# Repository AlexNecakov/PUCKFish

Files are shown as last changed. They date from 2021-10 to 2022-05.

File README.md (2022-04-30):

## Welcome to PUCKFish!
Design Team: Will Aracri, Peter Ha, Ammar Hussain, Alex Necakov, Victoria Thomas
### Please view our [wiki](https://github.com/AlexNecakov/PUCKFish/wiki) for more information, including the hardware and software READMEs!

## Introduction
PUCKFish is an underwater array of sensors meant to characterize underwater environments by sensing important information, designed for the 2021-2022 senior design project at Boston University. Originally designed to track lobsters, this device measures pressure, temperature, dissolved oxygen levels, ambient light, salinity and current speed as well as direction. The system is fully waterproof and meant to survive pressures found at a depth of around 1000 feet and survive for 10 days without a recharge. Data collection begins automatically after submersion and transmits the data collected to a base station via radio. PUCKFish can be built on a budget of around $150. This document will walk you through the PUCKFish design project, tips, and lessons learned. This document will also point you to other areas on the Github for more information about the relevant subsystems.

## Design Process
The architecture of PUCKFish optimized for two priorities, cost and survivability. From these priorities, three major challenges were identified.

1. PCB and Electronics Design: Any electronics used must have low-current draw. Electronics must also be recharged without introducing a risk of water-intrusion. Any sensors used must be low-cost.
2. Sensing Current Speed and Direction: Any method used to measure current speed and direction must be robust and simple.
3. Enclosure Design: Enclosure must be able to protect against high-pressure environments as well as protect electronics from saltwater intrusion.
Any design change should carefully consider these challenges and decide on the appropriate trade offs to achieve survivability and a low cost.

## PCB and Electronics Design
PUCKFish must read 6 different metrics from onboard sensors, store the data locally, transmit the data to a shipboard, and be rechargeable. Our software is written in C using the Arduino Framework and can be easily installed, modified, built and uploaded following instructions found on the [Software Overview](https://github.com/AlexNecakov/PUCKFish/wiki/Software-Overview) page of our wiki. Our main software can be found in the [/FlagpoleClient](https://github.com/AlexNecakov/PUCKFish/tree/master/FlagpoleClient) directory. Our electronics hardware consists of several sensors, a LiPo battery, SD card, and Adafruit Feather M0 with LoRa radio to control the system/broadcast data over the LoRa 900 mHz frequency. All of these components were put together on a custom PCB designed in Eagle. The PCB currently lacks a location for the SD card and Dissolved Oxygen sensor to be includeded, and should be added in future versions of this project. Information about our hardware, including sensor vendor links and specifications, data sheets, and renders of our PCB layouts can be found on the [Hardware Overview](https://github.com/AlexNecakov/PUCKFish/wiki/Hardware-Overview) wiki page. PCB project information can be found in the [/PCB/Eagle Project](https://github.com/AlexNecakov/PUCKFish/tree/master/PCB/Eagle%20Project) directory.

PUCKFish uses Qi wireless charging in order to replenish the battery. Using wireless charging eliminates the possibility of water-intrusion or corroded charging leads. 

PUCKFish uses several sensors to collect data. Information on the sensors may be found in the [Hardware Overview](https://github.com/AlexNecakov/PUCKFish/wiki/Hardware-Overview) page and the software mounted on them may be found in the [Software Overview](https://github.com/AlexNecakov/PUCKFish/wiki/Software-Overview) page. These sensors were selected due to price, power draw, supply voltage, measurement range, and waterproof capabilities.

PUCKFish uses a LoRa capable radio to transmit data over the 900 mHz frequency in JSON formatted packets. This radio is mounted to the Feather Board and begins sending the data once the PUCKFish has surfaced from the ocean. For more information on the radio, see the [Hardware Overview](https://github.com/AlexNecakov/PUCKFish/wiki/Hardware-Overview) page for the specifications of the hardware and the [Software Overview](https://github.com/AlexNecakov/PUCKFish/wiki/Software-Overview) page for the software that is used to collect/transmit the data.

Several sensors require access to the water to measure their respective characteristics. The pressure sensor uses a -08 O-ring to attach a vinyl tube which then leads to the exterior while pouring the epoxy. The salinity sensor uses two wire leads that sense the current produced between them, which then calculates the salinity. These wire leads must be exposed when pouring the epoxy. The dissolved oxygen sensor contains a galvanic probe. This probe must be prepped with a chemical provided from the sensor manufacturer. This probe must also be exposed while pouring the epoxy. As discussed below, silicone mold has a hole that these sensors can be routed through to ensure they will have access to water after the epoxy is poured.

## Sensing Current Speed and Direction
PUCKFish uses an IMU to measure current speed and direction. As PUCKFish is sphere, its position in the water heavily impacts the orientation and current data that is collects. Other methods of measuring current, like weather vanes or flow tubes, are too delicate and are unable to operate for long periods underwater with any degree of reliability. The design of PUCKFish’s enclosure can be found below. Information about the IMU implementation can be found in the wiki in both the [Hardware Overview](https://github.com/AlexNecakov/PUCKFish/wiki/Hardware-Overview) and [Software Overview](https://github.com/AlexNecakov/PUCKFish/wiki/Software-Overview) pages.

## Enclosure Design
PUCKFish uses a 3D Printed skeleton to hold electronic components and is encased within an epoxy shell. Sensors that need access to the water protrude from the epoxy shell in order to successfully measure the required components.

The 3D printed skeleton is the product of several steps of iteration to fit the PCB and accommodate the Qi wireless charging receiver. Once the skeleton is printed on an FDM printer with ABS filament, it requires no extra manufacturing steps. Inserting the PCB is simple as the skeleton was sized specifically to accommodate this element. For more information on the 3D printed skeleton, view relevant documentation in the [Hardware Overview](https://github.com/AlexNecakov/PUCKFish/wiki/Hardware-Overview) page.

The epoxy shell was developed specifically with survivability and cost in mind. Metallic or plastic structures containing the electronics introduce the problem of seams connecting the devices. In each of these cases, expensive manufacturing techniques, as well as complex sealing procedures, are damaging to both cost and survivability. Manufacturing the epoxy shell requires a series of two molds to form, one mold that forms the final silicone form, and the final silicone form that creates the epoxy shell. It is essential that the silicone mold is used to form the epoxy casing, as 3D printed molds are too porous for the epoxy to form in and other machined elements are too costly to make. To find the mold’s as well as the mold making process, go to the [Hardware Overview](https://github.com/AlexNecakov/PUCKFish/wiki/Hardware-Overview) page or find the relevant CAD models [/Structure Cad](https://github.com/AlexNecakov/PUCKFish/tree/master/Structure%20CAD) directory.

## Manufacturing PUCKFish
For a general description of how to manufacture PUCKFish follow the instructions below.
1. First, populate the PCB with the required components as shown in the [Hardware Overview](https://github.com/AlexNecakov/PUCKFish/wiki/Hardware-Overview)
2. Build and upload the FlagpoleClient program to the Feather Board as described in the [Software Overview](https://github.com/AlexNecakov/PUCKFish/wiki/Software-Overview)
3. 3D print the PCB skeleton for the electronics.
4. 3D print the silicone mold molds.
5. Pour the silicone molds for epoxy. 
6. Install the populated PCB into the 3D printed skeleton
7. Install the aluminum block into the top of the 3D printed skeleton with epoxy
8. Screw in the eyebolt to the aluminum block.
9. Install the 3D printed skeleton with populated PCB into the silicone mold, with the eyebolt pointed through the mold.
10. Pour epoxy into the silicone mold in three parts. DO NOT POUR EPOXY IN ONE BATCH (The heat for the epoxy may damage electrical components)
11. Wait three days in between epoxy cures. The device is ready to operate after charging after the last cure period.

## Operation
See our [wiki](https://github.com/AlexNecakov/PUCKFish/wiki) or [Users Manual](https://github.com/AlexNecakov/PUCKFish/blob/master/Reports/Users%20Manual.docx) for additional information on how to operate PUCKFish.

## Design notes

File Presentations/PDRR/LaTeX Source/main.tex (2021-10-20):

% This is a template for BU-ECE Technical Report.
%
% Depending on report content and author preference, a BU-ECE report may be
% in one of the two following styles:
%
%   - genuine report based on ``report'' style, i.e., with chapters, much like
%     a thesis; can be single- or double-sided,
%
%   - report based on ``article'' style, i.e., with no chapters (only sections,
%     subsections, etc.), much like a journal or conference paper; can be
%     single- or double-sided.

% =====================================================================

%\documentclass[12pt]{report}          %Single-sided report style (chapters)
%\documentclass[12pt,twoside]{report}  %Double-sided report style (chapters)
\documentclass[12pt]{article}         %Single-sided article style (no chapters)
%\documentclass[12pt,twoside]{article} %Double-sided article style (no chapters)

\usepackage{bu_ece_report}

\usepackage{graphicx}
\graphicspath{}

\usepackage{dblfloatfix}

\usepackage{makecell}

\usepackage{tikz}
\def\checkmark{\tikz\fill[scale=0.4](0,.35) -- (.25,0) -- (1,.7) -- (.25,.15) -- cycle;} 

\usepackage{colortbl,dcolumn}

% In case an adjustment of vertical or horizontal margins is needed
% due to particular LaTeX/dvips or OS installation, you can uncomment
% and edit the following definitions.
% -------------------------------------------------------------------
%\topmargin       0.00 in
%\oddsidemargin   0.50 in
%\evensidemargin  0.00 in

\begin{document}

% Definitions.
% ------------
\buecedefinitions%
        {PUCKfish Product Definition and Requirements Review}
        {PUCKfish PDRR}
        {William Aracri, Peter Ha, Ammar Hussain, Alex Necakov, Victoria Thomas}
        {10/7/21}
        {2021-NN} % Number of the report (four year digits and number)
        
\pagenumbering{roman}

% Title page
% (adds an empty page in double-sided printing mode).
% ---------------------------------------------------
\buecereporttitlepage

% Special page, e.g., if the report is restricted or
% to whom it is dedicated, etc., otherwise skip.
% (adds an empty page in double-sided printing mode).
% ---------------------------------------------------
\bueceprefacepage{Drunk Drivers / North American Right Whales}

% Table of contents, list of figures and list of tables.
% ``\bueceemptypage'' adds empty page in double-sided
% printing mode and performs ``\clearpage'' in single-sided
% mode.
% ------------------------------------------------------
\tableofcontents
\vspace{50px}
\listoffigures
\listoftables\bueceemptypage

% Switch on running headers for the report:
%   odd pages  - title (lowercase); if too long, use
%                the first few words followed by ``...'',
%   even pages - last names of the authors.
% -------------------------------------------------------
\buecereportheaders

% Report summary; max. 1 page.
% (adds an empty page in double-sided printing mode).
% ---------------------------------------------------
%\setlength\parindent{24pt}
\pagenumbering{arabic}
\setcounter{page}{1}
\buecereportsummary{There are less than 400 North American Right Whales remaining in the ocean today. Unfortunately, 34 of these endangered creatures have died of unnatural causes since 2017, and lobster trap entanglement and fishing vessel collisions are the leading causes of these deaths. Our company, Fathom Fishing, is looking for your help in developing the PUCKFish, an underwater sensor device, with the goal of eventually ridding the sea of entanglement-prone lobster-fishing lines and allowing fishermen to make fewer, more-efficient trips to their traps. The PUCKFish data collection kit consists of a base station (to be mounted on fishing vessels) and several small sensing devices (to be mounted on or near individual lobster traps). In the long term, these devices will allow fishermen to wirelessly locate and hoist their traps up from the ocean floor without needing to leave location-marking buoy lines floating where they can harm whales and other sea life. The first revision of the PUCKFish, however, will simply collect temperature, depth, dissolved oxygen, and other measurements of the water surrounding a deployed lobster trap. As soon as a fisherman pulls the trap above the surface, the PUCKFish will wirelessly upload the collected data to the onboard base station. Fishermen can then use this data to determine the locations and water conditions in which they’ll catch the biggest haul, reducing the number of trips needed to reach their legal sustainable catch limit, and marine biologists can use this data to track sea life conservation efforts.}

\twocolumn

% Following sections, subsections, etc.
% -------------------------------------
\section{Need for this Project}

\par Due to hundreds of years of overfishing and mass pollution of the oceans, the pollution of right whales has decreased drastically. Whales play an important role in the environment, keeping other eat populations in check by eating “small fish, krill, larvae, copepods, pteropods, zooplankton, cyprids, euphausiids and other small invertebrates”. \cite{whalefacts:2015} Additionally, whale populations provide an important role in reducing atmospheric carbon as their excrement is the main source of food for oxygen producing phytoplankton. \cite{sapir:2021}

\par Currently, the leading cause of death in the critically endangered North Atlantic Right Whale is “entanglements and vessel strikes.” \cite{noaa:2021} \cite{noaa:2021_2} This issue has caused legislation such as the Atlantic Coastal Fisheries Cooperative Management Act which effectively illegalizes lobster fishing in large areas of the Atlantic Coast. \cite{congress:1981} \cite{congress:1981_2} To protect these animals, lobster fishermen will have to invest in technologies which reduce lobster line pollution. One solution to this issue will be the PuckFish. As our device will provide fishermen with the information to better approximate the location of lobsters, they will be able to place fewer traps, more effectively, directly decreasing the chances of whale entanglement. 

\section{Problem Statement and Deliverables}

\subsection{Problem Statement}

\par There is a current lack of data available to lobster catchers. Existing solutions use out of date technology, and give almost none of the data critical to deciding trap placement. This leads to an overabundance of traps in areas with very little yield, leading to efficiency losses for the lobster catchers, and creating greater pollution in the form of fishing lines connecting the traps to each other and buoys. 
\par Our solution simultaneously solves each of these problems, giving trappers the data most useful in locating lobsters, including dissolved oxygen, soil softness, and temperature. By allowing lobster catchers to easily access these measurements, they can place fewer traps with greater yield. This data will then be collected to create among the most robust oceanographic databases, updated far more regularly and over a wider area than existing databases. 

\subsection{Deliverables}

A set of three sensing devices capable of: 
\begin{enumerate}
    \item Measuring:
    \begin{enumerate}
        \item Temperature
        \item Dissolved oxygen
        \item Salinity
        \item Current speed and direction
        \item Depth
        \item Ambient light
    \end{enumerate}
    \item Transmitting the Collected Data:
    \begin{enumerate}
        \item On the surface
        \item 1 MB at 50 kb/s from 50 ft away
        \item Polling rate of 1/hr - 1/min
    \end{enumerate}
\end{enumerate}

A base station capable of: 
\begin{enumerate}
    \item Receiving data at the above rates
    \item Storing data on an SD card in CSV format
    \item Withstand exposure to constant marine conditions
\end{enumerate}

\section{Visualization}  % Article style

\begin{figure}[h]
    \centering
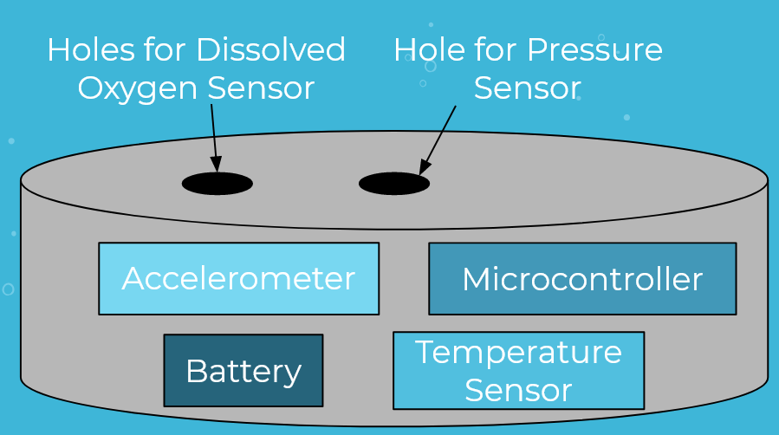
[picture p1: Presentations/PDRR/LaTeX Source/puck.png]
    
    \caption{Puck, Data Collection Device}
    \label{fig:my_label}
\end{figure}

\begin{figure}[h]
    \centering
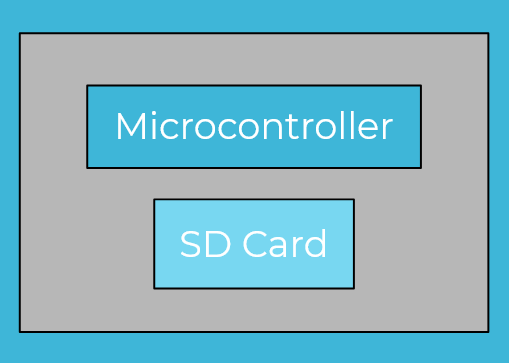
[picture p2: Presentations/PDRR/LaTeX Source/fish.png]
    
    \caption{Base Station}
    \label{fig:my_label}
\end{figure}

\section{Competing Technologies}  % Article style

\begin{table*}[!b]
    \begin{center}
        \begin{tabular}{|c|c|c|c|c|c|c|c|}
            \hline
            Product & \thead{Dev. Time\\(Months)} & Temp. & \thead{Dis.\\Ox.} & Depth & Salinity & Current & \thead{Ambient\\Light} \\
            \hline
            PUCKfish & 6 & \cellcolor{green} \cellcolor{green} \checkmark & \cellcolor{green} \checkmark & \cellcolor{green} \checkmark & \cellcolor{green} \checkmark & \cellcolor{green} \checkmark & \cellcolor{green} \checkmark \\
            \hline
            \hline
            Major Competitors: & & & & & & & \\
            \hline
            TimeZero & 6 & \cellcolor{red} $\times$ & \cellcolor{green} \checkmark & \cellcolor{green} \checkmark & \cellcolor{green} \checkmark & \cellcolor{green} \checkmark & \cellcolor{red} $\times$ \\
            \hline
            eMOLT & 0 & \cellcolor{green} \checkmark & \cellcolor{red} $\times$ & \cellcolor{red} $\times$ & \cellcolor{green} \checkmark & \cellcolor{green} \checkmark & \cellcolor{red} $\times$ \\
            \hline
            \hline
            Minor Competitors: & & & & & & & \\
            \hline
            LobsterNet & 14 & \cellcolor{green} \checkmark & \cellcolor{green} \checkmark & \cellcolor{green} \checkmark & \cellcolor{red} $\times$ & \cellcolor{red} $\times$ & \cellcolor{red} $\times$ \\
            \hline
            OSU & 0 & \cellcolor{green} \checkmark & \cellcolor{green} \checkmark & \cellcolor{red} $\times$ & \cellcolor{red} $\times$ & \cellcolor{red} $\times$ & \cellcolor{red} $\times$ \\
            \hline
            \hline
            Non-Competitors: & & & & & & & \\
            \hline
            LasTrap & 0 & \cellcolor{red} $\times$ & \cellcolor{red} $\times$ & \cellcolor{red} $\times$ & \cellcolor{red} $\times$ & \cellcolor{red} $\times$ & \cellcolor{red} $\times$ \\
            \hline
            LobsterLift & 8 & \cellcolor{red} $\times$ & \cellcolor{red} $\times$ & \cellcolor{red} $\times$ & \cellcolor{red} $\times$ & \cellcolor{red} $\times$ & \cellcolor{red} $\times$ \\
            \hline
        \end{tabular}
        \caption{Competing Technologies}
        \label{tab:my_label}
    \end{center}
\end{table*}

\par The PUCKFish has competitors that the team has grouped into three separate groups as determined by their requirements and features. The first of these three groups, Non-Competitors, exhibits similar goals to PUCKFish, but does not solve these problems in a similar way that competes with PUCKFish. The second group of competitors is called Minor Competitors. Minor Competitors have projects with the same goal of measuring the environment of the Lobster trapping industry, but do not include all of the features that are unique to PUCKFish. The final group is called Major Competitors. Major Competitors include most features that PUCKFish does and have the largest weight on the requirements of our design and outline the niches that PUCKFish situates itself in.

\subsection{Major Competitors}
\subsubsection{TimeZero}
\par TimeZero is a large-scale service that provides a variety of data from all over the world.  Professional fishermen can select the services they require, although they do not collect ambient light measurements. TimeZero is a worldwide presence, which means that their focus varies and is not necessarily centralized to the Lobster industry in the northeast. PUCKFish should collect the same variety of information, while maintaining its niche with lobster nets.

\subsubsection{eMOLT}
\par eMOLT is a network of data collection equipment deployed on lobster traps. The data is collected by the fisherman community and then updated and available on a public form to see. eMOLT is the closest competitor and carries out essentially the same functions as PUCKFish. In order to improve upon this existing design, depth, ambient light, and most importantly, dissolved oxygen levels must be collected. In addition, the infrastructure and data provided must be more readily readable or translatable.

\subsection{Minor Competitors}
\subsubsection{Oregon State University Data Collection System}
\par Oregon State University developed a small micro controller to collect temperature and dissolved oxygen levels. The last update of this project was in 2009. PUCKFish must at least take temperature and dissolved oxygen levels at a depth, and do so better with more fidelity as it is newer.

\subsubsection{LobsterNet}
\par LobsterNet is a project incubated by Gloucester Innovation and powered by the Canadian company Sigfox. It collects live data in the form of temperature, oxlevel, pH, depth, and location. PUCKFish must collect at a minimum these data points. PUCKFish will not collect data live because, as shown by LobsterNet, a large infrastructure must be put into place to achieve successful implementation. LobsterNet was announced in 2019 with very little information or updates coming out since then.

\subsection{Non-Competitors}
\subsubsection{LobsterLift}
\par LobsterLift is a lobster trap that lifts itself with no lead line. This feature helps with one of the possible features of PUCKFish, but contains no sensor information relaying fisherman useful data. As a result, PUCKFish should not attempt to develop a self lifting capability until other sensor technology is implemented successfully.

\subsubsection{LasTrap}
\par LasTrap is a novel lobster trap made out of plastic leading to more resilient traps with the possibility of introducing further innovations. However, LasTrap does not include sensors, information collectors, or active components. PUCKFish is deployed on existing traps, so LasTrap does not have any impact based upon the requirements already presented.

\section{Engineering Requirements}  % Article style

PUCKfish Sensor Collection Device:
\begin{enumerate}
    \item Mechanical
    \begin{enumerate}
        \item The device must operate at 1100 ft below sea level, at pressures of over 34 atm
        \item The device must have ports for sensor access to water and user access to sensors
        \item The device must be waterproof and capable of surviving harsh, undersea conditions
    \end{enumerate}
    \item Data Collection
    \begin{enumerate}
        \item The device must collect data for the following measurements at a rate of at least one reading per hour:
        \begin{enumerate}
            \item Temperature
            \item Dissolved oxygen
            \item Salinity
            \item Current speed and direction
            \item Depth
            \item Ambient light
        \end{enumerate}
    \end{enumerate}
    \item Transmission
    \begin{enumerate}
        \item The device must detect when it has submerged/surfaced to begin transmitting to the base station
        \item Device must be able to wirelessly transmit when trap surfaces (1 MB at 50 kb/s from 50 ft away)
    \end{enumerate}
    \item Power
    \begin{enumerate}
        \item Device must be easily rechargeable, getting power from onboard lead acid marine batteries
        \item Device must last on a single charge for up to 10 days
    \end{enumerate}
    \item Cost
    \begin{enumerate}
        \item The prototype for the device must not exceed \$150, and should cost \$50 or less when produced at scale
    \end{enumerate}
\end{enumerate}

Base Station:
\begin{enumerate}
    \item Mechanical 
    \begin{enumerate}
        \item The Base Station must be able to withstand frequent splashes of saltwater, heavy rain, and other harsh marine conditions
    \end{enumerate}
    \item Data Collection
    \begin{enumerate}
        \item The Base Station must receive data as PUCKFish transmits, saving the data in CSV format
        \item The Base Station must store data on a SD card so data can be easily transferred to other systems for data analysis
    \end{enumerate}
    \item Power
    \begin{enumerate}
        \item The Base Station must be able to be powered off of onboard lead acid marine batteries, accepting voltages in anywhere in the range of 11-14V
    \end{enumerate}
\end{enumerate}

\section{Appendix A: References}  % Article style

% Bibliography.
% -------------
\parskip=0pt
\parsep=0pt
\bibliographystyle{ieeetrsrt}

% Important: substitute your BiBTeX (*.bib) files below.
% ------------------------------------------------------
\bibliography{bib.bib}

\end{document}

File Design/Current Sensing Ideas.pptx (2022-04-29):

## Mechanical

- Essentially windvanes, using a pivoting, overstable wing to determine current direction
- Sense speed using a rotor that is spun by the current
- Mechanically very simple
- Creates more points of failure
- Very achievable to manufacture
- Likely to be the first component on PUCKfish to fail

## IMU

- IMU returns approximation of current based on puck’s movement on a cable
- Simplest possible implementation mechanically
- Gives relatively poor accuracy for current speed
- Would need to derive relationship between puck movement and current

## Acoustic Doppler Sensors

- Device emits low frequency sound, which then scatters in the water.
- Several microphones use both the return frequency and time difference between microphones to determine current speed and direction
- State of the art
  - Most accurate
  - Most expensive
- Complicated to design and manufacture in house
- Expensive to purchase COTS

## EM Sensing

- An inductor, exposed to the current, generates an oscillating magnetic field
- A voltage is induced by the moving seawater within the inductor
- This oscillating voltage is then measured, giving the current speed in the direction of the induced magnetic field
- Mechanically extremely simple
- Could give direction with the addition of a second, perpendicular inductor
- Unclear what magnitude the voltage changes will be
- Potentially difficult to model
- Could require greater power draw than other alternatives, due to the magnetic field

## Source

Williams, Albert. Current Measurement Technology Committee of the Oceanic Engineering Society of IEEE. 1/1/08. https://www.hydro-international.com/content/article/ocean-current-measurements-a-review.

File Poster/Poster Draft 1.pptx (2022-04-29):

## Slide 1

William Aracri, Peter Ha, Ammar Hussain, Alex Necakov, Victoria Thomas

Electrical and Computer Engineering Department, Boston University, Boston, Massachusetts 02215

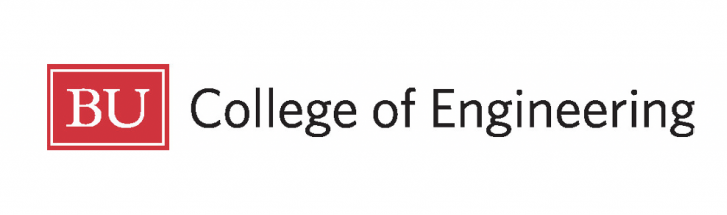
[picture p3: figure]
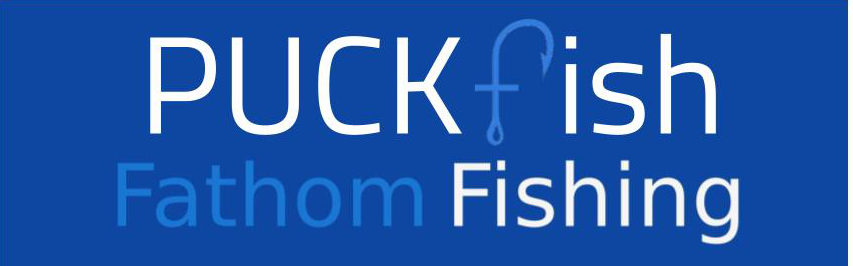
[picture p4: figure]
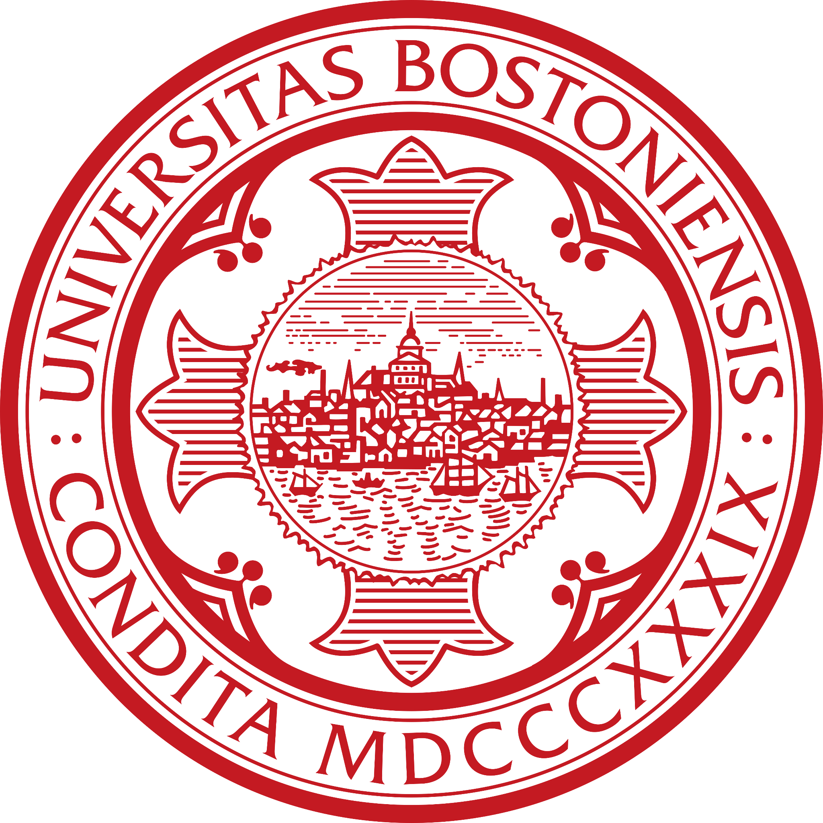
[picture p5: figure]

Executive Summary

The lobster fishing industry has largely remained unchanged since its emergence in the mid 1800s. The primary strategy for lobster fishing has also remained unchanged since the mid 1800s, where fishermen place traps upon habitual routes with no promise of a good catch yield This strategy leads fishermen to place extraneous traps throughout the ocean in areas unlikely to house lobsters. These extraneous traps have a significant environmental impact on other marine life such as the endangered North American Right Whale. The whales become caught in the lines of lobster traps and then perish, making “line entanglement” the leading cause of unnatural death among this population. Due to these environmental concerns, fishermen are limited by law in the number of traps they can place.
PUCKFish solves this by providing low-cost, rugged instrumentation to fisheries. This device puts the tools for data acquisition and analysis in the hands of trappers providing information to inform data-backed decisions about where to place lobster traps and optimizing fishing hauls. We will be producing three PUCKFish data collection devices each of which records six key metrics relevant to lobster activity on the seafloor. PUCKFish will be the first business-grade, all-in-one data collection and analysis suite specifically for lobster fishermen. Its low cost and ability to collect metrics most critical to locating and tracking lobsters will revolutionize the lobster fishing industry.

Device Design

Each PUCKFish device comes pre-built with no assembly required. The device needs to be charged using a Qi wireless charging pad. The device must be attached to a lobster trap line with the eye-bolt with enough slack for it to drift about underwater. The PUCKFish should be fully charged before use and the exterior sensor ports must not be obstructed to ensure full data collection and recovery. Software will automatically run on the PUCKFish while it is powered on. Receiving data from the PUCKFish will require users to run Fathom Fishing’s base station software.
For the dissolved oxygen sensor, the galvanic probe requires periodic recalibration with an electrolyte solution. Over time, this solution will be depleted and will eventually need to be refilled. To refill the probe, enough of the probe needs to be exposed to allow for the cap to be removed to refill the solution. When filling the solution, the user must use a standard syringe to fill the cap to its brim with the solution. Once The solution is filled, the cap must be properly screwed back on to ensure no leakage and to prevent corrosion.

Figure3: System Block Diagram

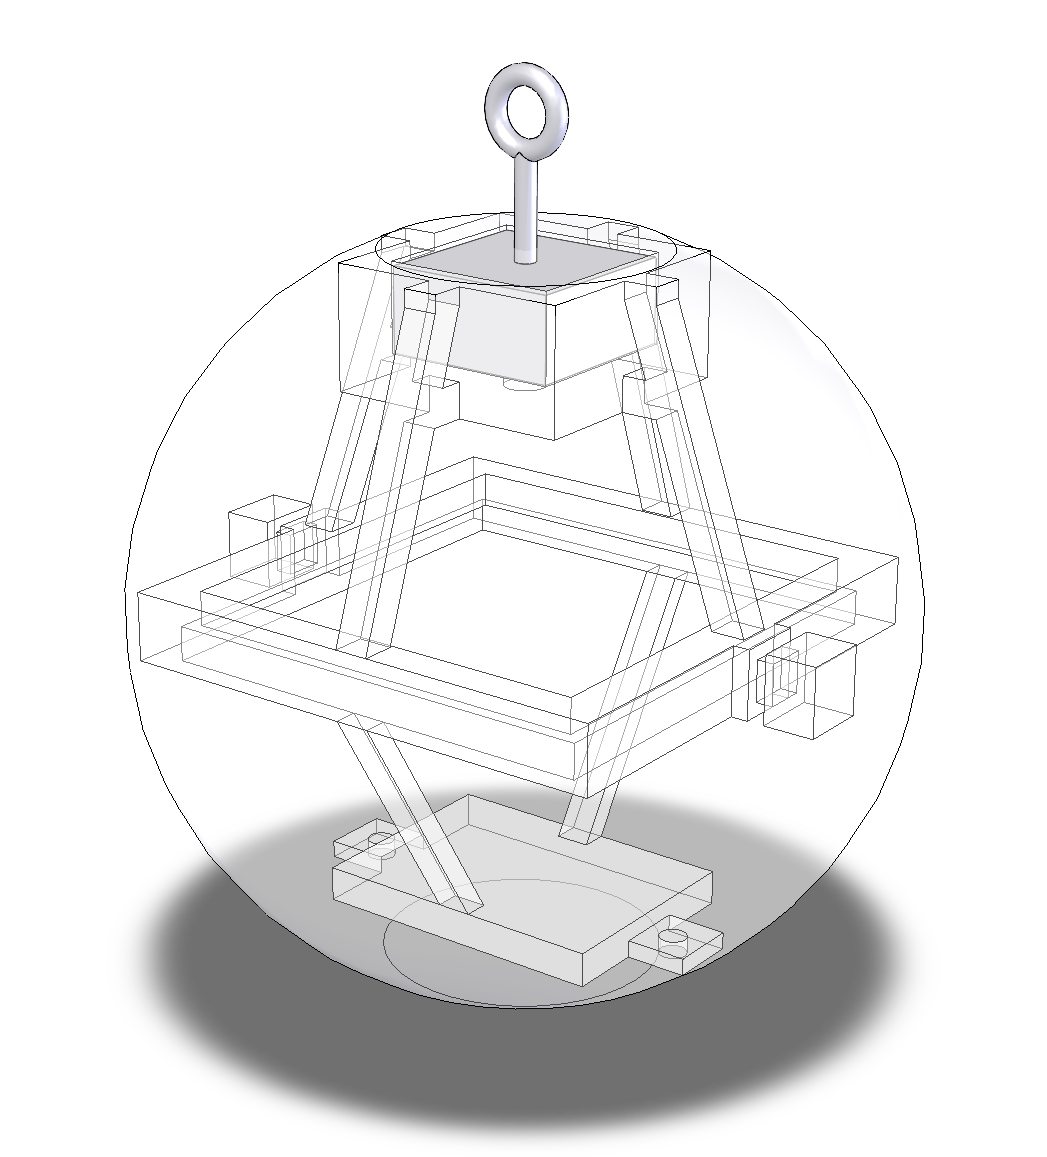
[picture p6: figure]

Figure 1: Skeleton and Mold Model

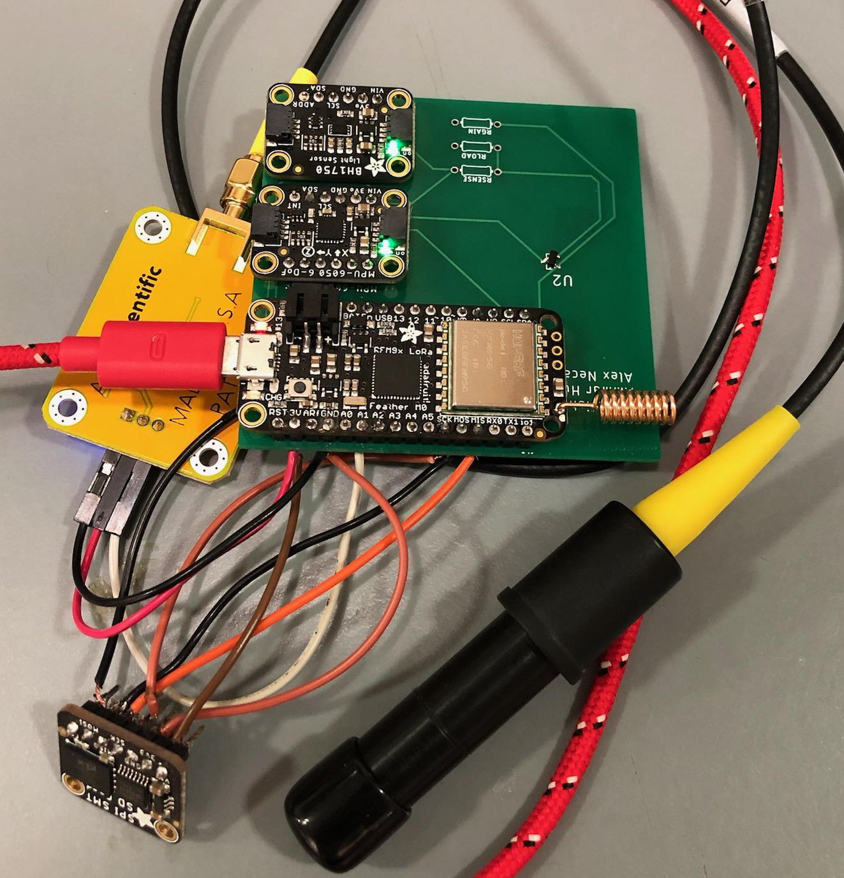
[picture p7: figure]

Figure 2: PCB with Sensors

Environmental Impact

Conclusion

Insert conclusion here

Table 1: Project Costs for Production of Beta Version (Next Unit after Prototype)
Item | Quantity | Description | Unit Cost | Extended Cost
Epoxy Resin and Hardener | 0.183 Gal | Two part epoxy mixture, of a 1.5 Gal kit | $172.78 | $21.08
3D Printed Skeleton | 1 | Skeleton mount for PCB, sensors, eyebolt mount | $10 | $10
Eyebolt | 1 | Eyebolt for tying to trap | $1.50 | $1.50
Aluminum Eyebolt Mount | 1 | Aluminum block for skeleton mount, drilled and threaded for eyebolt | $15 | $15
PCB | 1 | | $4.60 | $4.60
Dissolved O2 Sensor | 1 | | $152.99 | $152.99
Light Sensor | 1 | | $1.06 | $1.06
IMU | 1 | | $7.78 | $7.78
Salinity Sensor | 1 | | $0.90 | $0.90
Temperature and Pressure Sensor | 1 | | $30 | $30
Beta Version-Total Cost | | | | $244.91

Sensor Requirements

1. Temperature
  a. Different marine species prefer different temperatures in relation to their body temperature to function optimally. Temperature can affect basic biological processes such as metabolism, reproduction, and growth.
2. Depth
  a. Pressure differences affect the physiological structure of marine life. Fish or animals may be better suited to either higher or lower pressures depending on their role in the ecosystem.
3. Ambient Light
  a. Marine plant life depends upon photosynthesis to produce energy. As plant life or algae are commonly the base of the ecosystem, different light amounts may point to more dense populations of plant life, and thus, other forms of marine life.
4. Dissolved Oxygen
  a. Marine life extracts dissolved oxygen from water in order to maintain biological function. The amount of oxygen available in the water tends to increase proportionally with the availability of marine life
5. Current Speed and Direction
  a. Current speed and direction can show migration patterns as well as still spots where habitats can form without the force of the current moving them around.
6. Salinity
  a. Salinity affects marine life, as they typically have optimal ranges in which they prefer to reside. The biological effects of salt impact functions like osmosis and metabolic processes which are key processes that sustain life for aquatic life.

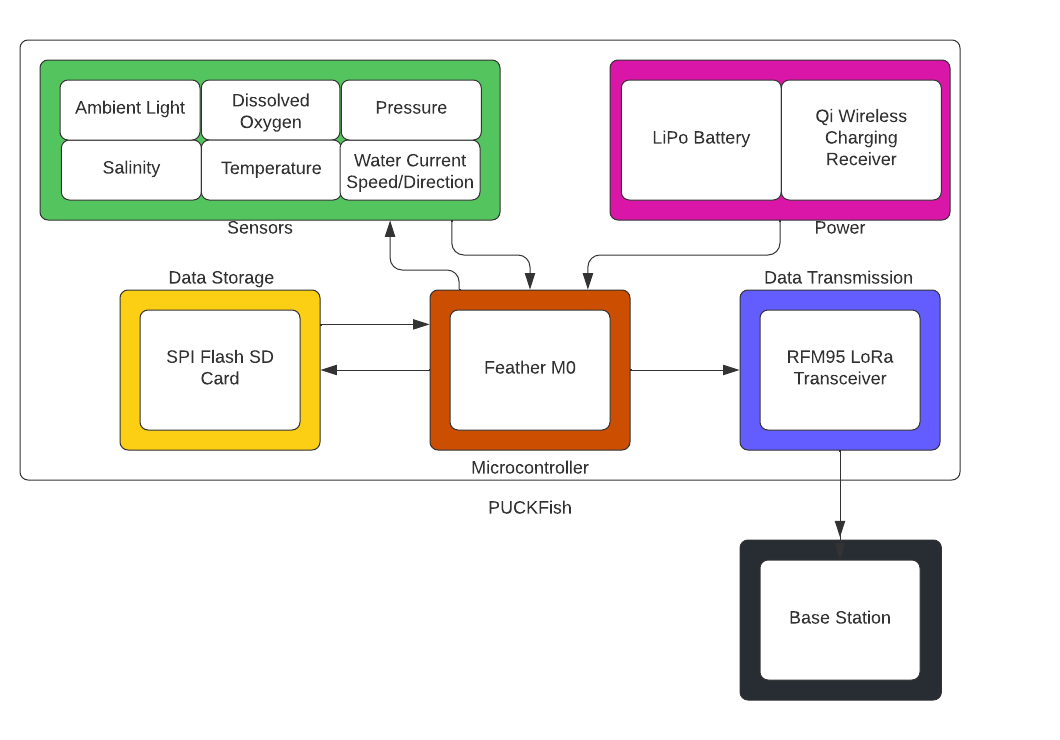
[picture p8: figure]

Future Direction

Insert future direction here

Acknowledgments

We would like to thank our customers, Andy Whitman and Anthony Byrne at Fathom Fishing. Additionally we would like to thank our ECE advisor team, principally Professor Osama Alshaykh and Professor Pisano.

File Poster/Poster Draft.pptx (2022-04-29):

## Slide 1

William Aracri, Peter Ha, Ammar Hussain, Alex Necakov, Victoria Thomas

Electrical and Computer Engineering Department, Boston University, Boston, Massachusetts 02215


Executive Summary

- Lobster trappers utilize almost no data and place traps on dead reckoning alone
- PUCKFish provides cheap, rugged instrumentation to fisheries
- Provides the tools to catch larger hauls with fewer traps and less time at sea
- Collects the 6 metrics most predictive of aquatic life
  - Dissolved oxygen, temperature, pressure, ambient light, salinity, and water current
- Underwater battery life of 10 days
- Charged wirelessly via Qi
- Local storage protects data in case of battery death
- Automatically detects surfacing and transmits data to base station

Device Design

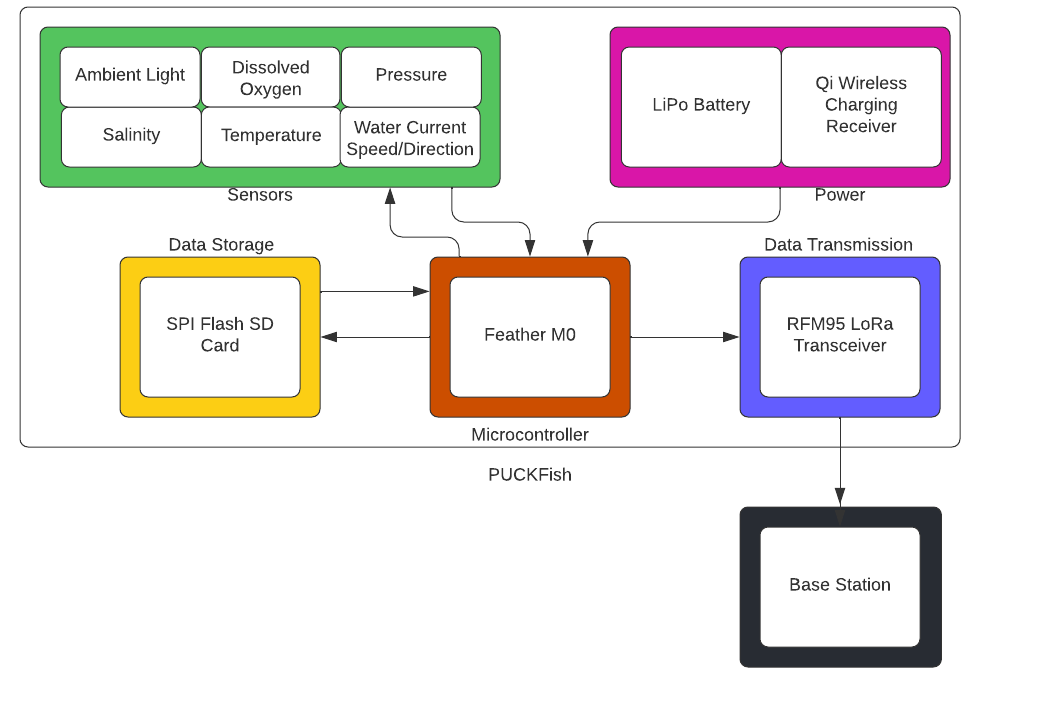
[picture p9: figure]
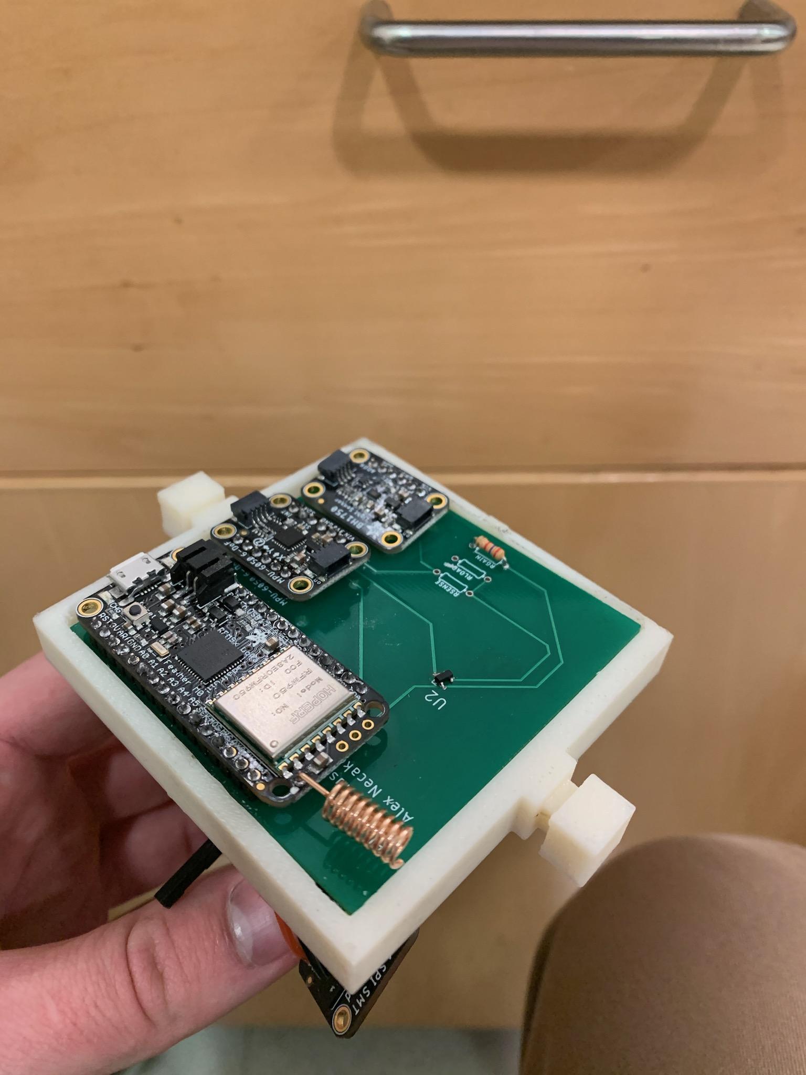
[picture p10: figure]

Environmental Impact

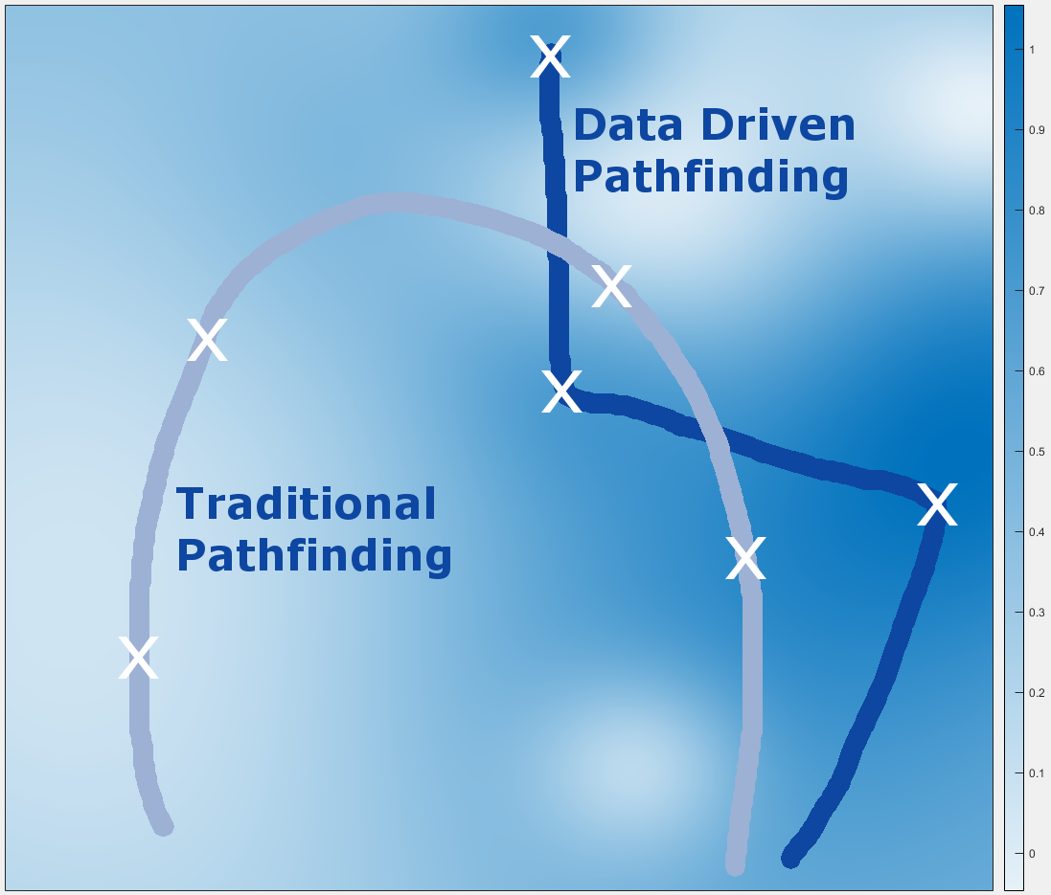
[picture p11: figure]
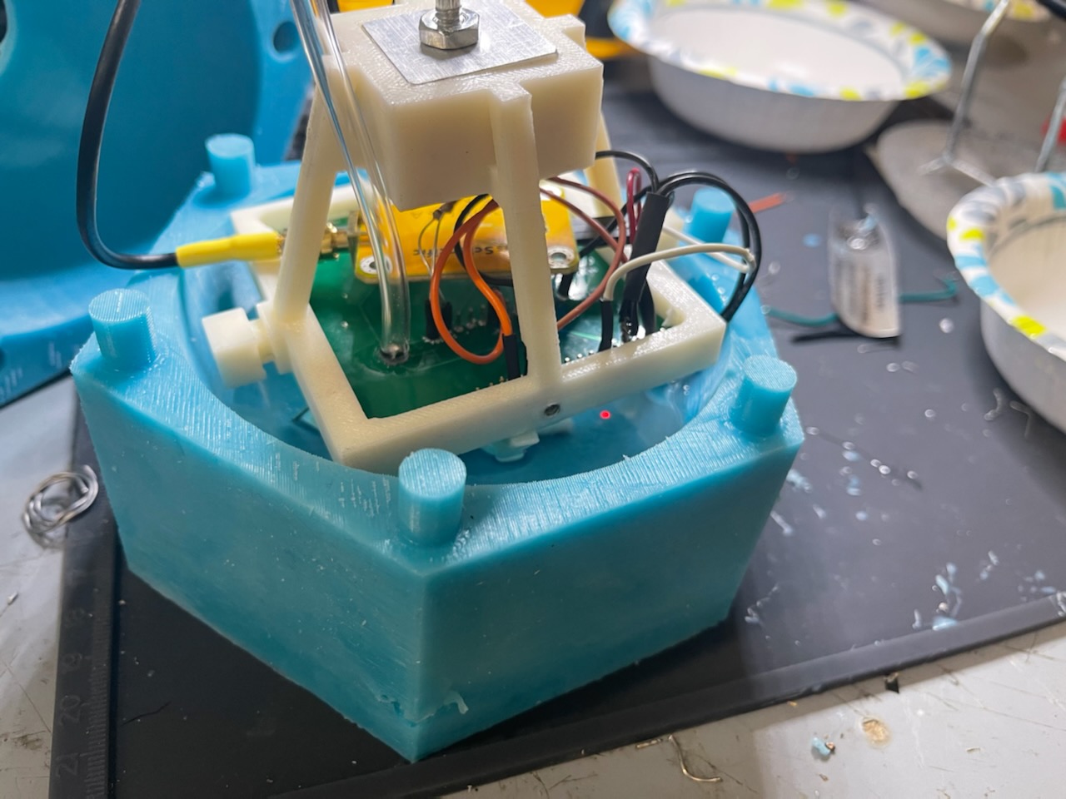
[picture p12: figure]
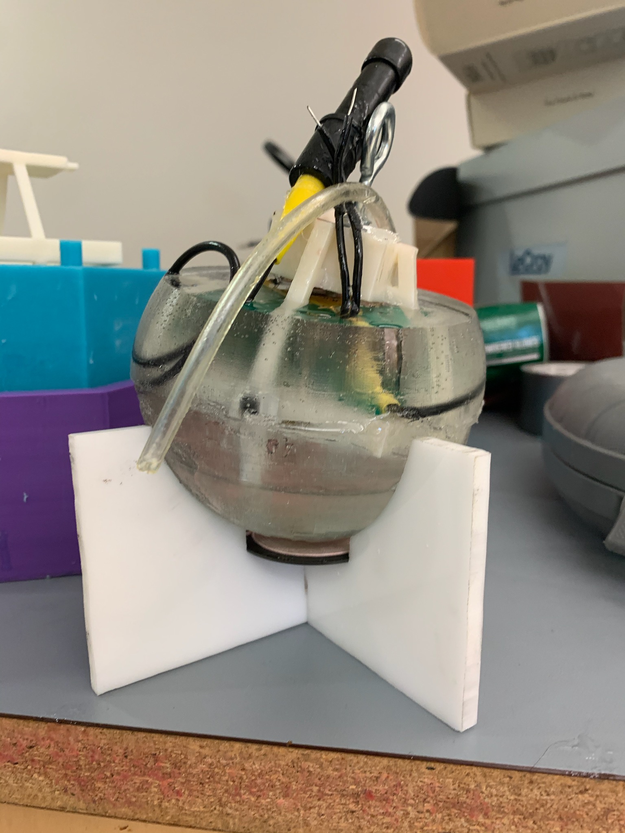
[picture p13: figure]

Visualization

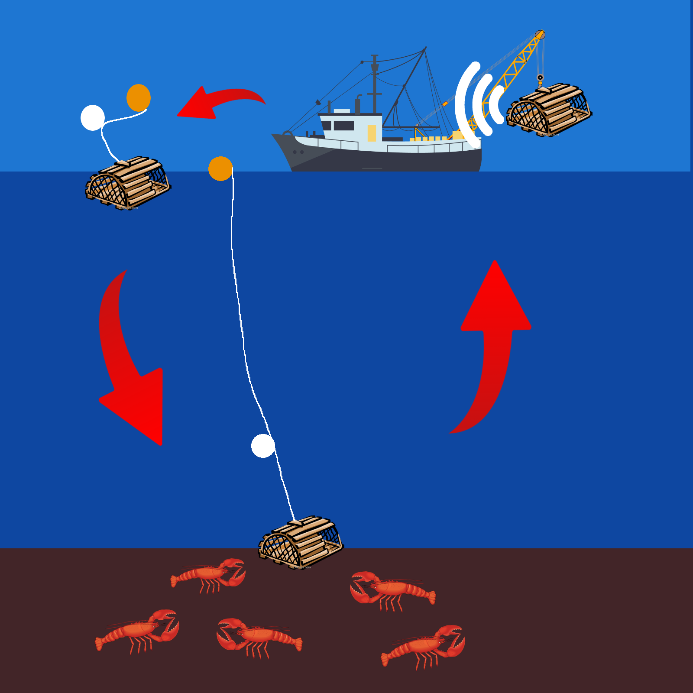
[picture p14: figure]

Conclusion

- PUCKFish increases trap yield while decreasing operating costs and environmental impact
- Automated data collection and transmission make the user experience completely painless, with trappers only needing to charge PUCKFish after use

Future Direction

- Future implementations of the PUCKFish will improve cost by using a cheaper radio module, as LoRa is not needed for the expected transmission distances
- The polling rate to collect data on the boards can be adjusted on later units to pull more or less frequently depending on the needs of the customer

Acknowledgments

We would like to thank our customers, Andy Whitman and Anthony Byrne at Fathom Fishing. Additionally we would like to thank our ECE advisor team, principally Professor Osama Alshaykh and Professor Pisano.

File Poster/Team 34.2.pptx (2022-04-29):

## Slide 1

William Aracri, Peter Ha, Ammar Hussain, Alex Necakov, Victoria Thomas


Visualization


Device Design


Environmental Impact

Title of this picture

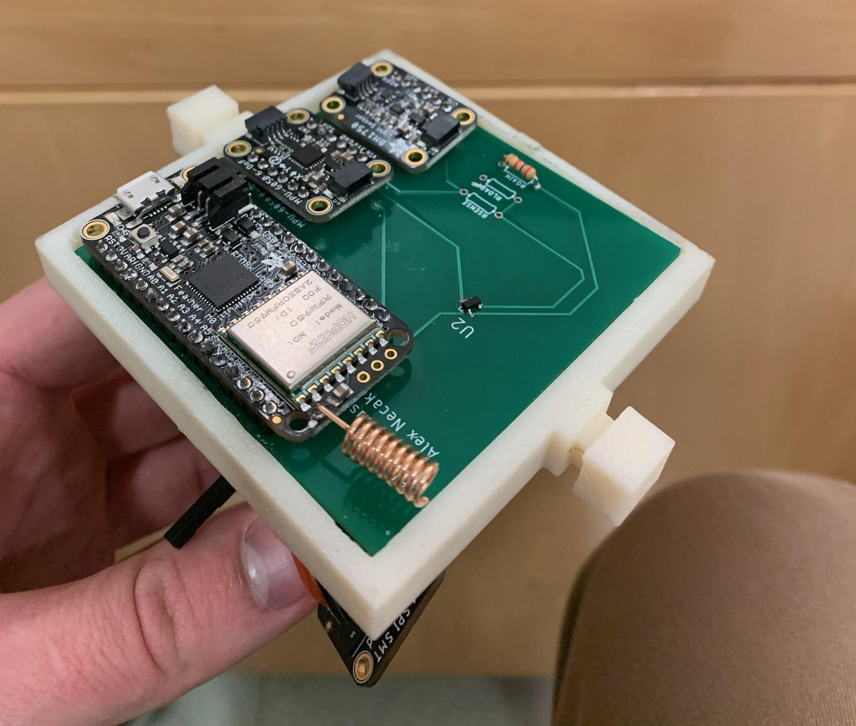
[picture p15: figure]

Conclusion

- PUCKFish increases trap yield while decreasing operating costs and environmental impact
- Automated data collection and transmission make the user experience completely painless, with trappers only needing to charge PUCKFish after use

Executive Summary

- Lobster trappers utilize almost no data and place traps on dead reckoning alone
- PUCKFish provides cheap, rugged instrumentation to fisheries
- Provides the tools to catch larger hauls with fewer traps and less time at sea
- Collects the 6 metrics most predictive of aquatic life
  - Dissolved oxygen, temperature, pressure, ambient light, salinity, and water current
- Underwater battery life of 10 days
- Charged wirelessly via Qi
- Local storage protects data in case of battery death
- Automatically detects surfacing and transmits data to base station


Future Direction

- Future implementations of the PUCKFish will improve cost by using a cheaper radio module, as LoRa is not needed for the expected transmission distances
- The polling rate to collect data on the boards can be adjusted on later units to pull more or less frequently depending on the needs of the customer

PUCKfish Video

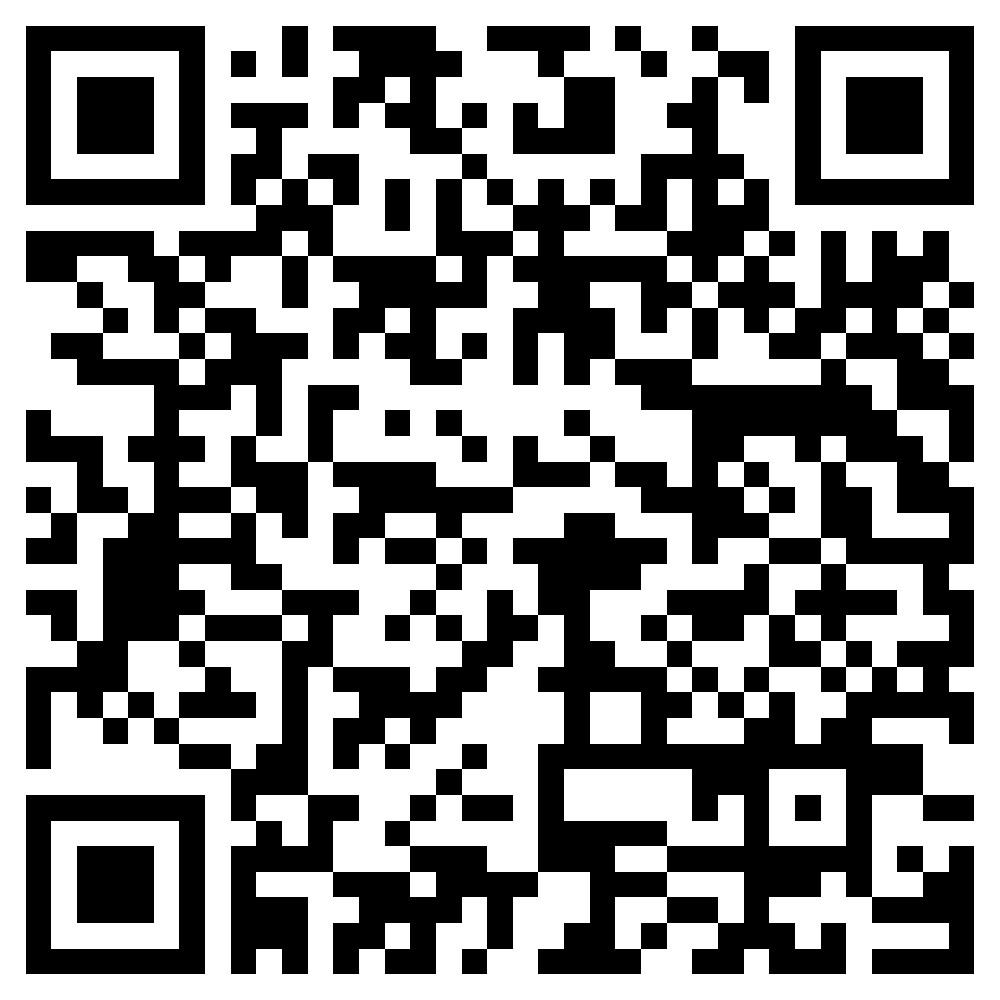
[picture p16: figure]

User’s Manual

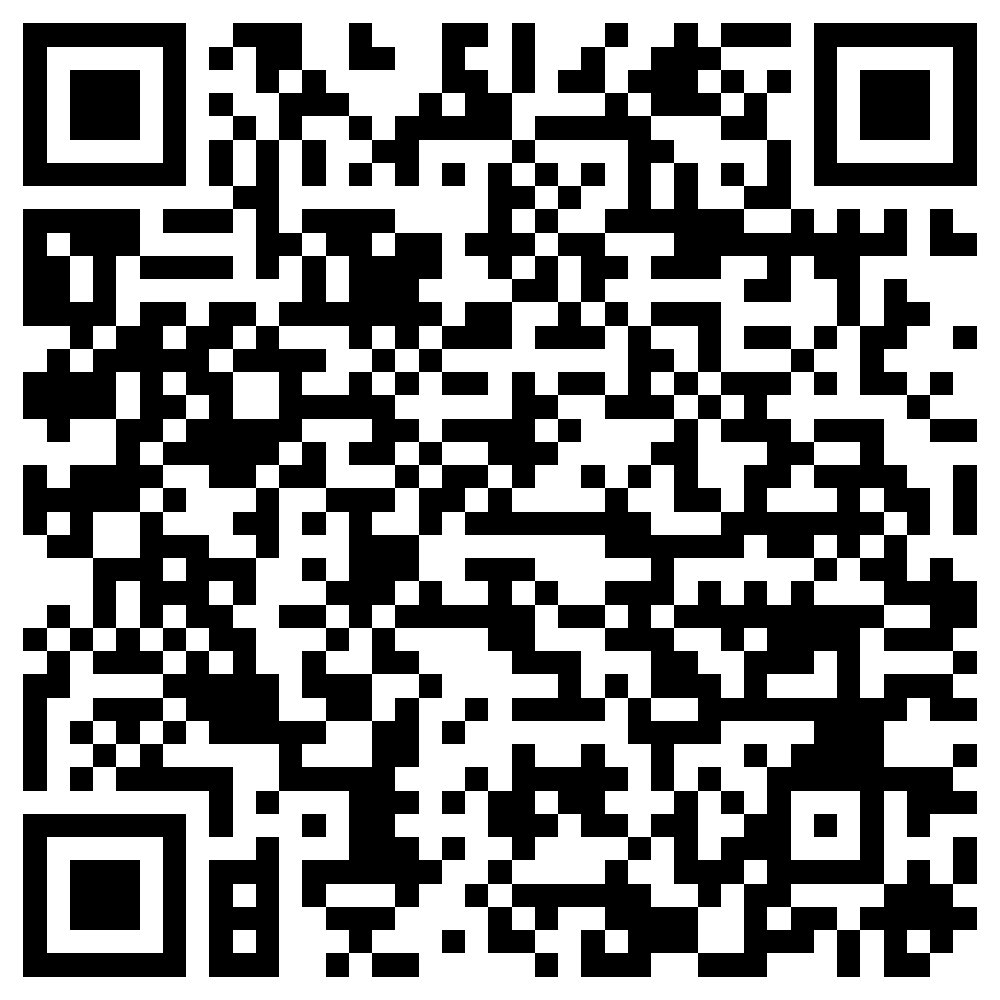
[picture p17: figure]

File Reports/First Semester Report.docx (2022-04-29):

Boston University

Electrical & Computer Engineering

EC463 Senior Design Project

First Semester Report

Submitted to

Andy Whitman and Anthony Byrne

Fathom Fishing

andy@fathom.fishing

abyrne19@bu.edu

by

Team 34

PUCKFish

Team Members

Will Aracri waracri@bu.edu

Ammar Hussain hussaina@bu.edu

Peter Ha peterha@bu.edu

Alex Necakov alexrn@bu.edu

Victoria Thomas vmthomas@bu.edu

Submitted: 12/12/2021

Table of Contents

Executive Summary 3

1.0 Introduction 3

2.0 Concept Development 5

3.0 System Description 8

4.0 First Semester Progress 10

4.1 Developing and Defining Project Requirements 10

4.2 Research and Development of Conceptual Design 11

4.3 Testing, Implementation, and Planning 12

5.0 Technical Plan 13

5.1 Introduction 13

5.2 Technical Plan 13

5.2.1 Test 3.1 (12/02 - 2/10) 13

5.2.2 Test 2.2: Sensor Array Test (01/02 - 01/28) 14

5.2.3 Test 3.2: Full Hardware Test (01/28 - 02/10) 15

5.2.4 Test 4: Full PUCKFish Functionality Testing (02/10 -04/30) 17

5.2.5 Final Administrative Items (04/30 - 05/18) 18

6.0 Budget Estimate 18

7.0 Attachments 20

7.1 Appendix 1 – Engineering Requirements 20

7.2 Appendix 2 – Gantt Chart 21

7.3 Appendix 3 – Other Appendices 21

# Executive Summary

PUCKFish

Team 34 – PUCKFish

The lobster fishing industry is a historic practice that has largely remained unchanged since its emergence in the mid 1800s. This industry is slow moving, with fishermen only now beginning to adopt more modern practices. One technology that the lobster fishing industry lacks is the ability to use data analytics to determine where lobsters will be. This lack of data leads fishermen to place numerous, extraneous traps throughout the ocean in areas unlikely to house lobsters. While these extra traps do not have an impact on lobsters, they do have a significant environmental impact on other marine life such as the endangered North American Right Whale, a species where lobster trap entanglement is the leading cause of unnatural death. Due to these environmental concerns, heavy regulations are placed on the lobster fishermen, stifling their industry and livelihoods. To solve this problem, we are creating PUCKFish, a low cost data collection unit designed to survive the harsh ocean environment. This device puts data collection and databases into the hands of the fishermen, allowing them to analyze seafloor conditions and make data-backed decisions about where to place lobster traps to truly optimize fishing hauls. We will be producing three PUCKFish data collection devices each recording six key metrics relevant to lobster activity on the seafloor as well as a ship-mounted base station that will receive that data and convert it into a format usable by our clients’ suite of other products for local and aggregated data analytics. PUCKFish will be the first business-grade all-in-one data collection and analysis suite specifically for lobster fishermen. Its cost of below $50 per unit, and ability to collect all of the six key metrics critical to locating and tracking lobsters will revolutionize the lobster fishing industry.

# 1.0 Introduction

Currently, the leading cause of death in the critically endangered North Atlantic Right Whale is “entanglements and vessel strikes” (NOAA Fisheries). This issue has caused legislation such as the Marine Mammal Protection Act which effectively illegalizes lobster fishing in large areas of the Atlantic Coast. To protect these animals, lobster fishermen will have to invest in technologies which reduce lobster line pollution. One solution to this issue will be the PUCKFish. As our device will provide fishermen with the information to better approximate the location of lobsters, they will be able to place fewer traps, more effectively, directly decreasing the chances of whale entanglement.

Presently, there is a lack of important data readily available to lobster trappers, with many of them relying on outdated, incomplete historical data to make trap placement decisions. This ultimately forces them into guessing where lobster clusters are, leading to suboptimal use of their limited traps.

Our solution, PUCKFish, will address these issues by giving lobster trappers the most useful data for locating and catching lobsters. From joint studies conducted by NOAA and The Northeast Fisheries Science Center Oceanography Branch, these data points are temperature, dissolved oxygen, salinity, current speed and direction, depth, and ambient light (Manning). This data will then be collected to create one of the most robust oceanographic databases, updated far more regularly and over a wider area than pre-existing databases.

The PUCKFish will be tethered to either the line connecting the trap to the surface buoy or directly to the trap (seen in figure 1). It will collect data once every hour to be transmitted to a base station on the surface every two to three days when the traps are lifted from the water via LoRa radio. Internally, the sensors will be on a printed circuit board (PCB) to reduce size and streamline manufacturing. With certain sensors requiring water contact to collect data, access ports will be included in the design, visualized in figure 2. The sensing devices will have a battery life of ten days and will be designed to accommodate an easy recharging solution. We will be experimenting with a wireless charging solution to remove a point of failure, as salt water will eventually cause problems with any contact based charging port. With the devices being underwater, they have to withstand continuous exposure to salt water, varying temperatures, and high pressure.

Figure 1: Whole system visualization

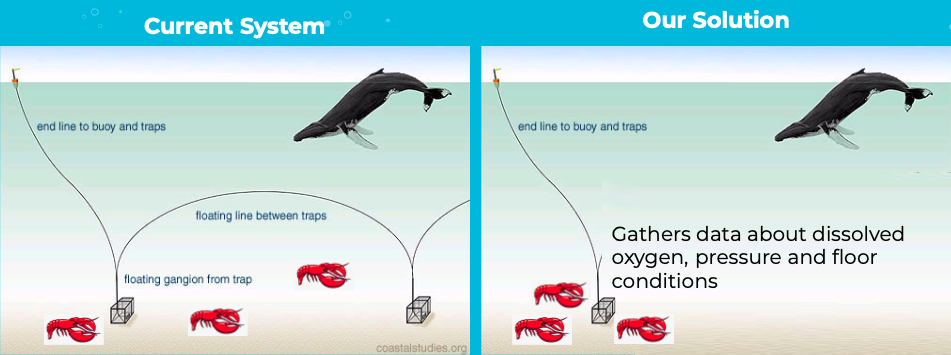
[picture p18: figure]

Figure 2: Visualization of the puck

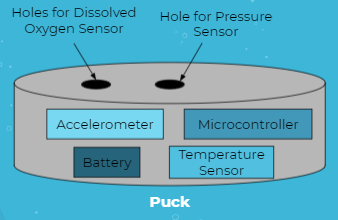
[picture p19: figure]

# 2.0 Concept Development

Lobster fishermen have been relying on apocryphal data gathered by themselves, and are guided more by instinct and history due to a lack of accessible, accurate data to inform them better where to be placing lobster traps in the ocean to maximize their hauls. As such, lobster traps are operating far below their maximum potential yield and increasing the amount of line pollution in the ocean unnecessarily.

Fathom Fishing is designing data collection and analysis tools and working with fishermen in the lobster fishing industry who would greatly benefit from being able to measure temperature, salinity, dissolved oxygen, ocean current, depth, and ambient light to help find optimal locations for placing lobster traps.

Other products on the market exist that provide some of these metrics. However, they generally rely on the company’s data collection and are not specific to the lobster industry, which necessitates fishermen to pay for expensive licenses and search for databases that contain all of the metrics that they need. The key goal of this project is to put the ability to collect relevant data back into the hands of the fishermen at a much reduced cost and complexity to increase yield per lobster trap and reduce the amount of harmful line pollution in the ocean.

Fishermen are very price sensitive due to the high cost of putting a boat out on the water and deploying/retrieving traps. This price sensitivity is part of the reason that a lack of innovation currently exists in this space, as most fishing vessels have spent tens of thousands of dollars on expensive navigation or data collection suites that are used for over a decade before retirement. Fathom Fishing surveyed many actual lobster fishermen and came to the conclusion that a unit cost of <$50 would allow many fishermen to buy into the Fathom Fishing product line.

We are keeping costs low by selecting cheap but accurate sensors that can be easily integrated into a custom PCB. Fishermen do not require scientific-grade levels of precision in the data collection, which allows us to make sacrifices in sensor quality. Fishermen care more about the general water current speed/direction trend over time and not the precise values that they wouldn’t practically use when fishing.

Another huge consideration we made early on was to design a system with as few moving parts as possible. At 1100ft below sea level, any mechanical components of our device would have to be designed with the ability to operate in incredibly high pressure and low temperature, and likely still be the first pieces to degrade due to exposure. As such, we have prioritized non-mechanical sensors for each of our six key metrics.

A potential issue we identified early on was that the PUCKFish must be tethered by some kind of line to the lobster traps, which could potentially prevent us from using an IMU to collect water current speed and direction accurately. The tether would be adding an additional force to our data that could be hard to model and correct for when doing data analytics.

We explored several more complicated solutions to do current sensing, including using high-precision strain gauges, acoustic doppler sensors, or generating an oscillating magnetic field to do EM based sensing. All of these options would have greatly increased cost and development time. As such, our priority for prototyping was to create a test bed for waterproofing techniques, and to test how accurately an IMU could measure water current while tethered. We used mostly prototype boards and enclosures to conduct this test to keep development time and cost low. Our test results showed that by tethering the PUCKFish to the lines between lobster traps on the seafloor, we would be able to easily back out the force of a tether from IMU data. With this test result, we were able to confidently go with the IMU approach and keep with our minimally mechanically complex design for this metric.

Another critical part of our design was figuring out a cost efficient and minimally mechanically complex way to sense dissolved oxygen. This metric is key to being able to predict where lobster pods will tend to be, as they require a specific amount of dissolved oxygen in the water in order to be able to survive. The problem with sensing this metric is that most out of box dissolved oxygen sensors are scientific-grade equipment with high precision and high cost (a single sensor can cost as much as $150, greater than our entire prototype unit price).

As such, we are exploring several different methods for creating our own dissolved oxygen sensor. We are currently considering two different methods for this sensor, using galvanic and optical methods. The galvanic method requires us to create custom electrodes that sit flush with the exterior of the PUCKFish and is minimally mechanically complex, but the degradation of these electrodes over time is a large factor in unit longevity. The optical method is much more mechanically complex, requiring us to create bubbles in the water and optically measure their size with a built-in camera. This method would be much harder to produce and necessitate a significantly larger battery to power the bubble-making and sensing components even during idle use.

Making the PUCKFish easily rechargeable was another key design problem we grappled with. A traditional wired charging port would either require complicating the PUCKFish shell with a pressure/water-proof seal to prevent water from seeping in, or creating a totally waterproof charging port. This would still be a huge point of failure, as the metal contacts in a charging port would quickly degrade with prolonged exposure to seawater.

After doing a feasibility analysis, we decided to use wireless charging in the PUCKFish. With wireless, we totally eliminate the design challenges imposed by a physical port on the device, increasing mechanical integrity while keeping functionality. Eliminating all physical ports will require us to use wireless transmission to perform data recovery or update firmware on a unit, but will greatly drive down development time needed in the mechanical engineering side of the project.

Choosing a battery type was not a huge concern of ours during development as we have had experience working with rechargeable LiPo batteries, and were heavily pushed in that direction by our microcontroller vendor (Adafruit) setting the source voltage level we needed at the single cell LiPo range. Our goal is to choose the minimum possible capacity for the LiPo that we can get away with, as the battery will eat into the limited space within the PUCKFish enclosure, as well as our actual budget.

We have done some preliminary battery life calculations to figure out this minimum needed capacity to hit our target requirement of 10 days on a single charge, but still need to select a dissolved oxygen sensor design to complete this calculation. As of now, we believe we can get away with a battery with capacity as low as 500 mAh to get us through our 10 day requirement. However, we are aware that LiPo batteries lose some capacity at the low temperatures found on the ocean floor, and are factoring that in as a margin of safety to achieve the desired operating time.

Concept Development Method Analysis
Metric | Method | Pros | Cons
Water Current Speed/Direction | IMU | - Mechanically simplest solution - Low ingress risk - Low power draw - Cheap, readily available sensors | - Relatively low precision - Requires characterization of flow around puck
| EM Sensing | - Mechanically simple - Low ingress risk - Electrically simple - Accurate reading | - Requires development of new sensor - High power draw for readable voltage - Dependant on accurate salinity/conductivity data
| Acoustic Doppler Sensing | - State of the art in industry - Extremely accurate readings | - Extremely expensive - High volume requirement - High power draw
| Mechanical | - Extremely simple - Accurate reading - Low power draw | - Sensor or mechanism will inevitably fail - Depending on implementation, higher ingress risk
Dissolved Oxygen | Galvanic | - Self polarized, don’t require time to warm up - Accurate measurements - Easy to set up | - Zinc electrode corrodes and needs to be replaced periodically - Requires electrolyte solution to measure DO2
| Optical | - Don’t require electrodes to measure current - Will last longer | - Sensors are very expensive ($700+)
| Titrimetric | - Widely used standard procedure - Consistent results | - Subject to human error - Requires careful calibration

Estimated Power Budget
Component | Active Current Draw (mA) | Passive Current Draw (uA)
LoRa Radio | 120 | 300
Pressure Sensor | 1.25 | 0.1
Ambient Light Sensor | 0.25 | 5
Salinity Sensor | 8.5 | 3
Ocean Current Sensor | 1.9 | 6

# 3.0 System Description

The scope of PUCKFish entails three prototype “pucks” and a base station. Each puck will be mounted to a separate chain of lobster traps, collecting data for that cluster. When surfaced, the puck will detect it has surfaced via its pressure sensor, and wirelessly transmit the data it collected in JSON format over LoRA to the base station. The base station will then collect the data for processing. The data will be stored locally on a removable SD card in CSV format, and can be uploaded to the cloud for further processing and aggregation with other trappers’ data, depending on the trapper’s implementation of Fathom’s cloud services.

Each puck will be equipped with sensors for collecting: temperature, pressure, conductivity, dissolved oxygen, ambient light, and orientation/acceleration. Sensor models are tabulated in table 4, in section 6. While most variables are used directly, we will develop models to extrapolate salinity from conductivity, dissolved oxygen from a camera, and water current from orientation. These variables were requirements from our client, and are the most crucial to predicting aquatic life; they were specifically recommended by NOAA’s similar eMOLT project and professional lobster trappers.[^1]

Conductivity will be measured by applying a known voltage across two electrodes exposed to seawater, and measuring the resulting current to find resistance.

We intend to use a COTS galvanic dissolved oxygen sensor, as the design and manufacture of an oxygen sensor is unfeasible with our group’s capabilities and timeline. Such solutions revolve around measuring the current between two dissimilar metals, prompting the oxidation of the anode. This solution will return extremely accurate results. That said, COTS solutions are on the order of $170, so we will continue to investigate. Our client has approved the purchase and reverse engineering of existing solutions to try and cut costs.

Water current is measured using acceleration and orientation data from an inertial measurement unit. Characterization of the movement of the puck in water under different flows will be completed following extensive testing under different conditions. This will allow us to create a model that converts the acceleration and oscillation of the puck to approximate water current. This method has inherently low precision, but our client only requires approximate current readings, to give trappers a general idea of ocean currents. Specifically, they plan to inform trappers of “low, medium, or high” current, as well as direction. Preliminary testing in the lazy river at BU’s Fitness and Recreation Center demonstrated we are able to back out relative current strength and approximate direction from IMU data. Using this as proof of concept, we will move forward with more accurately characterizing puck movement under flow.

Sensors will be connected to the microcontroller, a Feather M0 w/ RMF95 LoRa from Adafruit, via I2C and powered through the same. The microcontroller will in turn be powered from a lithium polymer battery, on the order of 500 mAH, pending further testing and requirements of power budget. We expect some reduction in capacity due to the low temperatures at 1100ft below sea level,[^2] but this can be fixed by oversizing our battery by approximately 15 percent.[^3] Battery will be saved by only polling sensors once per hour, dramatically reducing power consumption and battery life so it can meet the required 10 days deployed. The battery will be charged using inductive wireless charging, reducing mechanical complexity and removing a possible port of ingress. While we can license an existing wireless power standard, the team is also investigating custom solutions to avoid the fees associated with Qi or other competing standards.

The puck is rated to survive for extended periods at depth in the harsh oceanic environment. This will be achieved by fully encasing the electronics in a marine grade epoxy, using a custom mold. This methodology is commonly used in marine applications,[^4] and benefits from epoxy’s waterproof and anti-corrosive properties.[^5] This prevents the need for a complicated sealing system, which would likely employ a consumable seal such as an o-ring or teflon tape and eventually fail due to corrosion and leakage. It additionally gives total freedom in designing a casing that both keeps water out from delicate components, as well as allowing saltwater access for sensors that require it. The final advantage of such a system is being able to cast to any general shape, particularly those for which hydrodynamic characterization is already well studied. This dramatically simplifies the modeling process by falling back on well known and understood flow models, for example, around a sphere.[^6]

Figure 3: System Block Diagram

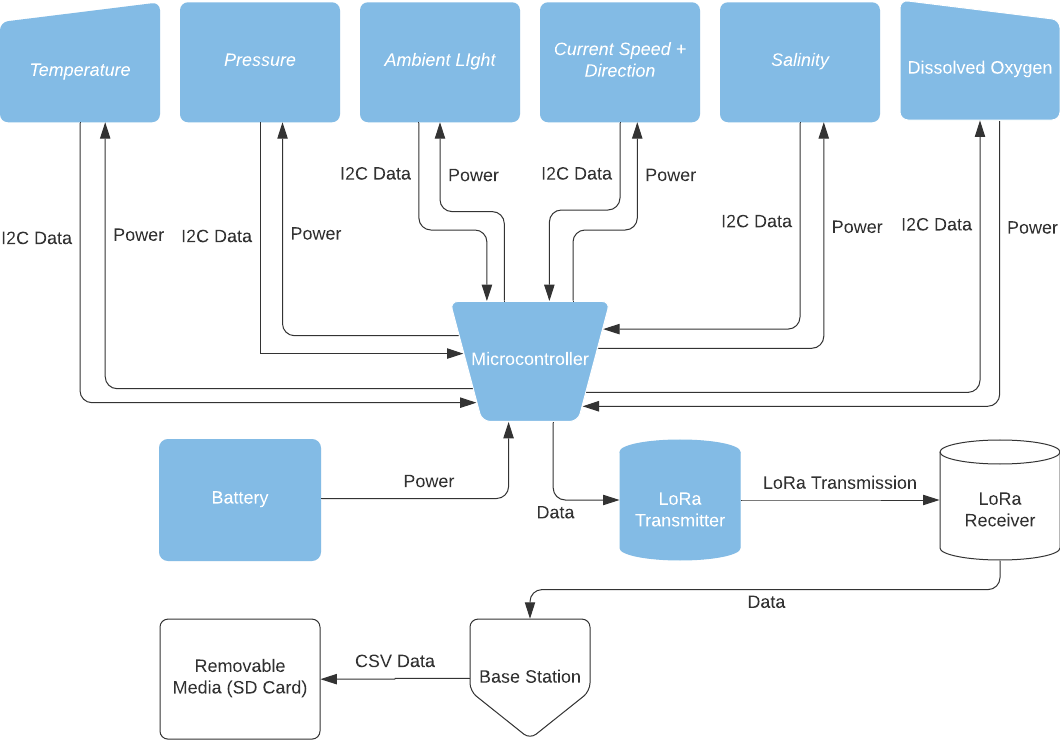
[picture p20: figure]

# 4.0 First Semester Progress

The technical development of PUCKFish can be divided into separate periods in which the team was focused on separate technical details: defining and refining requirements; research and development of a first prototype; and development of a testing plan and path forward, as well as testing the conceptual hardware that would be used in the prototype.

## 4.1 Developing and Defining Project Requirements

Early September was primarily focused on getting acquainted with the problems involving data acquisition at extreme depth and pressure. This research included general sensor architectures and methods, as defined by our initial requirements, as well as the design of pressure and corrosion resistant enclosures that can hold water-tight seals under 30 atmospheres of pressure. On September 27th, with the researched values and metrics, the team met with the client and used the time to adjust requirements and quantify accuracy and precision of the sensors required to reach success metrics. On October 4th, these findings were assembled into a PDRR presentation that was shown to the ECE class. These requirements can be found in appendix 1. In addition, competitive analysis was conducted to affirm that the requirements successfully provided PUCKFish with a competitive advantage.

## 4.2 Research and Development of Conceptual Design

With the requirements for the project properly defined, the team developed a strategy to determine minimum viable technologies that would perform at the prototype level. On October 18th in a joint meeting with the customers, a parallel technical path was developed in order to accomplish these goals.

The first of these paths included the development of the electronics and sensor array that would command and power PUCKFish. The electrical engineers took in the requirements developed through the PDRR stage. Ammar took the responsibility of selecting the dissolved oxygen, salinity and temperature sensors. Alex took the responsibility of the requirements involving the remaining sensors, microcontroller selection, radio transmission, and battery.

The latter of these paths included the development of the current sensing technology. This became its own path because the selection of the concept meant large-scale changes for the overall architecture of the PUCKFish. There were two main concepts for sensing the water currents around PUCKFish. The first idea was an inductive coil that would provide a back-voltage when saltwater would traverse through the coil. The second concept was developing an architecture that would be buoyant. When the current pushed the tethered buoyant enclosure, an IMU could be used to find the orientation of the enclosure and the orientation could be backtracked to find the force of the current, which in turn would provide the speed and direction of the water flow. Peter took the responsibility of researching and developing an inductive coil capable of measuring water current and Will took the responsibility of developing an IMU concept to measure current. Victoria would support both Peter and Will with manufacturing considerations. On October 15th, the design of an IMU test enclosure (see appendix 7.3.2) was completed and in late October, it was determined that the power draw for an inductive measuring device would be too great to sustainably power over the time period required by that of PUCKFish. The path forward became clear and on October 18th, Victoria and Will completed the manufacturing of the IMU current sensing concept .(see appendix 7.3.3 and 7.3.5)

On November 6th, Alex completed a preliminary electronics set up featuring the IMU, a LoRa radio and antenna, and a rechargeable lithium ion battery that transmitted data collected from the IMU (see appendix 7.3.4). From there he began researching final electronics requirements for PUCKFish. On November 9th, Ammar completed an initial selection of the required sensors with the exception of the dissolved oxygen sensor. At this point, the computer and IMU set up were ready to integrate into the IMU enclosure.

Preliminary testing for water testing was completed on November 14th by submerging the enclosure in a bathtub overnight and the results proved the enclosure was safe for electronics testing.

## 4.3 Testing, Implementation, and Planning

On November 15th, we began developing a testing plan with Will leading the procedure for the first test. The testing plan laid out future requirements for technical progress was completed on November 16th. During the November 16th test in the senior design lab, data was successfully collected and transmitted over radio from the IMU. Although the enclosure could not be tested underwater because of an inability to fill the water reservoir in the lab, the team determined that the test was successful as the enclosure was tested for waterproofing in a previous test. Due to the completion of Test 1.1, the team could begin following the testing plan featured in appendix section 7.3.1.

On November 22nd, the team prepared a testing procedure for Test 2.1 to test the IMU in FitRec’s Lazy River facility. On the same day, testing was carried out and data was collected. The team is still currently working on the model for taking the data and determining the best path forward for how the data will be used to determine the current velocity and direction. Given the requirements to determine water current qualitatively, the team determined that further testing to characterize the flow requirements would be needed and this metric would be wrapped into a future test within the test plan framework.

On November 29th, the team met to discuss the requirements for the PDR. Of these determinations were architecture concerns with electrical requirements. Primarily of interest was the charging method for the battery installed on PUCKFish. It was determined that for a first attempt at charging would involve wireless charging technology. Alex and Ammar began researching this approach and determined feasibility to acquire a license for future testing, wrapped in with Test 3.2. In addition, the mechanical engineers began work on sensor ports and the final enclosure design which would be featured in Test 3.1. Also discussed in this meeting was the creation of a technical path forward. This would be completed as a Gantt chart for the PDR.

On December 2nd, the PDR and technical path forward were completed and presented for review. The presentation was reviewed favorably and confirmed our assumptions of waterproofing and overall electronics architecture. On December 3rd, the Mechanical engineers began development of the final enclosure and ports in preparation for Test 3.1 and the electrical engineers began preparing for the sensor array test for Test 2.2.

# 5.0 Technical Plan

## 5.1 Introduction

The technical path forward was produced as a result of the tests necessary to develop a full prototype. As discussed before, the challenges with PUCKFish revolve around the data collection, as well as the harsh underwater conditions that must be accounted for. The tasks are divided to reach a successful prototype by the time the project is due during the week of April 1st and allows time for iteration and redesign so that successful customer integration is achieved by May 1st 2022.

For ease of reading, Power requirements, accuracy and precision figures, and other technical details are precluded from the technical plan. Values for requirements and technical requirements can be found in the appendix and are assumed to be counted as objectives for each task. When “Sensors” appears, this means all sensors as determined by the requirements listed in the appendix and preceding sections unless otherwise noted.

## 5.2 Technical Plan

### 5.2.1 Test 3.1 (12/02 - 2/10)

Task 1: Develop and Design Enclosure for Full Depth Pressure (12/02 - 12/18)

An enclosure will be developed in order to fit a custom 2”x6” PCB. The enclosure shall be water tight up to 30 bars of pressure. The enclosure shall accommodate the required mechanical mating mechanism to allow for wireless charging to take place but also be modifiable in the event that charging method must change. The enclosure shall feature integration features that allow the integration of sensor ports

Lead: Peter Ha Assisting: Will Aracri

Task 2: Develop and Design Sensor Ports (12/02 - 12/18)

Ports shall be developed for each sensor that needs exposure to the water to successfully accomplish a measurement per the requirements. Ports shall be water tight up to 30 bar of pressure. Ports shall be designed in order to successfully integrated to the enclosure features completed in Task 1

Lead: Victoria Thomas Assisting: Will Aracri

Task 3: Manufacture Enclosure (01/21 - 01/28)

The enclosure shall be manufactured per the requirements determined by the design featured in task 1. The enclosure shall be manufactured within the limitations of EPIC capabilities

Lead: Victoria Thomas Assisting: Peter Ha

Task 4: Manufacturer Sensor Ports (01/21 - 01/28)

The sensor ports shall be manufactured per the requirements determined by the design featured in task 2. The sensor ports shall be manufactured within the limitation of EPIC capabilities.

Lead: Victoria Thomas Assisting: Will Aracri

Task 5: Integration: Sensor Ports and Enclosure

The sensor ports and enclosure shall be integrated together. Any issues with integration including miss-fits or any other challenges shall be addressed and iteration or redesign will take place.

Lead: Peter Ha Assisting: Victoria Thomas

Task 6: Testing Plan (01/28 - 02/04)

The testing plan for test 3.1 shall determine the method in which the enclosure will be tested to 30 bar. The testing plan will determine requirements for the quality of water proofing. The testing plan shall include a measurable quantity to associate the required amount of water proofing to achieve successful operation

Lead: Will Aracri Assisting: Victoria Thomas, Peter Ha

### 5.2.2 Test 2.2: Sensor Array Test (01/02 - 01/28)

Task 1: Select Sensors (10/02 - 12/03)

Task 1 was successfully completed this semester by Ammar Hussain. These sensors are featured in the appendix

Task 2: Complete Electronics Design (11/15 - 12/16)

A complete electronics design shall accommodate all sensors per the requirements. The electronics design shall collect data and relay the data back to a computer for data analysis. The electronics design shall be able to sustain 1 hour of operation time. The electronics design shall allow for easy maintenance so that interactive design may take place

Lead: Alex Necakov Assisting: Ammar Hussain

Task 3: Internal Design Review ( 12/16 - 12/16)

An internal design review shall cover the design of the sensor array testing electronics. An internal design review shall cover the precision of the sensors, the sample time that are achievable, and shall cover methods of operation

Leads: Alex Necakov, Ammar Hussain Assisting: Victoria Thomas, Will Aracri, Peter Ha

Task 4: Functional Testing (01/20 - 01/22)

Functional testing shall prove data can be collected from the sensor array. Functional testing shall prove data may be uploaded to a computer for review. Functional testing shall confirm operating procedures of the sensor array

Lead: Alex Necakov Assisting: Will Aracri

Task 5: In-Water Test (01/22 - 01/24)

An in-water test shall develop a controlled test environment where data may be retrieved with known values. An in-water test shall collect data from the controlled test environment and be relayed back to a computer for further analysis

Lead: Alex Necakov Assisting: Will Aracri

Task 6: Data Analysis (01/24 - 01/26)

Data analysis shall take data as a result of the in water test and compare the data to the known values of the controlled test environment. A data analysis test shall provide proof that sensors are developing accurate data to the precision per the requirements.

Lead: Alex Necakov Assisting: Will Aracri

Task 7: Iteration Time (Optional) (01/26 - 01/27)

Iteration time shall adjust the sensor array electronics so that data may be read successfully if not deemed successful by the data analysis. Iteration time shall change the design per success.

Lead: Alex Necakov Assisting: Ammar Hussain

Task 8: In-Water Test 2 (Optional) (01/27 - 01/28)

An in-water test shall develop a controlled test environment where data may be retrieved with known values. An in-water test shall collect data from the controlled test environment and be relayed back to a computer for further analysis. A second In-Water test shall prove that iterations made during task 7 were successful.

Lead: Alex Necakov Assisting: Will Aracri

### 5.2.3 Test 3.2: Full Hardware Test (01/28 - 02/10)

Task 1: Develop and Design PUCKFish Computer (01/28 - 02/06)

A computer shall be designed to collect the sensor data from the current sensing data and the sensors proved out from Test 3.2. The computer shall relay the sensor data to a base station. The computer shall be approximately 2in in width and 6 inches in length and 1 inch in thickness.

Lead: Alex Necakov Assisting: Ammar Hussain

Task 2: Develop and Design PUCKFish Power Supply (01/28 - 02/06)

A power supply shall be designed to power the PUCKFish computer for a duration of 10 days. The power supply shall be designed to recharge via the recharge method determined, either wirelessly or through leads provided to the mechanical engineering team.

Lead: Ammar Hussain Assisting: Alex Necakov

Task 3: Internal Design Review (02/04 - 02/04)

An internal design review shall inform the mechanical engineering team of the dimensions of both the power supply and the puckfish computer. An internal design review shall show methods of operation. An internal design review shall determine unknowns meant to be uncovered during testing to the team.

Leads: Ammar Hussain Alex Necakov Assisting: Peter Ha, Victoria Thomas, Will Aracri

Task 4: Testing Plan: Functionality (02/07 - 02/07)

A testing plan shall determine a controlled environment for the sensors to collect data from the water with the exception of current velocity. A testing plan shall include requirements for sensor data accuracy. A testing plan shall determine a method to test radio transmission of the data to a base station or computer.

Lead: Alex Necakov Assisting: Ammar Hussain

Task 5: Testing Plan: Battery Life Test (02/07 - 02/07)

A testing plan shall determine a controlled environment where the life of the battery may be determined. The testing plan shall include requirements to determine the successful recharging of the battery. A testing plan shall include an integration plan to bring the power supply system together with the functional PUCKFish computer.

Lead: Ammar Hussain Assisting: Alex Necakov

Task 6: Functionality and Battery Life Testing (02/07 - 02/10)

Functionality and Battery Life testing shall provide a full duration (10 day) test of the computer collecting and transmitting data to a base station. Functionality and Battery Life testing shall prove that the battery may be successfully recharged after a full duration test. Functionality and Battery life testing shall follow the procedures developed in Task 4 and Task 5.

Lead: Will Aracri Assisting: Ammar Hussain, Alex Necakov, Victoria Thomas, Peter Ha

### 5.2.4 Test 4: Full PUCKFish Functionality Testing (02/10 -04/30)

Task 1: Final Iteration and Adjustments (02/10 - 03/21)

Final iteration and adjustments shall fix bugs found in Test 3.1 and Test 3.2. Final iteration and adjustments shall provide an integration plan between the mechanical enclosure developed from test 3.1 and the electronics hardware in Test 3.2.

Leads: Alex Necakov, Peter Ha Assisting: Victoria Thomas, Ammar Hussain, Will Aracri

Task 2: Testing Plan: Full Functionality Testing (03/21 - 03/27)

A testing plan shall provide an environment where PUCKFish’s sensors may be evaluated. A testing plan shall provide procedures for operating PUCKFish. A Testing plan shall determine the appropriate methods to evaluate the success of operation and data collection of the final PUCKFish design. A testing plan shall provide a method to test PUCKFish to at least 2 full work cycles.

Leads: Alex Necakov, Victoria Thomas, Peter Ha, Ammar Hussain, Will Aracri

Task 3: Full Functionality Test (03/28 - 04/01)

A full Functionality Test shall be performed to the procedure determined by Task 2. A full functionality test shall note difficulties in operating PUCKFish for later review.

Leads: Alex Necakov, Victoria Thomas, Peter Ha, Ammar Hussain, Will Aracri

Task 4: Testing Review (04/01 - 04/02)

A testing review shall determine if the test performed during task 3 reached the success parameters determined by task 2. A testing review shall determine path forward for possible further iterations and adjustments.

Leads: Alex Necakov, Victoria Thomas, Peter Ha, Ammar Hussain, Will Aracri

Task 5: Iteration and Adjustments (Optional) (04/02 - 04/29)

Iterations and adjustments shall address the shortcomings in either operation or accuracy to the project requirements as discovered during Task 4. Iterations and Adjustments shall complete any final requirements for PUCKFish to become operational

Leads: Alex Necakov, Victoria Thomas, Peter Ha, Ammar Hussain, Will Aracri

Task 6: 2nd Functionality Test (04/29 - 04/30)

A second functionality test shall be performed like Task 3 to determine if the Iterations and Adjustments were successful in reaching the goals defined in Task 2: Full Functionality Testing Plan

Leads: Alex Necakov, Victoria Thomas, Peter Ha, Ammar Hussain, Will Aracri

### 5.2.5 Final Administrative Items (04/30 - 05/18)

Task 1: Customer Installation (04/30 - 05/18)

Customer installation shall provide cooperation between the end user customers and the PUCKFish development team. Customer Installation shall provide feedback on the final PUCKFish designs. Customer Installation shall only consist of operational changes to PUCKFish with no architecture changes to the direct product itself

Leads: Alex Necakov, Victoria Thomas, Peter Ha, Ammar Hussain, Will Aracri

Task 2: ECE Day (05/06 - 05/06)

ECE Day shall be completed per the requirements given to the team by the course.

Leads: Alex Necakov, Victoria Thomas, Peter Ha, Ammar Hussain, Will Aracri

# 6.0 Budget Estimate

Item | Qty | Unit Cost | Total | Vendor
Feather M0 w/ RMF95 LoRa | 1 | 34.95 | $34.95 | Adafruit
MS583730BA01-50 (Depth/Temp) | 1 | 12.59 | $12.59 | Digikey
LTR-329ALS-01 (Amb. Light) | 1 | 1.06 | $1.06 | Digikey
ZXCT1107SA-7 (Salinity) | 1 | 0.92 | $0.92 | Digikey
ICM-20608-G (IMU) | 1 | 7.44 | $7.44 | Digikey
Lithium Ion Polymer Battery | 1 | 7.95 | $7.95 | Adafruit
Raspberry Pi Zero 2 W | 1 | 15.00 | $15.00 | Adafruit
32GB SD card | 2 | 9.95 | $19.90 | Adafruit
Dissolved Oxygen Sensor (Camera) | 1 | 12.50 | $12.50 | Adafruit
Device Casing (PVC Pipe) | 1 | 23.95 | $23.95
Marine Epoxy | 1 | 50.00 | $50.00 | ProMarine Supplies
Other Assorted Mechanical Items | 1 | 20.00 | $20.00 | N/A
| | Total Estimate: | $206.26

Table 4. Estimated Budget

# 7.0 Attachments

# 7.1 Appendix 1 – Engineering Requirements

Team # 34 Team Name: PuckFish

Project Name: PuckFish

Requirement | Value, range, tolerance, units
Price | Less than $150 per prototype
Depth and Pressure | Operate fully-submerged in saltwater at depths up to 1100ft and at a pressure of over 34.4 atm
Sensors | Contain sensors for detecting temperature, depth (hydrostatic pressure), salinity (conductivity), dissolved oxygen, and ambient water current, speed, and direction
Collection Frequency | Collect sensor data at least once per hour for up to 10 days on a single charge
Surfacing | Automatically detect when it has been submerged or has surfaced
Data Transmission | Wirelessly transmit up to 1 megabyte of data at a minimum rate of 50 kilobits/second to a base station up to 50ft away

# 7.2 Appendix 2 – Gantt Chart

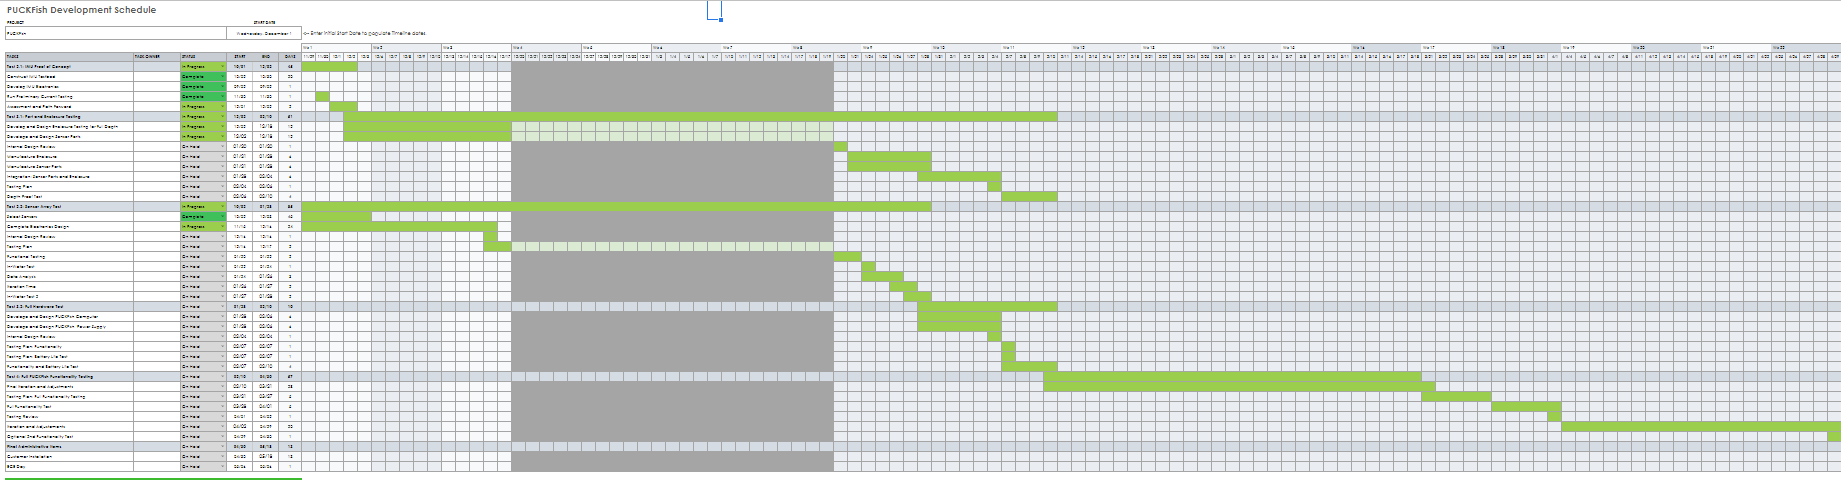
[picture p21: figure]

# 7.3 Appendix 3 – Other Appendices

7.3.1 Testing Path

7

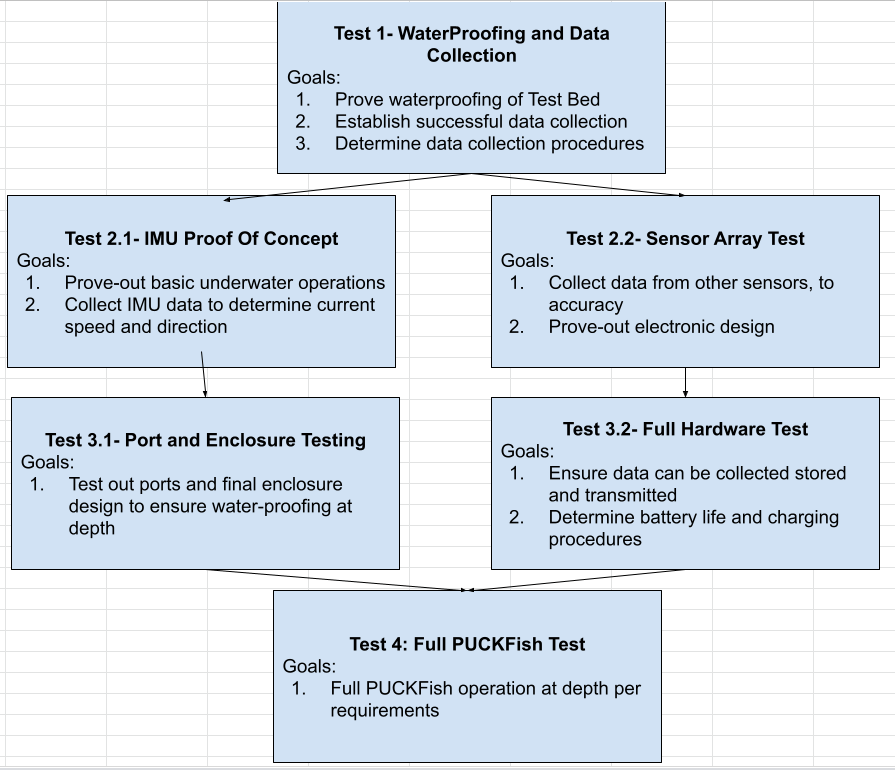
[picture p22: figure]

7.3.2 IMU Test Pill: Concept

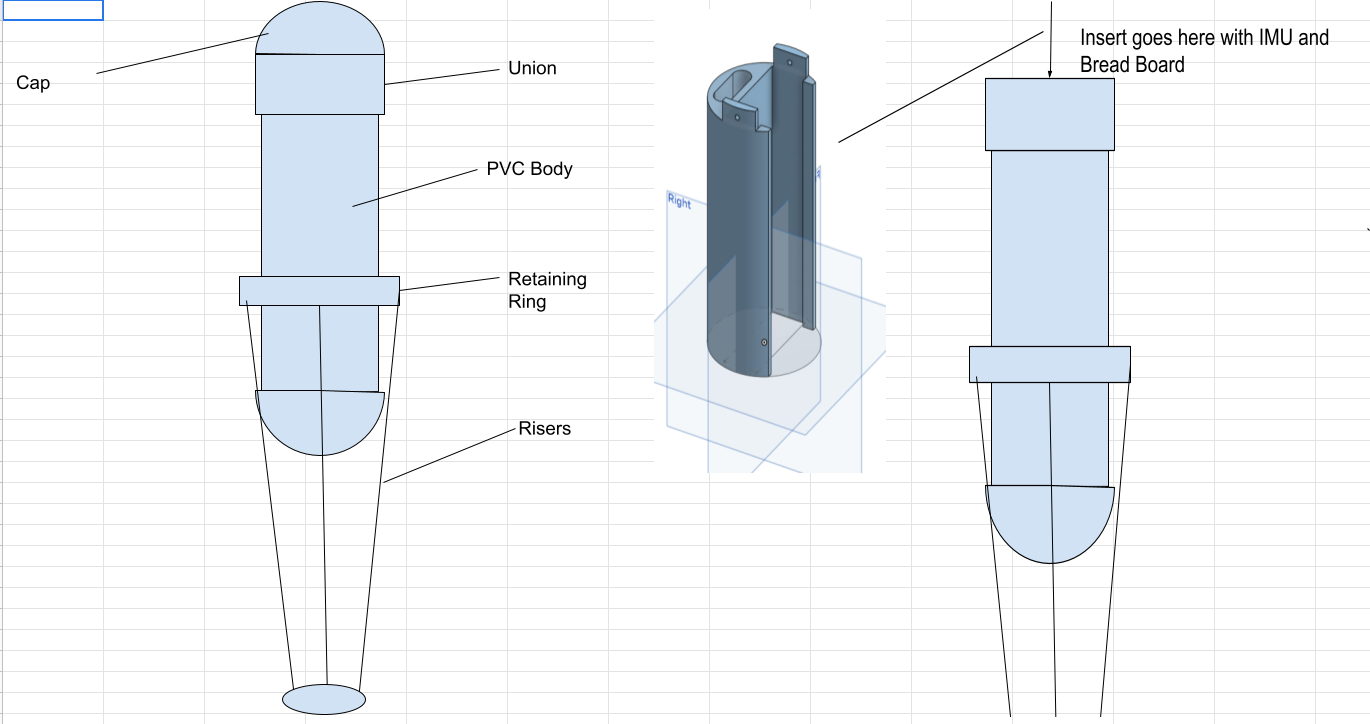
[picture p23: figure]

7.3.3 IMU Test Pill: Enclosure

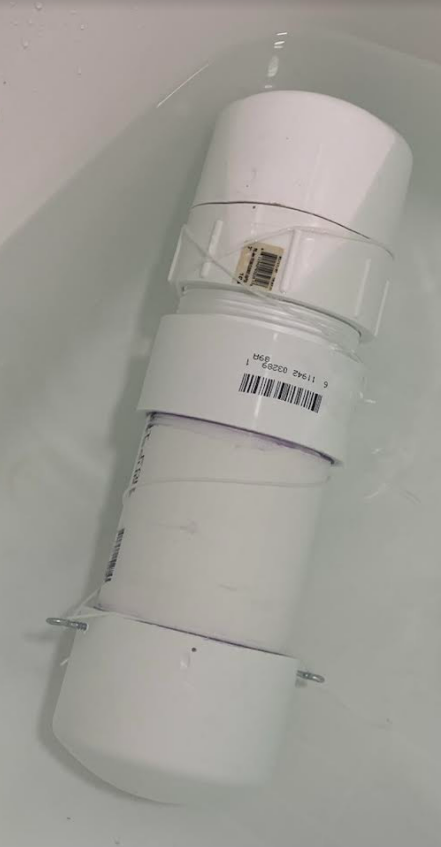
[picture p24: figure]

7.3.4 IMU Test Pill: IMU and Teensie


7.3.5 IMU Test Pill: Computer Chassis in the process of printing


7.3.6 Team Biographies and History

Alex Necakov (CE 2022) - alexrn@bu.edu (203)-822-3119

Alex is an undergraduate pursuing a B.S. in computer engineering at Boston University. Although specializing in software engineering, Alex has gained experience in a breadth of ECE related fields from work in robotics and rocket electronics design. Working with embedded electronics has been his main takeaway from his undergrad experience, which translates directly to his work on the ECE side of PUCKFish.

Victoria Thomas (ME 2022) - vmthomas@bu.edu

Victoria is pursuing an undergraduate degree in mechanical engineering with an aerospace concentration from Easton, MA. Due to her significant hands-on manufacturing experience, Victoria is able to provide manufacturing planning and processes. In this semester she performed water testing on this device and helped to design and create the electronics bed.

Ammar Hussain (EE 2022) - hussaina@bu.edu (617)-281-9858

Ammar is an undergraduate pursuing a B.S. in electrical engineering at Boston University. He is from Brookline, MA with experience in microelectronic circuits, and has an interest in sensor development. Additionally, he has long had a passion for marine biology and hopes to combine interest with his technical background to PUCKFish.

Will Aracri (ME 2022) - waracri@bu.edu (412)-952-8185

Will is an engineering student from Pittsburgh PA. After spending a year and a half in industry, he came back to Boston to complete his degree. He specializes in testing and manufacturing procedures.

Peter Ha (ME 2022) - peterha@bu.edu 857-321-1112

Peter majors in mechanical engineering with a political science minor. Having gained experience in high pressure, low cost systems in rocket propulsion design, Peter hopes to apply this knowledge to PUCKFish.

Team History

Alex, Victoria, Peter and Will met during freshman year through the Rocket Propulsion Group. They have worked together on various projects for the team including liquid rocket engines, test stands and other assorted infrastructure. After a short break due to the pandemic, the team found themselves back in Boston for senior year and found themselves ready to team up again to take on a multi-disciplinary project that they were used to working on.

Ammar and Peter went to highschool together in Boston and seeing the requirement we had for an extra hand on the electrical engineering team, Ammar fit right in and got to work as one of our two electrical engineers.

The team is excited to be working together with BU alumni and Fathom Fishing to produce a piece of engineering that supports local industry and protects the right whale population off the coast of its home New England.

7.3.7 Customer Company: Fathom Fishing

Fathom Fishing is a company based in Boston Massachusetts by two BU alumnus, Andy Whitman and Anthony Byrne. They specialize in bringing 21st century technology to the fishing industries in the New England area. By bolstering the resources fishers have access to, they hope to reduce waste and improve the efficiency of fishing operations.

Works Cited

1. Battery University. “Discharging at High and Low Temperatures.” Battery University. Last modified October 27, 2021, https://batteryuniversity.com/article/bu-502-discharging-at-high-and-low-temperatures.
2. Bergman, Jennifer. “Temperature of Ocean Water.” Windows to the Universe. Last modified February 16, 2011. https://www.windows2universe.org/earth/Water/temp.html.
3. NOAA Fisheries. “Pot/Trap Fisheries Regulations to Help Save North Atlantic Right Whales Announced.” NOAA Fisheries, NOAA, 31 Aug. 2021, https://www.fisheries.noaa.gov/feature-story/pot-trap-fisheries-regulations-help-save-north-atlantic-right-whales-announced.
4. Lowell Instruments. “MATP-2W IoT Sensor &amp; Data Logger Data Sheet.” North Falmouth, MA: Lowell Instruments, May 2018, http://www.gomlf.org/wp-content/uploads/2018/11/MATP-2W-Data-Sheet-Rev-1.pdf.
5. Manning, James. “Environmental Monitors on Lobster Traps.” EMOLT Overview, https://apps-nefsc.fisheries.noaa.gov/nefsc/emolt/mission.html.
6. ProMarine Supplies. “Epoxy Resin for Waterproofing - Tried and True.” Last modified February 4, 2019, https://promarinesupplies.com/blog/epoxy-resin-for-waterproofing-tried-true/.
7. Southard, John. “Flow Past a Sphere II.” MIT OpenCourseware. Last modified Fall 2006, https://ocw.mit.edu/courses/earth-atmospheric-and-planetary-sciences/12-090-introduction-to-fluid-motions-sediment-transport-and-current-generated-sedimentary-struct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.
8. West System. “Epoxy Reliability and Performance.” Last modified 2021, https://www.westsystem.com/.

[^1] “MATP-2W Data Sheet,” Lowell Instruments, last modified May, 2018, http://www.gomlf.org/wp-content/uploads/2018/11/MATP-2W-Data-Sheet-Rev-1.pdf.
[^2] Jennifer Bergman, “Temperature of Ocean Water,” Windows to the Universe, last modified February 16, 2011, https://www.windows2universe.org/earth/Water/temp.html.
[^3] “Discharging at High and Low Temperatures,” Battery University, last modified October 27, 2021, https://batteryuniversity.com/article/bu-502-discharging-at-high-and-low-temperatures.
[^4] “Epoxy Resin for Waterproofing - Tried and True,” ProMarine Supplies, last modified February 4, 2019, https://promarinesupplies.com/blog/epoxy-resin-for-waterproofing-tried-true/.
[^5] “Epoxy Reliability and Performance,” West System, last modified 2021, https://www.westsystem.com/.
[^6] John Southard, “Flow Past a Sphere II,” MIT OpenCourseware, last modified Fall 2006, https://ocw.mit.edu/courses/earth-atmospheric-and-planetary-sciences/12-090-introduction-to-fluid-motions-sediment-transport-and-current-generated-sedimentary-struct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.

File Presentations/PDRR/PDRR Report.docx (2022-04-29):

EC463 - BOSTON UNIVERSITY ELECTRICAL & COMPUTER ENGINEERING CAPSTONE SENIOR DESIGN PROJECT

The

Alex Necakov, Victoria Thomas, Peter Ha, Will Aracri, Ammar Hussain

Abstract — There are less than 400 North American Right Whales remaining in the ocean today. Unfortunately, 34 of these endangered creatures have died of unnatural causes since 2017, and lobster trap entanglement and fishing vessel collisions are the leading causes of these deaths. Our company, Fathom Fishing, is looking for your help in developing the PUCKFish, an underwater sensor device, with the goal of eventually ridding the sea of entanglement-prone lobster-fishing lines and allowing fishermen to make fewer, more-efficient trips to their traps. The PUCKFish data collection kit consists of a base station (to be mounted on fishing vessels) and several small sensing devices (to be mounted on or near individual lobster traps). In the long term, these devices will allow fishermen to wirelessly locate and hoist their traps up from the ocean floor without needing to leave location-marking buoy lines floating where they can harm whales and other sea life. The first revision of the PUCKFish, however, will simply collect temperature, depth, dissolved oxygen, and other measurements of the water surrounding a deployed lobster trap. As soon as a fisherman pulls the trap above the surface, the PUCKFish will wirelessly upload the collected data to the onboard base station. Fishermen can then use this data to determine the locations and water conditions in which they’ll catch the biggest haul, reducing the number of trips needed to reach their legal sustainable catch limit, and marine biologists can use this data to track sea life conservation efforts.

1 NEED FOR THIS PROJECT

Due to hundreds of years of overfishing and mass pollution of the oceans, the pollution of right whales has decreased drastically. Whales play an important role in the environment, keeping other eat populations in check by eating “small fish, krill, larvae, copepods, pteropods, zooplankton, cyprids, euphausiids and other small invertebrates” (Whale Facts). Additionally, whale populations provide an important role in reducing atmospheric carbon as their excrement is the main source of food for oxygen producing phytoplankton (ScientificFeed).

Currently, the leading cause of death in the critically endangered North Atlantic Right Whale is “entanglements and vessel strikes” (NOAA Fisheries). This issue has caused legislation such as the Marine Mammal Protection Act which effectively illegalizes lobster fishing in large areas of the Atlantic Coast. To protect these animals, lobster fishermen will have to invest in technologies which reduce lobster line pollution. One solution to this issue will be the PuckFish. As our device will provide fishermen with the information to better approximate the location of lobsters, they will be able to place fewer traps, more effectively, directly decreasing the chances of whale entanglement.

2 PROBLEM STATEMENT & DELIVERABLES

2.1 Problem Statement

There is a current lack of data available to lobster catchers. Existing solutions use out of date technology, and give almost none of the data critical to deciding trap placement. This leads to an overabundance of traps in areas with very little yield, leading to efficiency losses for the lobster catchers, and creating greater pollution in the form of fishing lines connecting the traps to each other and buoys.

Our solution simultaneously solves each of these problems, giving trappers the data most useful in locating lobsters, including dissolved oxygen, soil softness, and temperature. By allowing lobster catchers to easily access these measurements, they can place fewer traps with greater yield. This data will then be collected to create among the most robust oceanographic databases, updated far more regularly and over a wider area than existing databases.

2.2 Deliverables

A set of three sensing devices capable of:

1. Measuring:

  a. Temperature
  b. Dissolved oxygen
  c. Salinity
  d. Current speed and direction
  e. Depth
  f. Ambient light

2. Transmitting the collected data

a. Transmit once the trap is at the surface
b. 1 MB at 50 kb/s from 50 feet away
c. At first, once an hour
d. Ideally, once a minute

A base station capable of:

1. Receiving data

2. Storing data on an SD card in CSV format

3. Withstand exposure to constant marine conditions

3 VISUALIZATION


Figure 1: Puck, Data Collection Device

4 Competitors

The PUCKFish has competitors that the team has grouped into three separate groups as determined by their requirements and features. The first of these three groups, Non-Competitors, exhibits similar goals to PUCKFish, but does not solve these problems in a similar way that competes with PUCKFish. The second group of competitors is called Minor Competitors. Minor Competitors have projects with the same goal of measuring the environment of the Lobster trapping industry, but do not include all of the features that are unique to PUCKFish. The final group is called Major Competitors. Major Competitors include most features that PUCKFish does and have the largest weight on the requirements of our design and outline the niches that PUCKFish situates itself in.

4.1 Major Competitors

4.1.1 TimeZero

TimeZero is a large-scale service that provides a variety of data from all over the world. Professional fishermen can select the services they require, although they do not collect ambient light measurements. TimeZero is a worldwide presence, which means that their focus varies and is not necessarily centralized to the Lobster industry in the northeast. PUCKFish should collect the same variety of information, while maintaining its niche with lobster nets.

4.1.2 eMOLT

eMOLT is a network of data collection equipment deployed on lobster traps. The data is collected by the fisherman community and then updated and available on a public form to see. eMOLT is the closest competitor and carries out essentially the same functions as PUCKFish. In order to improve upon this existing design, depth, ambient light, and most importantly, dissolved oxygen levels must be collected. In addition, the infrastructure and data provided must be more readily readable or translatable.

4.2 Minor Competitors

4.2.1 Oregon State University Data Collection System

Oregon State University developed a small micro controller to collect temperature and oxygenation levels. The last update of this project was in 2009. PUCKFish must at least take temperature and oxygenation levels at a depth, and do so better with more fidelity as it is newer.

4.2.2 LobsterNet

LobsterNet is a project incubated by Gloucester Innovation and powered by the Canadian company Sigfox. It collects live data in the form of temperature, oxlevel, pH, depth, and location. PUCKFish must collect at a minimum these data points. PUCKFish will not collect data live because, as shown by LobsterNet, a large infrastructure must be put into place to achieve successful implementation. LobsterNet was announced in 2019 with very little information or updates coming out since then.

4.3 Non-Competitors

4.3.1 LobsterLift

LobsterLift is a lobster trap that lifts itself with no lead line. This feature helps with one of the possible features of PUCKFish, but contains no sensor information relaying fisherman useful data. As a result, PUCKFish should not attempt to develop a self lifting capability until other sensor technology is implemented successfully.

4.3.2 LasTrap

LasTrap is a novel lobster trap made out of plastic leading to more resilient traps with the possibility of introducing further innovations. However, LasTrap does not include sensors, information collectors, or active components. PUCKFish is deployed on existing traps, so LasTrap does not have any impact based upon the requirements already presented.

5 ENGINEERING REQUIREMENTS

1. PUCKFish Sensor Collection Device
  a. Mechanical
    i. The device must operate at 1100 ft. below sea level, at pressures of over 34 atmospheres
    ii. The device must have holes on the outer shell for sensors to work
    iii. The device must be waterproofed and able to withstand rough undersea conditions
  b. Data Collection
    i. The device must collect data for the following measurements at a rate of at least one reading per hour
      1. Temperature
      2. Depth
      3. Ambient Light
      4. Dissolved Oxygen
      5. Ambient Water Current Speed/Direction
      6. Salinity
  c. Transmission
    i. The device must detect when it has submerged/surfaced to begin transmitting to the base station
    ii. Device must be able to wirelessly transmit when trap surfaces (1MB at 50kb/s from 50ft away)
  d. Power
    i. Device must be easily rechargeable, getting power from onboard lead acid marine batteries
    ii. Device must last on a single charge for up to 10 days
  e. Cost
    i. The prototype for the device must not exceed $150, and should cost $50 or less when produced at scale
2. Base Station
  a. Mechanical
    i. The Base Station must be able to withstand frequent splashes of saltwater, heavy rain, and other harsh marine conditions
  b. Data Collection
    i. The Base Station must receive data as PUCKFish transmits, formatting the data into an easily machine-readable format (CSV)
    ii. The Base Station must store data on a removable disk (SD Card) so data can be easily transferred to other systems for data analysis
  c. Power
    i. The Base Station must be able to be powered off of onboard lead acid marine batteries, accepting voltages in anywhere in the range of 11-14V

References

- Fisheries, NOAA. “Pot/Trap Fisheries Regulations to Help Save North Atlantic Right Whales Announced.” NOAA Fisheries, NOAA, 31 Aug. 2021, https://www.fisheries.noaa.gov/feature-story/pot-trap-fisheries-regulations-help-save-north-atlantic-right-whales-announced.
- “North Atlantic Right Whale.” WHALE FACTS, 11 July 2015, https://www.whalefacts.org/north-atlantic-right-whale-facts/.
- Sapir, Moran. “Why Are Whales Important to Our Ecosystem?” Scientific Feed, Scientific Feed 2021, 24 June 2021, https://admin.scientificfeed.com/nature/whales-important-ecosystem/.
- United States, Congress, Marine Mammal Protection Act: Hearings before the Subcommittee on Fisheries and Wildlife Conservation and the Environment of the Committee on Merchant Marine and Fisheries, House of Representatives, Ninety-Seventh Congress, First Session, on Marine Mammal Protection Act Authorization--H.R. 2948, April 7, 1981, Marine Mammal Protection Act Improvement--H.R. 4084, July 13, 1981. 1981. U.S. G.P.O. Congress.
- Fisheries, NOAA. “Atlantic Large Whale Take Reduction Plan.” NOAA, NOAA, 24 Sept. 2021, https://www.fisheries.noaa.gov/new-england-mid-atlantic/marine-mammal-protection/atlantic-large-whale-take-reduction-plan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,The%20Team.%20...%205%20Outreach%206%20More%20Information.

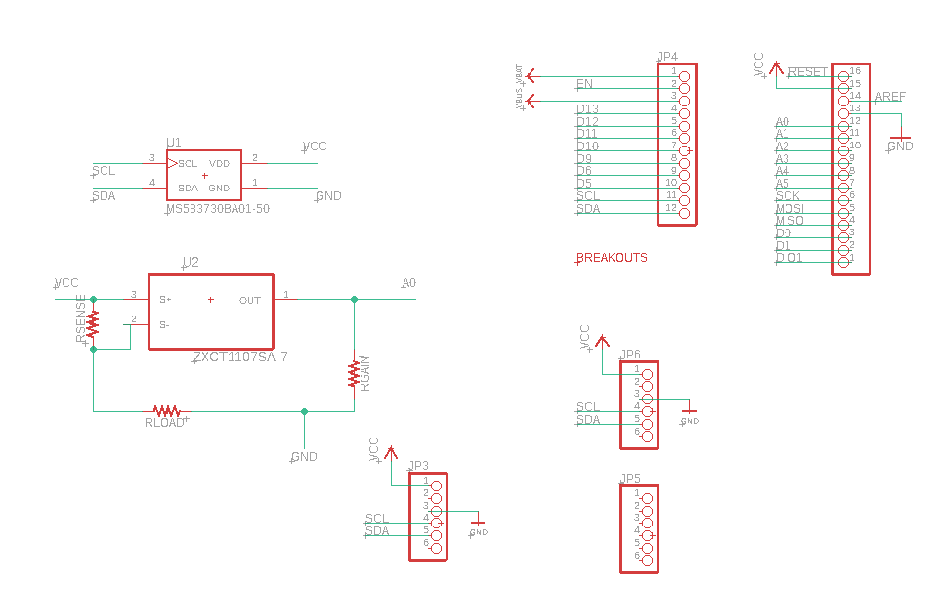
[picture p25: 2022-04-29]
PCB/Images/Schematic.PNG

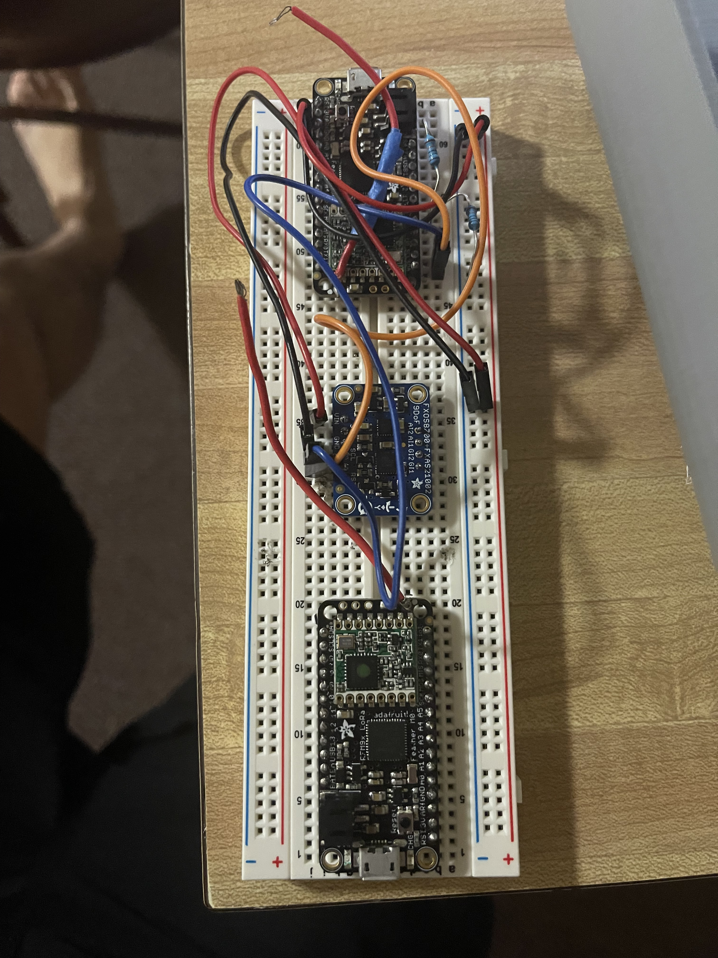
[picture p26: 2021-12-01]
Images/Pill Electronics.jpg

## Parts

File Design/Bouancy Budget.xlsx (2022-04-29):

Mass and Volume of Components |  |  | Enclosure Design Parameters
Item | Mass (kg) | Volume(mm^3) | Diameter(Sphere) (cm) | Volume(Sphere) (cm^3) | Flat Surface Knockdown (cm) | Volume Knockdown (cm^3) | Total Volume Profile (cm^3)
Pressure | 0.00525 | 23.5207115 | 10 | 523.5987756 | 8 | 29.32153143 | 494.2772442
Light | 0.00525 | 2015.145 |  |  |  |  | Total volume profile (m^3)
Dissolved O2 | 0.00525 | 2860 |  |  |  |  | 0.0004942772442
Salinity | 0.00525 | 6.96 | Epoxy mass calculations
Current (IMU) | 0.00525 | 2128.88 | Volume (Epoxy) (cm^3) | Mass Epoxy (kg)
Radio | 0.00525 | 9384 | 472.1317385 | 0.5036654173
Battery | 0.0105 | 4959 | Void Calculations
Qi Receiver | 0.00525 | 768 | Void Volume (cm^3) | Void mass (kg) | Volume Knockdown(epoxy) (cm^3) | Mass Knocked down (epoxy) (kg)
Structural | 0.75 |  | 16 | 1.96e-05 | 456.1317385 | 0.4865967773
 |  |  | Volume and Mass totals
 |  |  | Component Mass | Void Mass | Epoxy Mass | Total
 |  |  | 1.195875 | 1.96e-05 | 0.4865967773 | 1.682491377
 |  |  | Component Volume | Void Volume | Epoxy Volume | Total
 |  |  | 22.14550571 | 16 | 456.1317385 | 494.2772442
 |  |  | Volume Valid? | 0
 |  |  | Bouancy Force (N) | Gravity Force (N) | Delta
 |  |  | 4.829385242 | 16.4884155 | -11.65903026
 |  |  | Constants
 |  |  | Name | Value | Units
 |  |  | Acceleration, Gravity | 9.8 | m/s^2
 |  |  | Density, Water | 997 | kg/m^3
 |  |  | Density, Air, STP | 1.225 | kg/m^3
 |  |  | Design Constants
 |  |  | Epoxy specific Density | 1.07
 |  |  | Epoxy Density | 1066.79 | kg/m^3
Total Sub-Total (cm^3) | 1.195875 | 22.14550571 | Margin | 1.5 | N/A
Adjusted Estimate
Notes: Calculation of spherical caps
How this is adjusted: h = (D - c)/2
Note: Archimedes Principle
This shouldn't change with iterations unless the overall volume is changed

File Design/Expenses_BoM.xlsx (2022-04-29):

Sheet: Expenses
Senior Design Expense Tracking
 | Vendor | Item(s) Purchased In Order | Total Cost
1) | Atlas Scientific | DO2 Kit (https://atlas-scientific.com/kits/gravity-analog-do-kit/) | $144.99 | Total Budget | $500.00 | Legend:
2) | Digikey | Wireless Charging Receiver (https://www.digikey.com/en/products/detail/1901/1528-1384-ND/5629432?so=73883837) | $22.01 | Spent | $785.78 | Purchased
3) | Adafruit | Radio, battery, SD Card, Wireless charging transmitter, light, (https://www.adafruit.com/product/3178) | $273.66 | Remaining | -$285.78 | Not Yet Purchased
4) | Entropy Resin | CCS Resin + Slow Hardener 1.5 Gal kit (https://entropyresins.com/product/ccr-clear-casting-epoxy/) | $190.00
5)
6) | Radwell | Temp+Pressure Sensors (https://www.radwell.com/en-US/Buy/TE%20CONNECTIVITY/TE%20CONNECTIVITY/MS583730BA01-50) | $55.74 | Dept Allowance | $500.00
7) | Defender | Anti-Torsion Cable (https://www.defender.com/product.jsp?id=6516740) |  | Spent | $0.00
8) | Arrow | Pressure + Salinity Sensors (https://www.arrow.com/en/products/ms583730ba01-50/te-connectivity?q=MS583730BA01-50) | $77.58 | Remaining | $500.00
9) | JLC PCB | PCB Boards | $21.80
10) |  |  |  | The totals above will automatically update
11) |  |  |  | based on the values entered in column D.
12)
13) |  |  |  | You can add additional rows as needed.
14)
15)
16)
17)
18)
19)
20)
21)
22)
23)
24)
25)

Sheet: BoM
Item | Qty | Unit Cost | Total | Vendor | Link | Legend:
Feather M0 w/ RMF95 LoRa | 1 | $34.95 | $34.95 | Adafruit |  | Purchased
MS583730BA01-50 (Depth/Temp) | 1 | $12.59 | $12.59 | Digikey |  | Not Yet Purchased
LTR-329ALS-01 (Amb. Light) | 1 | $1.06 | $1.06 | Digikey
ZXCT1107SA-7 (Salinity) | 1 | $0.92 | $0.92 | Digikey
ICM-20608-G (IMU) | 1 | $7.44 | $7.44 | Digikey
Lithium Ion Polymer Battery | 1 | $7.95 | $7.95 | Adafruit
Raspberry Pi Zero 2 W | 1 | $15.00 | $15.00 | Adafruit
32GB SD card | 2 | $9.95 | $19.90 | Adafruit
Dissolved Oxygen Sensor (Camera) | 1 | $12.50 | $12.50 | Adafruit
Device Casing (PVC Pipe) | 1 | $23.95 | $23.95
CCS Resin + Slow Hardener 1.5 Gal kit | 1 | $172.78 | $172.78 | Entropy Resins | https://entropyresins.com/product/ccr-clear-casting-epoxy/
 |  | Total Estimate: | $309.04

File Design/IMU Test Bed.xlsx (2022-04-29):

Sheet: Requirements
Requirement Name | Value | Units | Source | Notes
Enclosure must be able to fit Electronics | 6.5x2.25x1 | in | Alex: Text 10/20
Enclosure must be water proof | 10 | ft | https://www.bu.edu/fitrec/recreation/aquatics/recreation-pool-hot-tub/ | Doubled due to uncertainty
Enclosure must be accessable | N/A | N/A | Alex: Discussion during Shark Tank 10/19
Enclosure must have adjustable bouancy | N/A | N/A | Peter: Discussion during Shark Tank 10/20
Enclosure must be restricted from rotation | N/A | N/A | Peter, Alex, Will: Discussion Before Shark Tank 10/19

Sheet: WaterProofing
Sources
https://en.wikipedia.org/wiki/Waterproofing
https://www.fictiv.com/articles/nothing-gets-in-waterproof-enclosure-design-101-and-ip68
http://www.reefcentral.com/forums/showthread.php?t=2130680
https://www.electriciantalk.com/threads/making-pvc-joints-water-tight.26149/
Notes and Conclusions
For a PVC pipe enclosure, teflon tape, threads, and PVC primer and Cement will do the job at 10 ft
THIS NEEDS TO BE TESTED, ONLY MODERATE CONFIDENCE
A video demonstrating interior pressure: Not the same but a confidence booster for sure
https://www.youtube.com/watch?v=doPXNWC1Iig

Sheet: Bouyancy
This page addresses Bouancy and changing its effects
If we consider our situation in "Steady State" or on time scales small enough we could use Archemede's principle
Below is a screen grab from a wikipedia article
So we change "Floatyness" by adding mass, not by increasing bouancy
Bouancy remains the same regardless of object mass
HOWEVER, pay attention to the note seen in the article above, we might have to implement a look-up table at a later date
Using Basic mechanics, we can solve out for tension given different angles, and then force in X direction, which then corresponds to water velocity and density

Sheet: Anti-Rotation
Anti-Rotation Requirment
Essentially we need a way to attach to the canister from the weight that either resists or dampens torque on the cyclinder
Assumptions
Generally Symetrical Shape
localized uni-directional flow
If cables used, no localized fluid force on cables
No greater than the weight of the object as a torsional element |  | Shitty assumption
Essentially, the connection method must be able to withstand torsional stress or return forces that cancels torques
1 | Pole With Ball Joint
2 | Multiple Strings w/ common atachment point
3 | Anti Torsion Cable
Canopy-to-risers on a parachute probably our best bet |  | WITH an anti-torsin cable as our base
If we are doing a canopy design, the retention ring needs to slide over the body of the PVC, glue onto it, then have hole provsions for the risers to go through
I am imagining something like this

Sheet: Sizing
PVC Pipe comes in different "Schedules"
Schedule 40 | White, Thinner walls holds less pressure
Schedule 80 | Gray, Thicker walls holds more pressure
We're going for Schedule 40
Sizing
Name | Value | Units
BreadBoard w | 2.25 | in
BreadBoard t | 1 | in
BreadBoard L | 6.5 | in
2.5 Nominal PVC Pipe Margin
Name
Diameter | 2.445 | in
Length | 7 | in
Margin W | 0.0975 | in
Margin t | 0.7225 | in
Way too tight on width margin
3 Nominal PVC Pipe Margin
Name
Diameter | 3.042 | in
Length | 7 | in
Margin W | 0.396 | in
Margin t | 1.021 | in
Margin L | 0.25 | in
Weigth of Length | 0.868 | lbs
https://www.pvcfittingsonline.com/resource-center/pipe-fittings-sizes-guide/
Other Required Components
Name | Quanitity | Notes
3" nom. PVC cap | 2 | This will be put on the end of the pipe as well as serving as a cap for how we can close out the system
3" union | 1 | This will be how we can access the IMU and Breadboard without having to cut the pipe every time
Note: Why a union?
Unions are going to let us screw and unscreww the top of our assembly to allow us to gain access to the inside. The other thing thats nice about unions is that the ID of the union and the pipe are the same, so our insert that we add (See insert sheet) can slide in and out of the pipe freely

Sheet: Insert
Features:
Bed allows Sticky bread booard mounting surface
OD of the entire print allows a sliding fit inside the pvc tube
Hole provisions on the tabs are for set screws to limit rotation inside the part
Oval slit at the bottom is for changing weight/COM as needed

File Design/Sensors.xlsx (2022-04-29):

 |  | $279.62 |  | 42.70 |  |  | 319.6 | 134.27 | Battery Life Calculator (https://www.digikey.com/en/resources/conversion-calculators/conversion-calculator-battery-life)
Sensor Type | Model # | Price ($) | Size (mm) | Weight (g) | Measurement Range | Supply Voltage (V) | Standby Current (uA) | Active Current (mA) | Part Link | Data Sheet | Notes
Pressure | MS583730BA01-50 | $9.00 | smd | ~2 | 0 - 30 bars | 1.5 to 3.6 V | 0.6 | 1.25 | https://www.radwell.com/en-US/Buy/TE%20CONNECTIVITY/TE%20CONNECTIVITY/MS583730BA01-50 | https://www.te.com/commerce/DocumentDelivery/DDEController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 | Needs exterior access
Light | BH1750 | $4.50 | 25.3 x 17.7 x 4.5 | 1.8 |  | 2.4 - 3.6 | 1 | 0.12 | https://www.adafruit.com/product/4681 | https://www.mouser.com/datasheet/2/348/bh1750fvi-e-186247.pdf | Breakout board
Dissolved O2 | Atlas Scientific Kit | $144.00 | (probe) 12 x 89 (chip) 56 x 32 | 15 |  | 3.3 - 5 |  | 0.3 | https://atlas-scientific.com/kits/gravity-analog-do-kit/ | Data Sheet (https://files.atlas-scientific.com/Gravity-DO-datasheet.pdf) | Need a probe - very expensive, also don't know standby current
Salinity | ZXCT1107SA-7 | $0.92 | 2.9 x 1.3 x 1 | ~2 | 1 uA to 2.064 mA | 2.5 - 36 | 3 | 8.5 | https://www.newark.com/diodes-inc/zxct1107sa-7/current-sense-amplifier-low-power/dp/55T4047 | Data Sheet (https://www.diodes.com/assets/Datasheets/ZXCT1107_10.pdf) | Also SMD, might have difficulty under water
Current (IMU) | MPU-6050 | $6.95 | 26 x 17.8 x 4.6 | 1.8 |  | 3.3 | 15 | 4.1 | https://www.adafruit.com/product/3886 | http://www.invensense.com/wp-content/uploads/2015/02/MPU-6000-Datasheet1.pdf | Breakout board
Radio | RFM9x LoRa 915 | $34.95 | 51 x 23 x 8 | 5.6 | 5 to 20 dbm | 3.3 - 3.7 | 300 | 120 | https://www.adafruit.com/product/3178 | https://www.hoperf.com/data/upload/portal/20190801/RFM96W-V2.0.pdf | Price also includes Feather prototype board/MCU. Antenna not priced in. Calcs for data rate needed. Current draw is radio only
Battery | LiPo 3.7V 500mAh | $7.95 | 29 x 36 x 4.75 | 10.5 |  | 3.7 |  |  | https://www.adafruit.com/product/1578 |  | JST Connector, calcs very much needed and dependent on missing sensors
Qi Receiver | 1528-1384-ND | $14.95 | 48 x 32 x .5 | 8 |  |  |  |  | https://www.digikey.com/en/products/detail/adafruit-industries-llc/1901/5629432 | https://www.hoperf.com/data/upload/portal/20190801/RFM96W-V2.0.pdf | OOS at Adafruit, needed Digikey order
Qi Transmitter |  | $26.95 | n/a | n/a | n/a | 5 | n/a | n/a | https://www.adafruit.com/product/2162 |  | Not on puckfish, for base station
Base Radio | RFM9x LoRa 915 | $19.95 | n/a | n/a | n/a | 3.3 | n/a | n/a | https://www.adafruit.com/product/3072 | https://www.hoperf.com/data/upload/portal/20190801/RFM96W-V2.0.pdf | Not on puckfish, for base station
Storage | Adafruit SPI SD Flash | $9.50 |  |  |  |  |  |  | https://www.adafruit.com/product/4899

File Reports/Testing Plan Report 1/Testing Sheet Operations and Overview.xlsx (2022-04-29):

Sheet: Testing Overview
Wa

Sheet: Test 1 Water-Sealing and Data R
REQUIRED MATERIALS
Item | Name | Quantity | Notes
1 | PUCKFish Prototype board V0.1 | 1
2 | PUCKFish Prototype Housing V0.1 | 1
3 | PUCKFish Prototype Chassis V0.1 | 1
4 | Laptop (any) | 1
5 | Protractor | 1
OP 1: SETUP
Op | Description | Initials | Notes
1.1 | Connect Prototype board ot laptop
1.2 | Confirm Battery levels exceed 50 percent
1.3 | Install prototype board onto prototype chassis
1.4 | Begin collecting data by starting up the imu, Record the start time in the notes
1.5 | Wrap teflon tape on threading, clockwise
1.6 | Buyoff that housing is prepared for submerging, Check for potetntial leak areas
OP 2: TESTING PROCEDURE
OP | Descrition | Initials | Notes
2 | Submerge the Prototype in some volume of water so that it is totally submerged | wa | skip past no water
2.1 | Begin running the code for IMU according to best practice | wa
2.2 | Using a protractor, angle the housing parrellel to gravity vector, Record start time and end time in notes | wa | Start Time: 284s End time 300s
2.3 | Using a protractor, angle the housing 45 degrees agianst gravity vecotr, Record start time and end time in notes | ah | Start Time: 375s End Time: 390s
2.4 | Using a protractor, angle the housing perpendicular to gravity vector, Record start time and end time in notes | ah | Start Time: 745s End Time: 760s
2.5 | Remove the prototype from the volume of water
OP 3: BREAKDOWN PROCEDURE
OP | Description | Initials | Notes
3 | Dry off the outside of the prototype so that it is no longer wet | wa | NP
3.1 | Open the prototype housing | AN
3.2 | Remove chassis from the housign | AN
3.3 | Shutdown pcb per best practice
OP 4: DATA COLLECTION AND ANALYSIS
OP | DESCRIPTION | Initial | Notes
4 | export data to a text file
4.1 | Seperate Data via the timestamps collected in ops 2.3-2.6
4.2 | Gather Averages of the data given in "TEST 1, DATA ANALYSIS" in this google sheet
4.3 | Determine best path forward for further data analysis
Measureable Criteria per Test Goals
1 | IMU Data, In whatever form
2 | Waterproofing success?
3 | Determine best path for data analysis and collection
 | 42.41150082

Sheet: TEST 1 DATA ANALYSIS
Data | Seconds | AccelX | AccelY | AccelZ | Time | Accel X | AccelX | Accel Y
Seconds: 86.71 | Seconds: 86.71 | Accel X: -0.32 | Accel Y: -9.39 | Accel Y: -9.39 | 86.71 | -0.32 | -9.39 | -9.39
Accel X: -0.32 | Seconds: 90.74 | Accel X: -0.42 | Accel Y: -9.50 | Accel Y: -9.50 | 90.74 | -0.42 | -9.5 | -9.5
Accel Y: -9.39 | Seconds: 92.75 | Accel X: -0.35 | Accel Y: -9.46 | Accel Y: -9.46 | 92.75 | -0.35 | -9.46 | -9.46
Accel Z: 0.95 | Seconds: 94.76 | Accel X: -0.21 | Accel Y: -9.50 | Accel Y: -9.50 | 94.76 | -0.21 | -9.5 | -9.5
RSSI: -64 | Seconds: 96.78 | Accel X: -0.87 | Accel Y: -8.99 | Accel Y: -8.99 | 96.78 | -0.87 | -8.99 | -8.99
Got: Packet #: 42.00 | Seconds: 98.79 | Accel X: 9.94 | Accel Y: 0.32 | Accel Y: 0.32 | 98.79 | 9.94 | 0.32 | 0.32
Seconds: 90.74 | Seconds: 100.80 | Accel X: 9.58 | Accel Y: 0.58 | Accel Y: 0.58 | 100.8 | 9.58 | 0.58 | 0.58
Accel X: -0.42 | Seconds: 102.82 | Accel X: 9.54 | Accel Y: 0.74 | Accel Y: 0.74 | 102.82 | 9.54 | 0.74 | 0.74
Accel Y: -9.50 | Seconds: 104.83 | Accel X: 9.46 | Accel Y: 0.68 | Accel Y: 0.68 | 104.83 | 9.46 | 0.68 | 0.68
Accel Z: 1.00 | Seconds: 106.85 | Accel X: 9.39 | Accel Y: 1.17 | Accel Y: 1.17 | 106.85 | 9.39 | 1.17 | 1.17
RSSI: -53 | Seconds: 108.86 | Accel X: 9.32 | Accel Y: -2.01 | Accel Y: -2.01 | 108.86 | 9.32 | -2.01 | -2.01
Got: Packet #: 43.00 | Seconds: 110.87 | Accel X: 9.68 | Accel Y: 0.42 | Accel Y: 0.42 | 110.87 | 9.68 | 0.42 | 0.42
Seconds: 92.75 | Seconds: 112.89 | Accel X: 9.42 | Accel Y: -0.02 | Accel Y: -0.02 | 112.89 | 9.42 | -0.02 | -0.02
Accel X: -0.35 | Seconds: 114.90 | Accel X: 9.39 | Accel Y: 0.50 | Accel Y: 0.50 | 114.9 | 9.39 | 0.5 | 0.5
Accel Y: -9.46 | Seconds: 116.91 | Accel X: 9.24 | Accel Y: 0.34 | Accel Y: 0.34 | 116.91 | 9.24 | 0.34 | 0.34
Accel Z: 0.99 | Seconds: 118.93 | Accel X: 9.91 | Accel Y: 0.86 | Accel Y: 0.86 | 118.93 | 9.91 | 0.86 | 0.86
RSSI: -57
Got: Packet #: 44.00
Seconds: 94.76
Accel X: -0.21
Accel Y: -9.50
Accel Z: 0.54
RSSI: -57
Got: Packet #: 45.00
Seconds: 96.78
Accel X: -0.87
Accel Y: -8.99
Accel Z: 3.15
RSSI: -58
Got: Packet #: 46.00
Seconds: 98.79
Accel X: 9.94
Accel Y: 0.32
Accel Z: 2.39
RSSI: -58
Got: Packet #: 47.00
Seconds: 100.80
Accel X: 9.58
Accel Y: 0.58
Accel Z: 0.88
RSSI: -66
Got: Packet #: 48.00
Seconds: 102.82
Accel X: 9.54
Accel Y: 0.74
Accel Z: 1.50
RSSI: -61
Got: Packet #: 49.00
Seconds: 104.83
Accel X: 9.46
Accel Y: 0.68
Accel Z: 1.06
RSSI: -63
Got: Packet #: 50.00
Seconds: 106.85
Accel X: 9.39
Accel Y: 1.17
Accel Z: 1.60
RSSI: -60
Got: Packet #: 51.00
Seconds: 108.86
Accel X: 9.32
Accel Y: -2.01
Accel Z: -0.94
RSSI: -53
Got: Packet #: 52.00
Seconds: 110.87
Accel X: 9.68
Accel Y: 0.42
Accel Z: 0.22
RSSI: -57
Got: Packet #: 53.00
Seconds: 112.89
Accel X: 9.42
Accel Y: -0.02
Accel Z: 1.00
RSSI: -52
Got: Packet #: 54.00
Seconds: 114.90
Accel X: 9.39
Accel Y: 0.50
Accel Z: 1.09
RSSI: -51
Got: Packet #: 55.00
Seconds: 116.91
Accel X: 9.24
Accel Y: 0.34
Accel Z: 0.56
RSSI: -54
Got: Packet #: 56.00
Seconds: 118.93
Accel X: 9.91
Accel Y: 0.86
Accel Z: 0.49
RSSI: -55

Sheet: Test 2 Data Analysis
Constant Parameters
rho Water | 997 | kg/m^3
g | 9.8 | m/s^2
massPuckfish |  | kg
volumePuckfish | 0.001389999957 | m^3
Bouancy Force | 13.58113358 | N
Gravity Force | 0 | N
Force Tension Y | 13.58113358 | N
Force Tension X | 0 | N
Angle |  | Radians
Angle Decompositon
Accel X | Accel Y | Accel Z

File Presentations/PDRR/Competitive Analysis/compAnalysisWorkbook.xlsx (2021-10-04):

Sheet: Competitors
Objective: Collect competitors and compare across our hypothetical operating points
Competitor | Source | Major Features
LobsterLift | https://conservationx.com/project/id/225/lobsterlift | Self lifting, no other measurment instraments
lasTrap | http://thelobstertrapcompany.com/ | Novel materials, plastic construction
LobsterNet | http://gloucesterinnovation.com/lobsternet/ | measures temperature and ph
Sensor thing | https://mlcalliance.org/2019/07/03/new-sensors-track-lobsters-from-trap-to-dealer/ | Tracks lobsters on boat to dealer
eMOLT | https://phys.org/news/2009-03-lobster-high-tech.html | Bottom Temperature, pH
Hondex Depth Sensor | http://hondexne.com/sounders-from-hondex-marine-electronics/ | measures depth
TimeZero | https://mytimezero.com/tz-professional | Wind depth and sometimes temp
Various Chartplotters | https://www.bandg.com/bg/type/chartplotter/ | positions and direction
DrinkTank | https://www.drinktankthat.com/lobsterhack | Common problem folks want to solve
Oregan State U | file:///C:/Users/willa/Downloads/ShearmanRKippDeployingDissolvedOxygen.pdf | dissolved oxygen

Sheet: Comparison
Product | DevTime (months) | Temperature | OxLevel | pH | Depth | Location | Salinity | Current Velocity | Ambiant Light | Self-Lifting | "Modern" Materials
PUCKFish | 6 | 1 | 1 | 1 | 1 | 1 | 1 | 1 | 1 | 0 | 0
Major Competitors
TimeZero | 6 | 0.5 | 1 | 0 | 1 | 1 | 1 | 1 | 0 | 0 | 0
eMOLT | 0 | 1 | 0 | 1 | 0 | 1 | 1 | 1 | 0 | 0 | 0
Minor Competitors
LobsterNet | 14 | 1 | 1 | 1 | 1 | 1 | 0 | 0 | 0 | 0 | 0
OSU | 0 | 1 | 1 | 0 | 0 | 0 | 0 | 0 | 0 | 0 | 0
Non-Competitors
Hondex | 0 | 0 | 0 | 0 | 1 | 1 | 0 | 0 | 0 | 0 | 0
lasTrap | 0 | 0 | 0 | 0 | 0 | 0 | 0 | 0 | 0 | 0 | 1
LbsterLift | 8 | 0 | 0 | 0 | 0 | 1 | 0 | 0 | 0 | 1 | 0
Relevant Patents
https://patft.uspto.gov/netacgi/nph-Parser?Sect1=PTO2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
https://patft.uspto.gov/netacgi/nph-Parser?Sect1=PTO2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

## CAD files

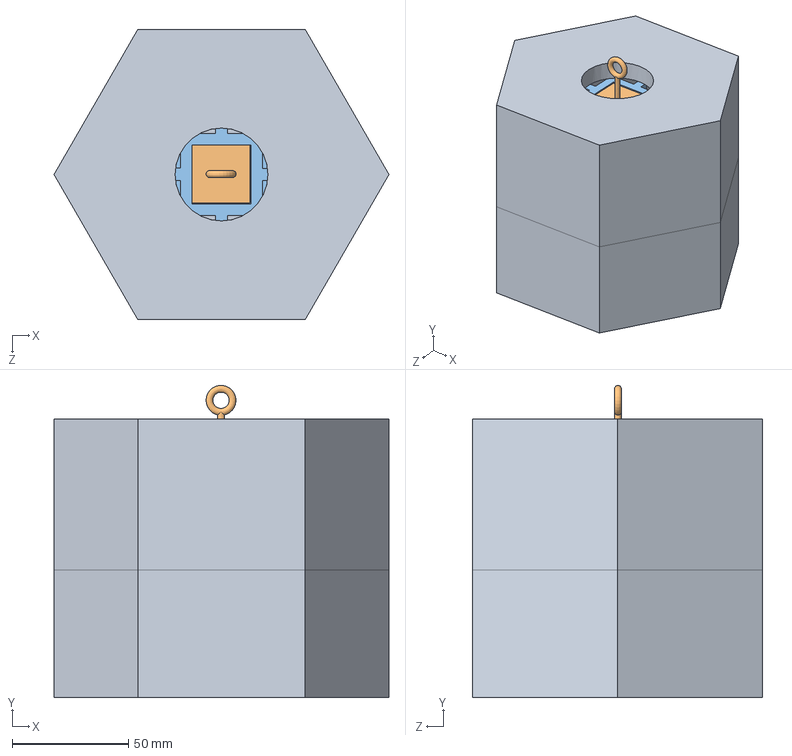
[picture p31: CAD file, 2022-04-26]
Structure CAD/mold assembly.SLDASM
144.3 x 134.5 x 125.0 mm
mold_master
mount
Skeleton_9

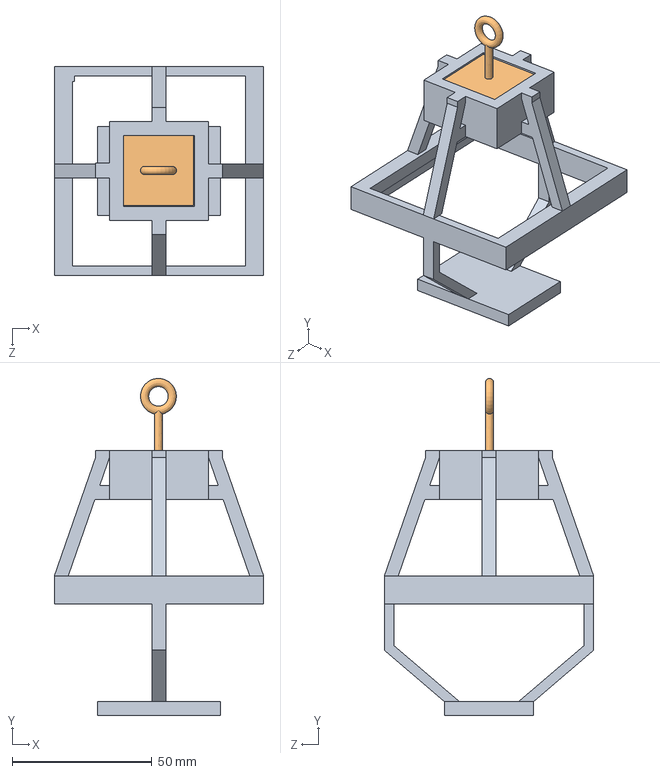
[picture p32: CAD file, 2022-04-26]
Structure CAD/Skeleton/skeleton_assy.SLDASM
75.0 x 120.7 x 75.0 mm
mount
Skeleton_9

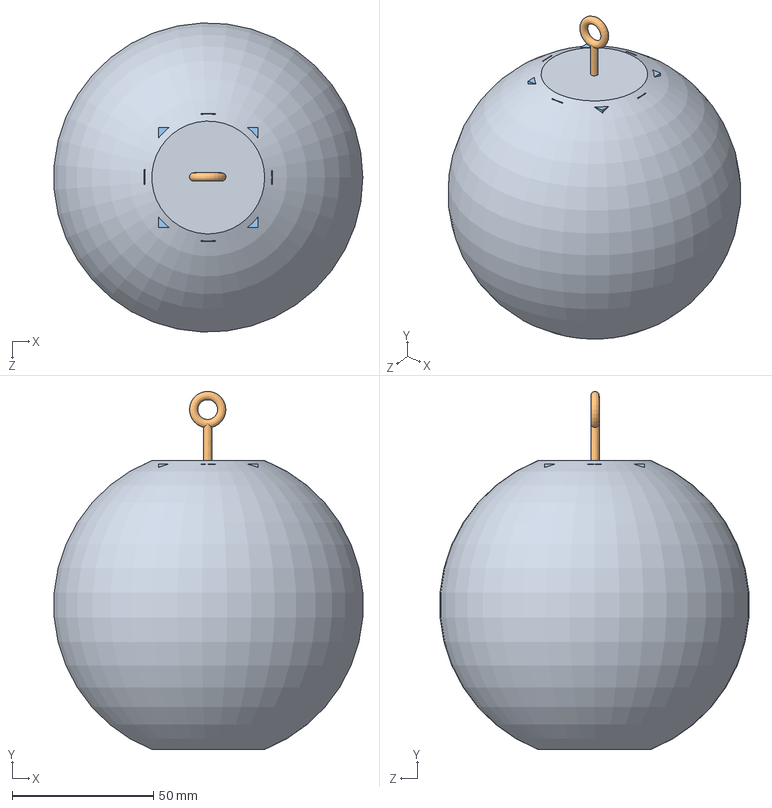
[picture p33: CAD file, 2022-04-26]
Structure CAD/final assembly.SLDASM
109.5 x 126.9 x 109.6 mm
orb
mount
Skeleton_9

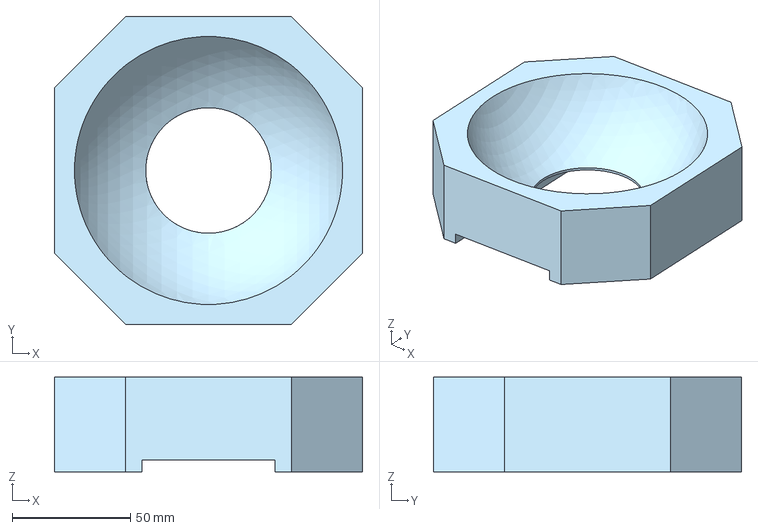
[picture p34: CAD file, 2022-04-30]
Structure CAD/ChargingDock.step
130.0 x 130.0 x 40.0 mm

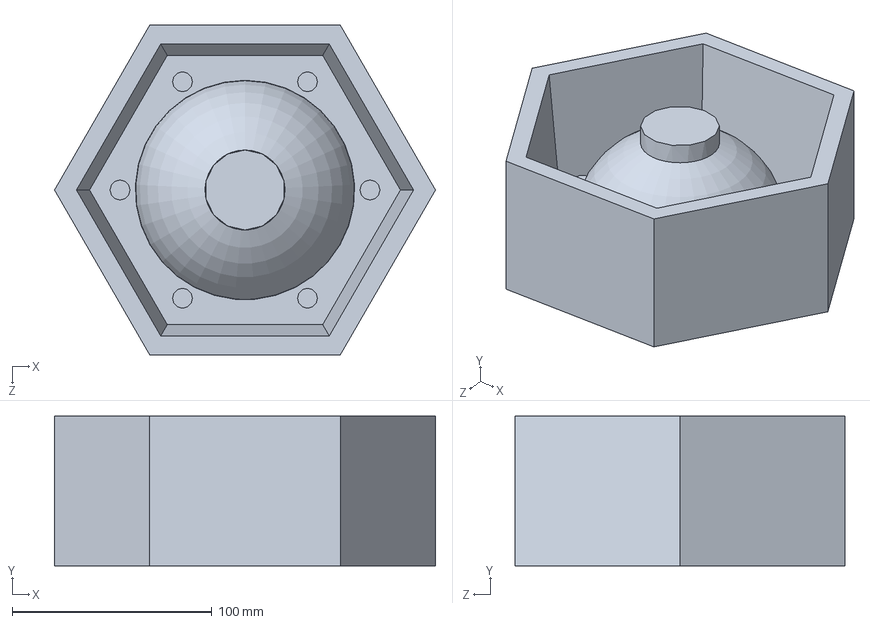
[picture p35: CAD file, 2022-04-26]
Structure CAD/Mold/metamold/metamold_upper.SLDPRT
190.5 x 75.0 x 165.0 mm

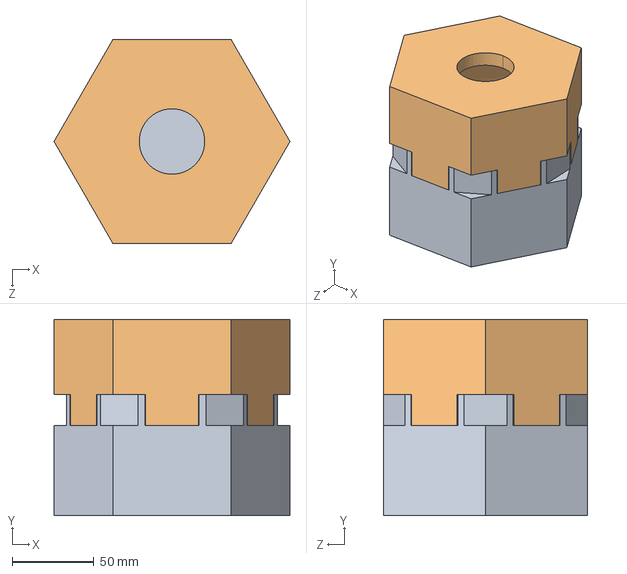
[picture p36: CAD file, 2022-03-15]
Structure CAD/Mold/mold_master.STEP
144.3 x 120.0 x 125.0 mm

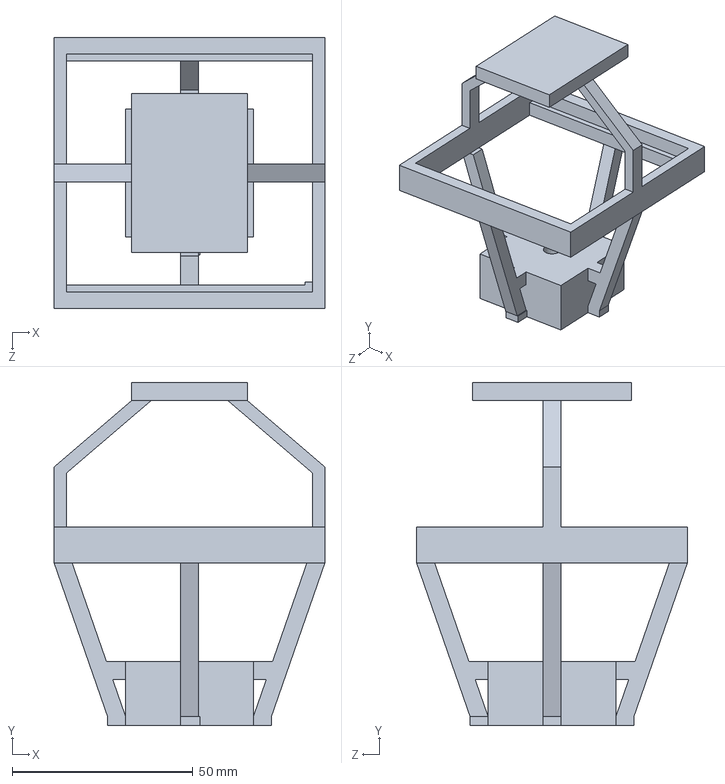
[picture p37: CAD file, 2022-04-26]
Structure CAD/Skeleton/Skeleton_9.SLDPRT
75.0 x 95.0 x 75.0 mm

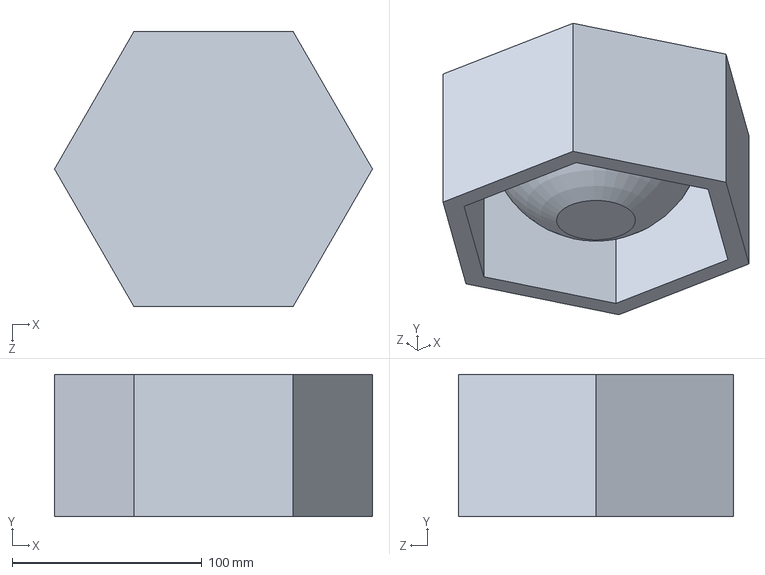
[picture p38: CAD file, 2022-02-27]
Structure CAD/Mold/metamold/metamold_downer.SLDPRT
167.4 x 75.0 x 145.0 mm

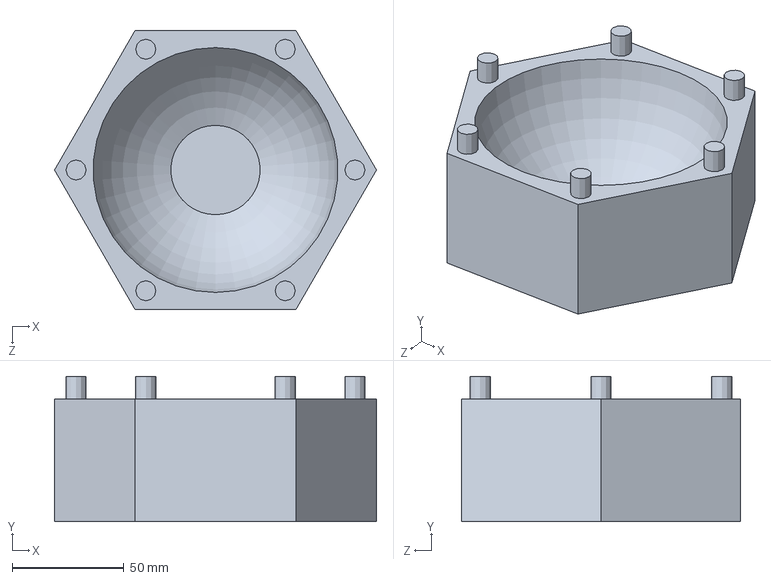
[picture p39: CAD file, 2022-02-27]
Structure CAD/Mold/mold_downer.SLDPRT
144.3 x 65.0 x 125.0 mm

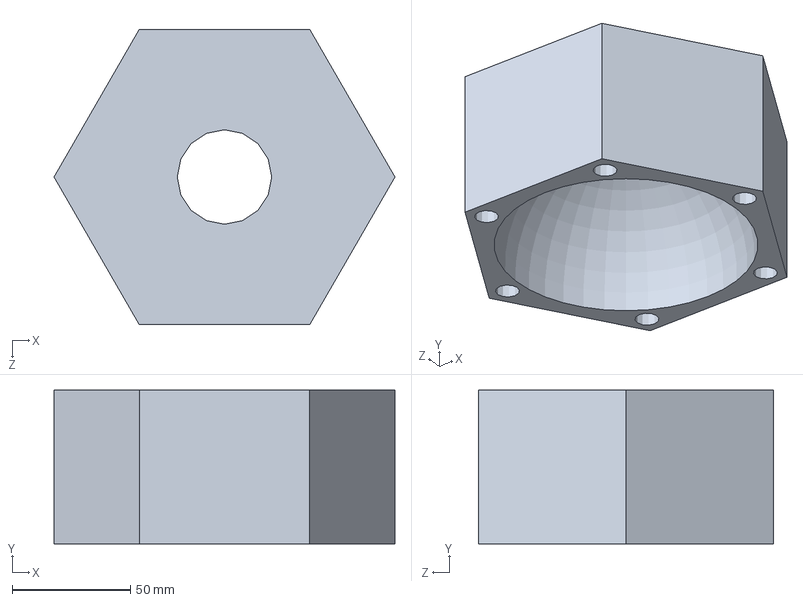
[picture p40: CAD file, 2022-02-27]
Structure CAD/Mold/mold_upper.SLDPRT
144.3 x 65.0 x 125.0 mm

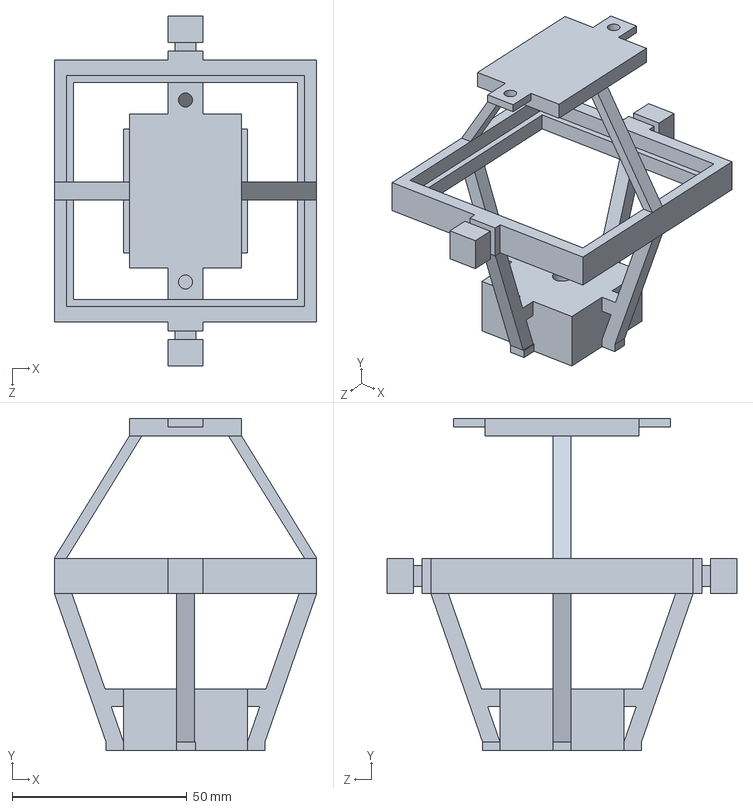
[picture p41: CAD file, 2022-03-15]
Structure CAD/Skeleton/Skeleton_8.SLDPRT
75.0 x 95.0 x 100.0 mm

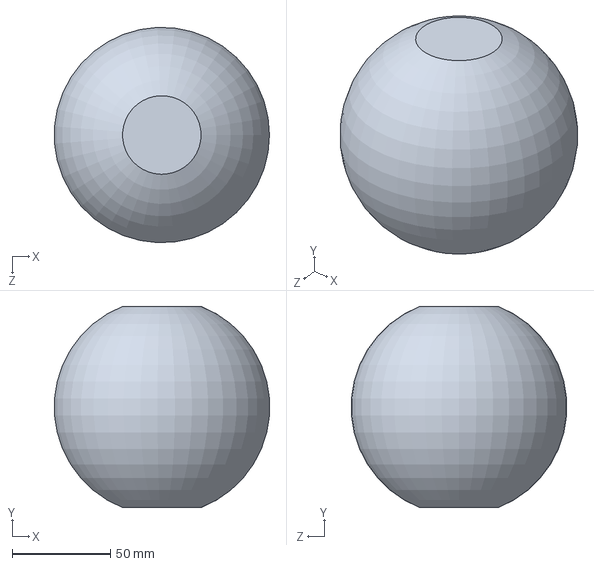
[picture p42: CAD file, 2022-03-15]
Structure CAD/orb.SLDPRT
109.5 x 102.5 x 109.6 mm

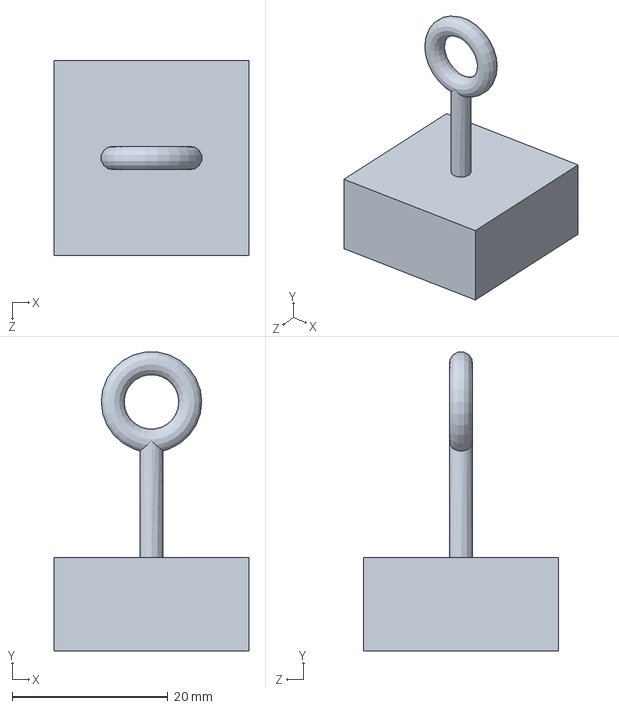
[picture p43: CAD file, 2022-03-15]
Structure CAD/Skeleton/mount.SLDPRT
25.0 x 38.4 x 25.0 mm

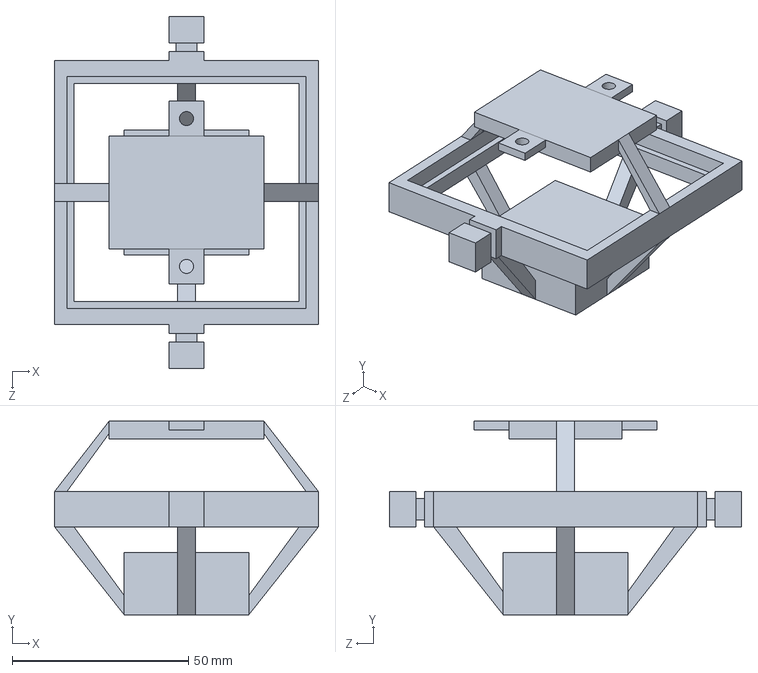
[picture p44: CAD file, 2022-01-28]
Structure CAD/Skeleton/Skeleton_7.SLDPRT
75.0 x 55.0 x 100.0 mm

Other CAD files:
Structure CAD/Skeleton/Skeleton_6.SLDPRT
Structure CAD/Skeleton/Skeleton_5.SLDPRT
Structure CAD/Skeleton/Skeleton_4.SLDPRT
Structure CAD/Skeleton/Skeleton_2.SLDPRT
Structure CAD/Mold/metamold/metamold_downer.STL
Structure CAD/Mold/metamold/metamold_upper.STL
Structure CAD/Mold/mold_downer.STL
Structure CAD/Mold/mold_master.SLDPRT
Structure CAD/Mold/mold_upper.STL
Structure CAD/Skeleton/Skeleton_1.SLDPRT
Structure CAD/Skeleton/Skeleton_3.SLDPRT
Structure CAD/Skeleton/Skeleton_8.STL
Structure CAD/Skeleton/Skeleton_9.STL

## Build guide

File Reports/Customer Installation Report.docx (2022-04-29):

Memo


Senior Design

ENG EC 463 / 464

To: Professor Pisano

From: PUCKFish Team

Team: PUCKFish, Team 34

Date: 4/29/2022

Subject: Customer Installation Report

1.0 Introduction

PUCKFish is a sensor array that will be emplaced underwater to review indicators of Lobster environments to aid in developing models to increase lobster catch yield. PUCKFish is sponsored by Andy Whitman and Anthony Burn of Fathom Fishing, a small fishing start-up based out of Massachusetts. This memo covers the installation to the customer of the current Prototype of PUCKFish, success categories, as well as path forward.

2.0 Customer Installation

2.1 Review of Test

The test consisted of proving PUCKFish's capabilities on April 29th, 2022 including the PUCKFish team as well as Andy Whitman. This included showing the wireless charging at work, submerging the device into a bucket of water, and then retrieving the data from the device. During the test for Fathom Fishing, PUCKFish successfully charged wirelessly via Qi receiver. Upon submersion, the device continued to collect and transmit sensor data over LoRa radio to a laptop that was used as the representation of the base station. As was discussed, only two full prototypes would be required to complete Fathom Fishing’s requirements.

  2.2 Review of Requirements

Below is a table of Requirements, success parameters, and changes to reflect the requirements of the customer.

Original Requirement | Success? | Changes | Notes | Status
3 Complete Devices | Requirement Change | 2 Complete Prototypes Made, one does not have functioning pressure sensor, One board left unpoured in epoxy for demo/customer use | Only 2 devices were needed for successful project completion. The 1st device was treated as a prototype | Modified
Collection of information in water area around a lobster trap. The following characteristics must be measured. - Dissolved Oxygen - Depth - Salinity - Temperature - Water Current and Velocity - Ambient Light | The Success Parameters are as follows. - Dissolved Oxygen – Yes - Depth – Yes - Salinity- Yes - Temperature- Yes - Water Current and Velocity – Yes - Ambient Light- Yes | N/A | Metrics are all collected in the second prototype. First prototype fails to capture pressure data due to software failure, and fails to transmit dissolved oxygen/salinity data due to packet truncation. | Modified
Poll Sensors at least once per hour | Yes | N/A | N/A | Original
Last 10 Days off of Single charge | Yes/TBD | N/A | From all initial testing, this seems to be successful, however will be fully tested in environment at a later date as discussed in 2.3 | Original
Compact Form Factor | Yes | N/A | N/A | Original
Rechargeable with shipboard marine Batteries | Yes | N/A | Rechargeable with any QI wireless charging pad | Original
Be Robust Enough to withstand constant Marine Conditions | Yes | N/A | Will be tested in the environmental test | Original
Automatically detect when trap surfaces/descends | Yes | N/A | This feature functions on the second prototype unit. It does not on the first prototype unit due to pressure sensor failure. | Original
Transmits data to shipboard base station when trap surfaces, stored in common devices and formats | Yes | N/A | N/A | Original
Unit Cost, $150 for prototype | Yes | N/A | | Original

  2.3 Assessment and Path Forward

The test was deemed a success from the customer, with the exception of the pressure sensor failure on the first prototype unit. This was attributed to a software issue specific to the first prototype unit. All other aspects of the project were successful.

For the Path Forward, it was decided that additional testing would be done with the second prototype unit with the working pressure sensor, as well as figuring out how to reflash software on the PUCKFish wirelessly to prevent permanent software problems after encasing units in epoxy. In addition, a full test within the environment was scheduled to test the device operationally. This test will involve placing PUCKFish at depth within the ocean as soon as weather permits.

3.0 Customer Acceptance Email

April 29th, 2022, 2:27 pm

Hey Team,

Wanted to just follow up on the first round of in water testing of the devices. Really pleased with how the device is coming along and how simple everything is to the end user!

The wireless charging appeared to work wonderfully, and without any electrical penetrations or connections, there are nearly no interfaces to be damaged by the user or environment.

Pressure data is going to be crucial and it sounds like it was a hardware not software issue on the first device that prevented collection of that. I believe Alex was on top of it though, and it isn’t expected to be an issue on the next two prototypes.

I’m really excited to see the next completely buttoned up device deployed out in the environment as the weather gets a little better. And per our meeting last weekend a completely assembled device without potting (for future debugging and work).

Let me know if I missed anything, keep pushing to the finish line!

Andy Whitman

Co-Founder, Fathom Fishing

(207) 974-6518

www.fathom.fishing

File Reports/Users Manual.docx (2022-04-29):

# Boston University

# Electrical & Computer Engineering

# EC464 Capstone Senior Design Project

# User's Manual

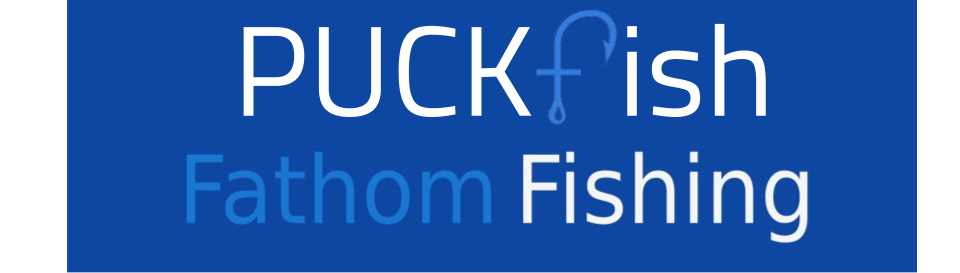
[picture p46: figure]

Submitted to

Andy Whitman and Anthony Burnes

Fathom Fishing

abyrne19@bu.edu

andy@fathom.fishing

by Team 34 PUCKFish

Team Members

Victoria Thomas vmthomas@bu.edu

Alex Necakov alexrn@bu.edu

Peter Ha peterha@bu.edu

Will Aracri waracri@bu.edu

Ammar Hussain hussaina@bu.edu

Submitted: 4/18/2022

#### 1. PUCKfish

#### 2. Table of Contents

PUCKfish 2

Table of Contents 2

Executive Summary 4

Introduction 1

System Overview and Installation 2

Overview block diagram 2

Physical description 3

Installation, setup, and support 3

PUCKFish Operating Modes 5

Operating Mode 1: Normal Operation 5

Operating Mode 2: Abnormal Operations 5

Safety Issues 5

Technical Background 6

4.1 Introduction: Lobster Ecology and Environment 6

4.2 Sensors: Modus Operandi and Selection 7

4.2.1 Temperature and Depth 7

4.2.2 Ambient Light 7

4.2.3 Dissolved Oxygen 8

4.2.4 Salinity 8

4.2.5 Current Speed and Direction 8

4.3: Enclosure and Protection Against the Elements 9

4.3.1: Waterproofing 9

4.3.2: Pressure Resistance 9

4.3.3: Floatation 9

4.4: Data Transmission and Charging 10

4.4.1: Data Transmission 10

4.4.2: Charging 10

Relevant Engineering Standards 11

Cost Breakdown 12

Appendices 14

Appendix A – Team Information 14

Team History

Alex, Victoria, Peter and Will met during freshman year through the Rocket Propulsion Group. They have worked together on various projects for the team including liquid rocket engines, test stands, and other assorted infrastructure. After a short break due to the pandemic, the team found themselves back in Boston for senior year, ready to team up again to take on a multi-disciplinary project.

Ammar and Peter went to high school together in Boston. Seeing the requirement we had for an extra hand on the electrical engineering team, Ammar fit right in and got to work as one of our two electrical engineers.

# 2. The team is excited to be working together with BU alumni and Fathom Fishing. The team hopes to produce a piece of engineering that supports local industry and protects the right whale population off the coast of its home in New England.

# 3. Executive Summary

The lobster fishing industry has largely remained unchanged since its emergence in the mid 1800s. The primary strategy for lobster fishing has also remained unchanged since the mid 1800s, where fishermen place traps upon habitual routes with no promise of a good catch yield This strategy leads fishermen to place extraneous traps throughout the ocean in areas unlikely to house lobsters. These extraneous traps have a significant environmental impact on other marine life such as the endangered North American Right Whale. The whales become caught in the lines of lobster traps and then perish, making “line entanglement” the leading cause of unnatural death among this population. Due to these environmental concerns, fishermen are limited by law in the number of traps they can place.

PUCKFish solves this by providing low-cost, rugged instrumentation to fisheries. This device puts the tools for data acquisition and analysis in the hands of trappers providing information to inform data-backed decisions about where to place lobster traps and optimizing fishing hauls. We will be producing three PUCKFish data collection devices each of which records six key metrics relevant to lobster activity on the seafloor. PUCKFish will be the first business-grade, all-in-one data collection and analysis suite specifically for lobster fishermen. Its low cost and ability to collect metrics most critical to locating and tracking lobsters will revolutionize the lobster fishing industry.

# 1 Introduction

PUCKFish is an instrumentation package designed to provide the most relevant data to lobster trappers. This data will significantly reduce the number of traps needed to provide the same catch, and thus the trash and emissions produced through fishing activities.

Thus, PUCKFish must be extremely resistant to water, corrosion, pressure, cold, and, potentially, oceanic wildlife. These issues are all addressed concurrently by wholly immersing the electronics in a non-conductive, eco-friendly epoxy resin. The resin completely isolates the internal electronics from the outside environment while still allowing us to mold the resin as necessary to allow the appropriate sensors external access. PUCKFish can survive up to 11,000 psi, over 20 times what we expect on the ocean floor, for over two weeks.

Sensors with external access were specially sourced to be appropriate for the extremely harsh oceanic conditions, with additional sealing precautions taken around their base. These additional sealing measures prevent any possible ingress, for example, at the interface between the pressure sensor and the PCB. As we cannot put a wired charging port on PUCKFish, it instead uses inductive wireless charging.

Because PUCKFish will be left at depth for extended periods, it must be efficient with its energy usage to maximize the operation time available on a single charge. With a 500 mAh battery, and an extremely low polling rate, PUCKFish will be able to last for up to two weeks underwater. And should it lose power, all data is backed up to a 512MB SD card locally. With a packet size of merely 256 bytes, saturating the SD card is essentially impossible given the rigid schedules of the lobster trapping industry.

We are proud to present PUCKFish. Further technical information and operational instructions are available below.

# 2 System Overview and Installation

PUCKFish is a translucent, spherical, underwater data collection device with one flat face for standing and one exposed eye-bolt for mounting. The outer shell of the PUCKFish is made of translucent epoxy. The interior (or core) of the device consists of a printed circuit board mounted on a white plastic skeleton, with a microcontroller and several sensor boards attached to it. These sensor boards capture water current speed/direction, temperature, ambient light, salinity, dissolved oxygen, and pressure data. While underwater, the device collects and stores data in JSON format on an SD card. When the PUCKFish surfaces from the water, it automatically transmits stored data to a base station using its LoRa radio transceiver.

## 2.1 Overview block diagram


## 2.2 Physical description.


Figure 2: Skeleton and Mold Model Figure 3: PCB with Sensors

## 2.3 Installation, setup, and support

Each PUCKFish device comes pre-built with no assembly required. The device needs to be charged using a Qi wireless charging pad. The device must be attached to a lobster trap line with the eye-bolt with enough slack for it to drift about underwater. The PUCKFish should be fully charged before use and the exterior sensor ports must not be obstructed to ensure full data collection and recovery. Software will automatically run on the PUCKFish while it is powered on. Receiving data from the PUCKFish will require users to run Fathom Fishing’s base station software.

For the dissolved oxygen sensor, the galvanic probe requires periodic recalibration with an electrolyte solution. Over time, this solution will be depleted and will eventually need to be refilled. To refill the probe, enough of the probe needs to be exposed to allow for the cap to be removed to refill the solution. When filling the solution, the user must use a standard syringe to fill the cap to its brim with the solution. Once The solution is filled, the cap must be properly screwed back on to ensure no leakage and to prevent corrosion.

# 3 PUCKFish Operating Modes

## 3.1 Operating Mode 1: Normal Operation

In normal operating mode, users will collect and receive data from the PUCKFish as follows:

1. Charge PUCKFish with charging pad
2. Affix PUCKFish to trap line
3. Submerge PUCKFish underwater
4. Run Fathom Fishing base station software
5. Pull up trap with attached PUCKFish
6. Receive transmitted data on base station

PUCKFish devices will collect sensor data from the undersea environment once per hour during normal operation. Future models may have configurable polling frequency.

## 3.2 Operating Mode 2: Abnormal Operations

Abnormal operations include exterior sensor ports being obstructed, the device running out of battery, or damage due to loss of shell integrity.

If sensor ports are obstructed, the PUCKFish will not be able to retrieve the full suite of data from the environment. Any blockage or corrosion should be cleared out before future use.

If the PUCKFish runs out of battery, the data it has collected will be kept in persistent storage. When recharged, the device will be able to transmit all previously collected data.

If shell integrity is compromised on a PUCKFish unit, the device should be discontinued from use as we can no longer guarantee water/pressure proofing. Continued use will further damage the device and potentially lead to a loss of the data stored on PUCKFish.

## 3.3 Safety Issues

It is important to make sure the PUCKFish device is firmly affixed to the trap line during use. If the device comes loose from the line, it will most likely be unrecoverable and damage the lobster habitats.

Do not:

4. Load PUCKFish or use PUCKFish to tow or lift loads.
5. Attempt to access electronics inside PUCKFish’s epoxy enclosure.
6. Add additional loading points to PUCKFish. Use only the eye bolts provided.

# 4 Technical Background

## a. 4.1 Introduction: Lobster Ecology and Environment

Lobsters are scavenging crustaceans which subsist off of decaying organic material at the bottom of certain ocean zones. They are typically found in northern cold-water environments. Although there are many species of lobster, the basics of ecology and environment are similar between them, especially in the North American territories where large populations of commercial interest exist. Although basic migration information is known about lobsters as they move closer or further away from shore depending on the season, little is known exactly on the best location to find any particular species during a migration period.

Despite uncertainties of specific locations, general locations are known of habitation on the ocean floor. It is generally understood that lobsters may live in ocean zones as deep as 1100 feet.

Because of the uncertainty of preferred habitation zones of lobsters, PUCKFish applies basic marine biology to inform the choice of sensors to find population densities for lobsters. An environment’s suitability for marine life depends on several major factors.

1. Temperature
  a. Different marine species prefer different temperatures in relation to their body temperature to function optimally. Temperature can affect basic biological processes such as metabolism, reproduction, and growth.
2. Depth
  a. Pressure differences affect the physiological structure of marine life. Fish or animals may be better suited to either higher or lower pressures depending on their role in the ecosystem.
3. Ambient Light
  a. Marine plant life depends upon photosynthesis to produce energy. As plant life or algae are commonly the base of the ecosystem, different light amounts may point to more dense populations of plant life, and thus, other forms of marine life.
4. Dissolved Oxygen
  a. Marine life extracts dissolved oxygen from water in order to maintain biological function. The amount of oxygen available in the water tends to increase proportionally with the availability of marine life
5. Current Speed and Direction
  a. Current speed and direction can show migration patterns as well as still spots where habitats can form without the force of the current moving them around.
6. Salinity
  a. Salinity affects marine life, as they typically have optimal ranges in which they prefer to reside. The biological effects of salt impact functions like osmosis and metabolic processes which are key processes that sustain life for aquatic life.

The ideal sensor cluster and housing to collect this data may be developed in order to provide a model with information from basic principles of marine biology and a general understanding of lobster habitats.

## b. 4.2 Sensors: Modus Operandi and Selection

This section covers the sensors that measure the factors that indicate higher population density of lobsters.

### i. 4.2.1 Temperature and Depth

PUCKFish uses a piezoresistor sensor which is ported directly to a 24 bit output to read temperature and pressure directly. Piezoresistor pressure sensors make use of the piezoresistor mass-spring-like effect in order to read back pressures. When the piezoelectric resistor is put under pressure and subjected to temperature, it produces a change in resistance, which is then read by the sensor as data to the board. The model used in PUCKFish is a TE Connectivity MS5837-30BA . Pressure can be used to find the depth. Water has a semi-consistent density and models of ocean depth exist to produce a conversion between the pressure read and the depth of the water.

### ii. 4.2.2 Ambient Light

PUCKFish uses a photodetector to measure the ambient light in its environment. It uses a photodiode, which has a similar spectral response to the human eye. When light enters the photodiode, it generates an electric current which the sensor then identifies, digitizes, and converts to a measurement of Lux, the SI measurement for light. The model used by PUCKFish is a light sensor with a breakout board, the Adafruit BH1750 Light Sensor.

### iii. 4.2.3 Dissolved Oxygen

PUCKFish uses an electro-galvanic oxygen sensor in order to measure the dissolved oxygen within the water. The probe contains a fuel when placed in water allowing a chemical reaction to occur with both the water and the oxygen. This reaction releases free electrons which then, with the galvanic probe, create a voltage that is measured and corresponds to the amount of dissolved oxygen in percent. The sensor then converts this percentage of oxygen to an analog signal which then can be read by the computer onboard PUCKFish. The model of sensor onboard PUCKFish is the Gravity™ Analog Dissolved Oxygen Meter.

### iv. 4.2.4 Salinity

PUCKFish uses a current meter to measure the salinity of the water. Electrical conductance through water is proportional to the electrolytes. In sea water’s case this electrolyte is salt. The salinity of the water can be backed out through look-up table to determine the required amount of salinity found in the water. The current sensor used to determine the salinity is the DIODES ZXCT1107SA-7.

### v. 4.2.5 Current Speed and Direction

Because PUCKFish is buoyant, the whole device shifts on a line attached to the lobster trap. Because of this, the angle of the device relative to the gravity vector can be used to determine trends of current speed and direction. This angle is created by the current of the water which creates a hydrodynamic force on the device as it pushes past it. In order to measure the amount the PUCKFish is pushed to the side as well as the direction it is doing so, an IMU, or inertial measurement unit, is used. The IMU onboard PUCKFish is the MPU-6050 on a breakout board provided by Adafruit.

## c. 4.3: Enclosure and Protection Against the Elements

### i. 4.3.1: Waterproofing

Because PUCKFish must operate underwater, the electronics must be protected from water getting inside. To counter water intrusion, an internal skeleton holds electronic components in place while a marine epoxy forms a protective shell around the electronics. Any sensor that requires access to the exterior of the device has sealing provisions so water has no way of penetrating into the epoxy enclosure.

### ii. 4.3.2: Pressure Resistance

PUCKFish is required to operate at a maximum depth of 1,100 feet below the water’s surface where it must withstand 34.4 atm of pressure, or 3 MPa. In order to avoid damage to the structure or electronics, the device must be made of a material that can not only withstand the pressure, but also resist compression. The device is made of marine epoxy. This marine epoxy is resistant to corrosion and has a compressive strength of 85.4 MPa. The epoxy will withstand the pressures expected and limit the compressive strain inside the device to reasonable levels.

### iii. 4.3.3: Floatation

PUCKFish must float to measure current with the IMU. By implementing Archimedes' principle of buoyancy, it can be shown that the device has a specific density greater than that of water. An underwater float is introduced in order to provide floatation. The value of this float generates approximately double the force required to make the device float.

## d. 4.4: Data Transmission and Charging

### i. 4.4.1: Data Transmission

Because water blocks radio waves, the device must be retrieved to collect the data stored on the PCB. In order to transmit data, PUCKFish has an onboard LoRa radio to transmit to a base station. The data transmitted is formatted into a csv file that can then be read and fed to models of the user’s choosing.

### ii. 4.4.2: Charging

Charging ports provide a possible entry point for salt water as well as an opportunity for charging leads to rapid corrosion because of their exposure to water. As a result, PUCKFish uses an inductor to charge wirelessly. A magnetic field is generated that excites a current to move in a receiving charger inside PUCKFish through the epoxy covering.

# 5 Relevant Engineering Standards

PUCKFish must adhere to a set of various engineering standards in each of its respective components. From the electronics perspective, PUCKfish is an array of various sensors each with their own software driver to communicate with the microcontroller. The sensors all adhere to I2C specification. For the dissolved oxygen sensor, ambient light sensor, and the current measuring IMU, we had access to existing open source code provided by the respective manufacturers, Atlas Scientific and Adafruit respectively. For the pressure sensor, we had to write our own driver. Similarly, for the salinity sensor, we had to write a driver that would take the output of the current sensing diode and convert that to a salinity measurement through the following formula (Sciencing (https://sciencing.com/convert-specific-gravity-weight-6018708.html)).

Salinity(parts per liter) = (conductivity(milliSiemens/m) ^1.0878)*0.4665

To transmit data, we are using the Standard for a Smart Transducer Interface for Sensors and Actuator -LoRa Protocol (IEEE P1451.5 (https://standards.ieee.org/ieee/1451.5.5/10611/)) from the PUCKFish device to the base station on the boat. This standard allows for high accuracy and secure, easy use. Before the PUCKFish transmits data taken during a measurement period, it needs to store that data on-board until it is lifted out of the water. To store the data, we are using a SPI Flash SD Card breakout board, which adheres to SD card standards (SD Association (https://www.sdcard.org/developers/sd-standard-overview/)) and is compatible with standard SD card libraries for the microcontroller. For storage format, we are using JSON formatting and the existing associated libraries for the microcontroller.

The main computer on PUCKFish adheres to the Association Connecting Electronics Industries (IPC (https://www.ipc.org/ipc-standards)) standards along with the standards set by the PCB manufacturer, JLC, for both the design and manufacturing of the boards.

For charging the PUCKFish, we are using a Qi receiver and transmitter, which is the industry standard for inductive wireless charging. The receiver will be on the device itself, while the transmitter will be on the base station on the boat.

The mold for the epoxy enclosure has a drafting angle of 5 degrees to ensure easy removal of the silicone component. It is standard to use a drafting angle between 1 and 5 degrees.

# 6 Cost Breakdown

Currently, the biggest cost driver is the dissolved oxygen sensor. This cost is due to the sensitive nature of this device and the relatively niche market for it. Before going to market, we plan to find a correlation between the other data we collect and dissolved oxygen, as this discovery would drive down cost and complexity significantly. Unfortunately, dissolved oxygen is also one of the most crucial drivers of lobster habitation, and thus we cannot afford to scrap the dissolved oxygen sensor at this time.

Project Costs for Production of Beta Version (Next Unit after Prototype)
Item | Quantity | Description | Unit Cost | Extended Cost
Epoxy Resin and Hardener | 0.183 Gal | Two part epoxy mixture, of a 1.5 Gal kit | $172.78 | $21.08
3D Printed Skeleton | 1 | Skeleton mount for PCB, sensors, eyebolt mount | $10 | $10
Eyebolt | 1 | Eyebolt for tying to trap | $1.50 | $1.50
Aluminum Eyebolt Mount | 1 | Aluminum block for skeleton mount, drilled and threaded for eyebolt | $15 | $15
PCB | 1 | | $4.60 | $4.60
Dissolved O2 Sensor | 1 | | $152.99 | $152.99
Light Sensor | 1 | | $1.06 | $1.06
IMU | 1 | | $7.78 | $7.78
Salinity Sensor | 1 | | $0.90 | $0.90
Temperature and Pressure Sensor | 1 | | $30 | $30
Beta Version-Total Cost | | | | $244.91

# 7 Appendices

[Appendices include supplemental information for the User that would distract if included in the regular sections.

## 7.1 Appendix A – Team Information

Alex Necakov (CE 2022) - alexrn@bu.edu (203)-822-3119

Alex is an undergraduate pursuing a B.S. in computer engineering at Boston University. Although specializing in software engineering, Alex has gained experience in a breadth of ECE related fields including robotics and rocket electronics design. Working with embedded electronics has been his main focus in his undergraduate experience. Alex uses this experience with embedded electronics on the ECE side of PUCKFish.

Victoria Thomas (ME 2022) - vmthomas@bu.edu (508)-431-3947

Victoria is pursuing an undergraduate degree in mechanical engineering with an aerospace concentration from Easton, MA. Due to her significant hands-on manufacturing experience, Victoria applies manufacturing planning and processes to build PUCKFish. This semester she performed water testing on this device and helped to design and create the electronics bed. After graduation Victoria will be working in manufacturing at GE Aviation in Lynn, MA.

Ammar Hussain (EE 2022) - hussaina@bu.edu (617)-281-9858

Ammar is an undergraduate pursuing a B.S. in electrical engineering at Boston University from Brookline, MA. Ammar has experience with microelectronic circuits, and has an interest in sensor development. Additionally, he has long had a passion for marine biology and hopes to combine interest with his technical background to PUCKFish.

Will Aracri (ME 2022) - waracri@bu.edu (412)-952-8185

Will is an engineering student from Pittsburgh ,PA. He spent a year and a half in industry before returning to Boston to complete his degree. He specializes in testing and manufacturing procedures.

Peter Ha (ME 2022) - peterha@bu.edu 857-321-1112

Team 34 (PUCKFish) March 25, 2022

Team 34 (PUCKfish) March 25, 2022

User's Manual

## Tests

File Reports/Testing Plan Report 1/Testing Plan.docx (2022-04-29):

Required Materials

- PUCKfish prototype boards
- PUCKfish prototype housing
- Laptop
- Protractor
- Cables

Setup

- Connect prototype board to laptop wirelessly and confirm adequate battery charge on both devices
- Confirm the IMU responds to rotation and movement as expected
- Insert the prototype board into the prototype housing
- Wrap Teflon sealing tape on external threading CLOCKWISE several times, making it up and down the threading, before firmly tightening the cap

Testing Procedure

- Place prototype housing underwater
- Run code to collect data from the IMU
- Using a protractor, verify the prototype precisely reports the angle it is held at
- If the body of water has the capability of flow, measure the angle the prototype reaches with several flow rates

Measurable Criteria

- Prototype connects to laptop
- Prototype records and sends data outside of housing
- Prototype records and sends data inside of housing, but above water
- Prototype records and sends data inside of housing, underwater
- Prototype precisely reports angle
- Data is capable of building a model correlating angle to flow speed

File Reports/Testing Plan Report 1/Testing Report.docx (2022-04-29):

# Testing Plan Summary and Test 1.1 Results

## Team 34: PUCKFish

Team Lead 3: Will Aracri

Victoria Thomas, Alex Neckakov, Peter Ha, Ammar Hussain

# Contents

Title Page 1

Contents 2

Introduction 3

Testing Plan Overview 4

Test Overview 5

Test 1: Water-Proofing and Data Collection 5

Test 2.1: IMU Proof of Concept 5

Test 2.2: Sensor Array Test 6

Test 3.1: Port and Enclosure Testing 6

Test 3.2: Full Hardware Test 6

Test 4: Full PUCKFish Test 6

Test 1.0 7

Introduction and Overview 7

Summary of Procedure and Required Equipment 7

Results 9

Conclusion 10

# Testing Plan

# Introduction

PUCKFish is a device containing sensors (Temperature, Dissolved Oxygen, Salinity, Current Velocity, Depth, Ambient Light) to be mounted on top of Lobster traps in order to monitor the best possible locations to place traps for maximum catch yield. In order to function, the device must operate under water at depths of up to 1100 feet and then transmit data wirelessly to a base station upon retrieval.

In order to properly test PUCKFish to determine its effectiveness as well as aid in the design interaction process, the team considered the major challenges of the project and then broke them down into testable conditions. These attributes are as listed below.

Major Challenges and Required Testing Capabilities include:

1. Water-proofing: All Enclosures must be tested for water-proofing and then iterated upon to ensure the safety of electronic equipment
2. Sensor Arrays and Related Electronics: All Sensors must be tested with related electronic elements to ensure the required accuracy and precision metrics are achieved
3. Operations Proofing: The PUCKFish must be tested in order to ensure that operation of the device is not only possible, but also achieves a level of simplicity that is required of the customer
4. Novel Current-Velocity Sensing: The PUCKFish uses an IMU and the position of its buoyancy angle to determine current speeds and directions. Because this sensor is novel in design and application, it must be tested to prove that it operates within the proper accuracy and precision per the required metrics

By considering the major challenges above, a testing plan as well as a general technical development plan could be developed and executed.

# Testing Plan Overview

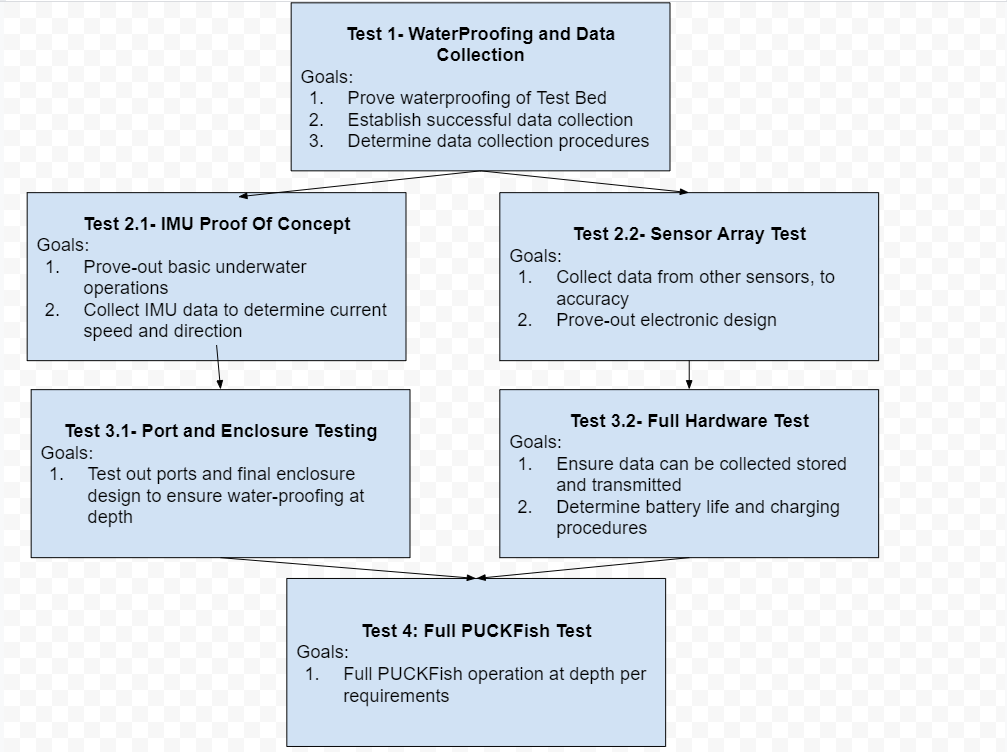
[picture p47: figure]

Figure 1: Testing Plan

The overall testing plan involves 6 separate tests with goals that build upon each other to achieve the end result of a final operational test with PUCKFish. Included in the testing plan were requirements for the team’s structure as to eliminate blockers and keep work progressing.

The plan involves an initial step proving how the team can come together to perform a successful test. It then moved into two parallel paths that developed the electronic systems and mechanical systems in tandem. By creating parallel paths, the team believes that PUCKFish can be developed in a shorter amount of time while continuously proving out technologies required for the next stage. These small proof of concepts allow for minimal risk in carrying out electronic tests in the water as to limit the possibilities of hardware damage or failures.

Additionally, the goals of each test will be refined as data is collected from tests earlier in the testing plan, allowing for more targeted objectives and quantifiable testing requirements.

Specific procedures for each test will be developed based upon knowledge gained from previous tests. This will allow more streamlined testing as well as refining the actual test environment to achieve the required metrics.

# Test Overview

Each test with their accompanying goals is outlined below. Where applicable, if a test requires data or knowledge from a test prior in the testing plan, a description is provided with how these requirements will be developed.

## Test 1: Water-Proofing and Data Collection

The major goals of Test 1 are as follows.

1. Prove waterproofing of Test Bed
  a. The test bed of the PUCKFish is a waterproof enclosure designed to test systems under-water without development time of producing a final enclosure design. This also shows the mechanical engineering part of the team how to design an enclosure to withstand low-depth submersion in water.
2. Establish successful data collection
  a. Establishing data collection is essential to determine how to transmit data to the base station. In addition, data collection remotely will be of use in later tests where depth is lower and adjustments to the testing environment can be made on the fly without removing the electronics and checking the hardware itself.
3. Determine Data Collection Procedures
  a. By determining data collection procedures, the team can share a common resource that does not require explanation or full team attendance to successfully run a test. This provides faster data collection and more refined technical developments in future tests.

## Test 2.1: IMU Proof of Concept

The major goals of Test 2.1 are as follows

1. Prove-Out basic underwater operations
  a. The IMU test bed will take place in a body of water with some current velocity and at a more significant water depth. This experience will allow the team to better understand how to operate and contend with running tests underwater which will be paramount for further development.
2. Collect IMU Data to determine current speed and direction
  a. After developing a model for how to produce an orientation from IMU data, the team can create models based upon flow around the PUCKFish to determine current speed and velocities. Proving these models work is paramount to the final success of PUCKFish.

## Test 2.2: Sensor Array Test

The major goals of test 2.2 are as follows

1. Collect data from other sensors to accuracy
  a. Collecting the data from the sensors, excluding the IMU, will allow the team to determine how to get data form the sensors and if the sensors achieve the necessary grades of precision and accuracy.
2. Prove-out electronic design
  a. In order to collect data from the sensors, there must be something to read and translate the data to be read. This hardware setup will allow the team to gain experience with building out the necessary electronic set up as well as proving out technology in design.

## Test 3.1: Port and Enclosure Testing

The major goals for test 3.1 are as follows

1. Test out ports and final enclosure design to ensure water-proofing at depth
  a. Using experience from tests 1.1 and 2.1, test 3.1 allows for the testing the enclosure at depth without electronics to determine waterproofing. In addition, somes sensors require exposure to the water surrounding the enclosure, to do this PUCKFish uses ports to the outside. It is important to determine that ports can do this successfully without letting water into the enclosure.

## Test 3.2: Full Hardware Test

The major goals for Test 3.2 are as follows

1. Ensure data can be collected stored and transmitted
  a. The final PUCKFish must be able to store and transmit full data sets. Prior tests do not require this capability, so it must be proved here.
2. Determine Battery Life and Charging procedures
  a. Prior tests do not require the battery life and charging to accomplish them. In order to prove the batteries capabilities, this will be proven here.

## Test 4: Full PUCKFish Test

The major goals for Test 4 are as follows

1. Full Operation at Depth
  a. This test is the final test for PUCKFish. It includes all of the prior test’s requirements and should reach full operation or the path to full operation.

After determining the testing plan and each test and their goals, the team was prepared to run Test 1: WaterProofing and Data Collection

# Test 1.0

# Introduction and Overview

The goals for this test are as follows:

1. Prove Waterproofing Test-Bed
2. Establish Successful Data Collection
3. Determine Data Collection Procedures

In order to accomplish the waterproofing of the test bed, the team decided to put paper towels inside the test enclosure and then submerge the enclosure in a bathtub for a period of time. The enclosure would be tested overnight and then reviewed to see if any of the paper towels within the enclosure is damp. Given no dampness, the team could move on to accomplish goal 2.

In order to accomplish successful data collection, the team got a micro controller and the IMU that will be used for Test 2.1. In addition, the team set up a radio that can be used to beam the information back to a computer while the microcontroller is inside the test enclosure. IMUs determine acceleration data, which then can be used to determine the orientation by modeling the location of the gravity vector. This information will serve as the data the team will try to successfully collect.

In order to establish successful data collection, the team started a google sheet to begin writing procedures that could be updated and also be used to record data in. After creating this sheet and having the general list of things to do, the team began to write the procedure for the IMU testing.

# Summary of Procedure and Required Equipment

The team submerged the enclosure overnight. After determining confidence in the water proofing of the enclosure, the following procedure was written on the data collection and procedure spreadsheet.

OP 1: SETUP
Op | Description
1.1 | Connect Prototype board to laptop
1.2 | Confirm Battery levels exceed 50 percent
1.3 | Install prototype board onto prototype chassis
1.4 | Begin collecting data by starting up the imu, Record the start time in the notes
1.5 | Wrap teflon tape on threading, clockwise
1.6 | Buyoff that housing is prepared for submerging, Check for potential leak areas
OP 2: TESTING PROCEDURE
OP | Descrition
2 | Submerge the Prototype in some volume of water so that it is totally submerged
2.1 | Begin running the code for IMU according to best practice
2.2 | Using a protractor, angle the housing parallel to gravity vector, Record start time and end time in notes
2.3 | Using a protractor, angle the housing 45 degrees against gravity vector, Record start time and end time in notes
2.4 | Using a protractor, angle the housing perpendicular to gravity vector, Record start time and end time in notes
2.5 | Remove the prototype from the volume of water
OP 3: BREAKDOWN PROCEDURE
OP | Description
3 | Dry off the outside of the prototype so that it is no longer wet
3.1 | Open the prototype housing
3.2 | Remove chassis from the housing
3.3 | Shutdown pcb per best practice
OP 4: DATA COLLECTION AND ANALYSIS
OP | DESCRIPTION
4 | export data to a text file
4.1 | Separate Data via the timestamps collected in ops 2.3-2.6
4.2 | Gather Averages of the data given in "TEST 1, DATA ANALYSIS" in this google sheet

Table 1: Procedure as Outlined

After the procedure had been written the test could be run. However, after realizing that water could not be procured in the Senior Design lab during the test, the team decided to omit the underwater active portion of this test. Instead, this portion was performed after the data collection with success. In addition, by reviewing the data, it was determined that only a couple sample seconds from the test would be required, not orientation, to determine the path forward

Listed below are the equipment requirements of the Test. This equipment was only listed for the active data collection portion of the lab as the other portions wrapped into the test were completed prior to the display in the senior design Lab.

REQUIRED MATERIALS
Item | Name | Quantity
1 | PUCKFish Prototype board V0.1 | 1
2 | PUCKFish Prototype Housing V0.1 | 1
3 | PUCKFish Prototype Chassis V0.1 | 1
4 | Laptop (any) | 1

Table 2: Materials List

# Results

During the test, the IMU and microcontroller were placed into the enclosure. While moving the IMU around inside of the enclosure, the IMU data was presented on the screen as serial output, showing a successful collection of data. The timestamps of the collection were recorded and the text file was saved locally to the computer and then transferred to the google sheet. Shown below is a table with the data

Time | Accel X | AccelX | Accel Y
86.71 | -0.32 | -9.39 | -9.39
90.74 | -0.42 | -9.5 | -9.5
92.75 | -0.35 | -9.46 | -9.46
94.76 | -0.21 | -9.5 | -9.5
96.78 | -0.87 | -8.99 | -8.99
98.79 | 9.94 | 0.32 | 0.32
100.8 | 9.58 | 0.58 | 0.58
102.82 | 9.54 | 0.74 | 0.74
104.83 | 9.46 | 0.68 | 0.68
106.85 | 9.39 | 1.17 | 1.17
108.86 | 9.32 | -2.01 | -2.01
110.87 | 9.68 | 0.42 | 0.42
112.89 | 9.42 | -0.02 | -0.02
114.9 | 9.39 | 0.5 | 0.5
116.91 | 9.24 | 0.34 | 0.34
118.93 | 9.91 | 0.86 | 0.86

Table 3: Test Results

## Conclusion

Through reviewing the acceleration data, the format and data collection methods were determined as a success. By testing the enclosure in the bathtub, the water proofing portion of the test was also successful.

From the results of this test, it was determined that the best path forward is to begin modeling the gravity vector as well as buoyancy characteristics to form the quantifiable requirements for Test 2.1. The IMU showed response to orientation being changed rapidly with high fidelity as shown by time stamps 86s to 96s. In addition, by keeping the enclosure still, the IMU showed good results providing a steady value within the required amount of precision between times 98s and 118s.

The team also adjusted how data is collected, by using methods to separate strings from numbers using google sheets as opposed to a separate script written in MATLAB. From the results of the test, one portion of the team will get to work developing the model for the IMU Current test and another portion of the team will begin working on the sensor array for Test 2.1.

The team has accomplished the goals of Test 1.1 and feel confident in proceeding to the tests outlined in the plan discussed.

Team 34: PUCKFish

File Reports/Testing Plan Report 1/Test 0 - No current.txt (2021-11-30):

Got: Packet #: 355.0
Seconds: 721.77     
Accel X: 9.60       
Accel Y: -0.39      
Accel Z: 1.12       
Orient X: 0.03      
Orient Y: 0.01      
Orient Z: 0.05      
RSSI: -98           
Got: Packet #: 356.0
Seconds: 723.79     
Accel X: 9.64       
Accel Y: 0.02       
Accel Z: 1.08       
Orient X: -0.01     
Orient Y: 0.01      
Orient Z: 0.06      
RSSI: -99           
Got: Packet #: 357.0
Seconds: 725.80     
Accel X: 9.61       
Accel Y: -0.33      
Accel Z: 1.17       
Orient X: 0.04      
Orient Y: 0.01      
Orient Z: -0.05     
RSSI: -100          
Got: Packet #: 358.0
Seconds: 727.82     
Accel X: 9.63       
Accel Y: -0.41      
Accel Z: 1.09       
Orient X: 0.10      
Orient Y: -0.00     
Orient Z: -0.06     
RSSI: -99           
Got: Packet #: 359.0
Seconds: 729.84     
Accel X: 9.66       
Accel Y: 0.06       
Accel Z: 1.13       
Orient X: 0.09      
Orient Y: -0.00     
Orient Z: -0.01     
RSSI: -101          
Got: Packet #: 360.0
Seconds: 731.85     
Accel X: 9.58       
Accel Y: -0.47      
Accel Z: 1.10       
Orient X: -0.11     
Orient Y: 0.01      
Orient Z: 0.02      
RSSI: -100          
Got: Packet #: 361.0
Seconds: 733.87     
Accel X: 9.59       
Accel Y: -0.21      
Accel Z: 1.10       
Orient X: 0.03      
Orient Y: 0.01      
Orient Z: 0.12      
RSSI: -101          
Got: Packet #: 362.0
Seconds: 735.88     
Accel X: 9.62       
Accel Y: -0.27      
Accel Z: 1.04       
Orient X: 0.04      
Orient Y: 0.01      
Orient Z: -0.04     
RSSI: -101          
Got: Packet #: 363.0
Seconds: 737.90     
Accel X: 9.61       
Accel Y: -0.16      
Accel Z: 1.12       
Orient X: 0.00      
Orient Y: 0.00      
Orient Z: 0.01      
RSSI: -101          
Got: Packet #: 364.0
Seconds: 739.91     
Accel X: 9.64       
Accel Y: -0.34      
Accel Z: 1.14       
Orient X: 0.00      
Orient Y: 0.02      
Orient Z: 0.00      
RSSI: -102          
Got: Packet #: 365.0
Seconds: 741.93     
Accel X: 9.65       
Accel Y: -0.43      
Accel Z: 1.01       
Orient X: 0.04      
Orient Y: -0.00     
Orient Z: 0.06      
RSSI: -100          
Got: Packet #: 366.0
Seconds: 743.94     
Accel X: 9.61       
Accel Y: -0.07      
Accel Z: 1.11       
Orient X: -0.07     
Orient Y: 0.01      
Orient Z: -0.00     
RSSI: -99           
Got: Packet #: 367.0
Seconds: 745.96     
Accel X: 9.60       
Accel Y: -0.53      
Accel Z: 1.18       
Orient X: 0.04      
Orient Y: 0.02      
Orient Z: -0.02     
RSSI: -97           
Got: Packet #: 368.0
Seconds: 747.97     
Accel X: 9.62       
Accel Y: -0.30      
Accel Z: 1.02       
Orient X: 0.07      
Orient Y: 0.01      
Orient Z: 0.02      
RSSI: -99           
Got: Packet #: 369.0
Seconds: 749.99     
Accel X: 9.65       
Accel Y: -0.24      
Accel Z: 1.11       
Orient X: -0.05     
Orient Y: 0.01      
Orient Z: -0.01     
RSSI: -98           
Got: Packet #: 370.0
Seconds: 752.01     
Accel X: 9.60       
Accel Y: -0.32      
Accel Z: 1.17       
Orient X: 0.06      
Orient Y: 0.01      
Orient Z: 0.02      
RSSI: -101          
Got: Packet #: 371.0
Seconds: 754.02     
Accel X: 9.64       
Accel Y: -0.33      
Accel Z: 1.06       
Orient X: -0.02     
Orient Y: 0.01      
Orient Z: 0.03      
RSSI: -99           
Got: Packet #: 372.0
Seconds: 756.04     
Accel X: 9.60       
Accel Y: -0.37      
Accel Z: 1.10       
Orient X: -0.04     
Orient Y: 0.01      
Orient Z: 0.05      
RSSI: -98

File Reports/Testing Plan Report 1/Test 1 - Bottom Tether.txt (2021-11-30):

Got: Packet #: 507.0
Seconds: 1028.13    
Accel X: 9.53       
Accel Y: 1.35       
Accel Z: 1.91       
Orient X: 1.71      
Orient Y: -0.25     
Orient Z: 0.29      
RSSI: -120          
Got: Packet #: 508.0
Seconds: 1030.14    
Accel X: 10.05      
Accel Y: 0.60       
Accel Z: 1.21       
Orient X: 0.40      
Orient Y: -0.36     
Orient Z: 0.81      
RSSI: -126          
Got: Packet #: 509.0
Seconds: 1032.16    
Accel X: 9.26       
Accel Y: 1.28       
Accel Z: 1.17       
Orient X: 1.83      
Orient Y: -0.18     
Orient Z: 1.25      
RSSI: -122          
Got: Packet #: 510.0
Seconds: 1034.17    
Accel X: 9.98       
Accel Y: 1.14       
Accel Z: 1.10       
Orient X: -0.13     
Orient Y: 0.25      
Orient Z: -0.09     
RSSI: -115          
Got: Packet #: 511.0
Seconds: 1036.19    
Accel X: 9.82       
Accel Y: 1.84       
Accel Z: 1.71       
Orient X: -0.05     
Orient Y: 0.40      
Orient Z: 0.63      
RSSI: -127          
Got: Packet #: 517.0
Seconds: 1048.28    
Accel X: 9.38       
Accel Y: 1.21       
Accel Z: 2.27       
Orient X: -0.04     
Orient Y: 0.03      
Orient Z: 0.15      
RSSI: -116          
Got: Packet #: 518.0
Seconds: 1050.30    
Accel X: 9.64       
Accel Y: 0.12       
Accel Z: 1.24       
Orient X: -1.21     
Orient Y: 0.08      
Orient Z: -0.33     
RSSI: -113          
Got: Packet #: 519.0
Seconds: 1052.31    
Accel X: 9.32       
Accel Y: 2.05       
Accel Z: 2.15       
Orient X: 1.52      
Orient Y: 0.14      
Orient Z: -0.47     
RSSI: -123          
Got: Packet #: 520.0
Seconds: 1054.33    
Accel X: 8.31       
Accel Y: 1.80       
Accel Z: 2.49       
Orient X: 3.72      
Orient Y: -0.03     
Orient Z: 0.42      
RSSI: -117          
Got: Packet #: 521.0
Seconds: 1056.34    
Accel X: 9.44       
Accel Y: 1.50       
Accel Z: 1.69       
Orient X: 2.01      
Orient Y: -0.12     
Orient Z: 0.74      
RSSI: -116          
Got: Packet #: 522.0
Seconds: 1058.36    
Accel X: 9.80       
Accel Y: 1.86       
Accel Z: 0.96       
Orient X: -1.24     
Orient Y: -0.20     
Orient Z: -0.71     
RSSI: -118          
Got: Packet #: 523.0
Seconds: 1060.38    
Accel X: 9.48       
Accel Y: 1.12       
Accel Z: 2.16       
Orient X: -0.34     
Orient Y: 0.03      
Orient Z: 0.17      
RSSI: -117          
Got: Packet #: 524.0
Seconds: 1062.39    
Accel X: 9.24       
Accel Y: 1.07       
Accel Z: 2.09       
Orient X: 2.93      
Orient Y: -0.13     
Orient Z: -0.09     
RSSI: -116          
Got: Packet #: 525.0
Seconds: 1064.41    
Accel X: 9.64       
Accel Y: 1.34       
Accel Z: 1.87       
Orient X: -2.28     
Orient Y: 0.01      
Orient Z: -0.16     
RSSI: -117          
Got: Packet #: 526.0
Seconds: 1066.42    
Accel X: 9.79       
Accel Y: 1.99       
Accel Z: 1.00       
Orient X: -1.60     
Orient Y: -0.09     
Orient Z: -0.24

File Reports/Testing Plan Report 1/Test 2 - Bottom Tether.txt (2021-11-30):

Got: Packet #: 748.00
Seconds: 1513.86
Accel X: 9.49
Accel Y: -0.94
Accel Z: 1.86
Orient X: 0.24
Orient Y: 0.02
Orient Z: -0.01
RSSI: -120
Got: Packet #: 749.00
Seconds: 1515.88
Accel X: 9.51
Accel Y: 0.95
Accel Z: 1.73
Orient X: -0.13
Orient Y: 0.03
Orient Z: -0.04
RSSI: -127
Got: Packet #: 750.00
Seconds: 1517.89
Accel X: 9.48
Accel Y: 0.10
Accel Z: 1.76
Orient X: 0.38
Orient Y: -0.02
Orient Z: -0.00
RSSI: -125
Got: Packet #: 751.00
Seconds: 1519.91
Accel X: 9.47
Accel Y: 0.86
Accel Z: 1.94
Orient X: -0.06
Orient Y: 0.01
Orient Z: 0.13
RSSI: -121
Got: Packet #: 754.00
Seconds: 1525.95
Accel X: 9.51
Accel Y: -0.13
Accel Z: 2.00
Orient X: 0.20
Orient Y: 0.01
Orient Z: -0.04
RSSI: -123
Got: Packet #: 757.00
Seconds: 1532.00
Accel X: 9.52
Accel Y: -0.32
Accel Z: 1.94
Orient X: 0.45
Orient Y: -0.05
Orient Z: 0.10
RSSI: -115
Got: Packet #: 758.00
Seconds: 1534.02
Accel X: 9.61
Accel Y: 0.28
Accel Z: 1.35
Orient X: -0.17
Orient Y: 0.00
Orient Z: -0.04
RSSI: -128
Got: Packet #: 760.00
Seconds: 1538.05
Accel X: 9.52
Accel Y: 1.18
Accel Z: 1.55
Orient X: 0.05
Orient Y: 0.01
Orient Z: -0.05
RSSI: -122
Got: Packet #: 761.00
Seconds: 1540.06
Accel X: 9.52
Accel Y: -0.13
Accel Z: 2.07
Orient X: -0.11
Orient Y: 0.01
Orient Z: 0.08
RSSI: -118
Got: Packet #: 762.00
Seconds: 1542.08
Accel X: 9.50
Accel Y: 0.57
Accel Z: 1.82
Orient X: 0.09
Orient Y: 0.01
Orient Z: 0.24
RSSI: -117
Got: Packet #: 763.00
Seconds: 1544.09
Accel X: 9.52
Accel Y: 0.98
Accel Z: 1.44
Orient X: -0.03
Orient Y: 0.02
Orient Z: -0.11
RSSI: -117
Got: Packet #: 764.00
Seconds: 1546.11
Accel X: 9.57
Accel Y: 1.47
Accel Z: 0.94
Orient X: 0.08
Orient Y: -0.02
Orient Z: -0.45
RSSI: -122
Got: Packet #: 765.00
Seconds: 1548.12
Accel X: 9.40
Accel Y: -0.27
Accel Z: 1.82
Orient X: 0.07
Orient Y: -0.03
Orient Z: -0.81
RSSI: -117
Got: Packet #: 766.00
Seconds: 1550.14
Accel X: 9.57
Accel Y: -0.17
Accel Z: 2.35
Orient X: 0.87
Orient Y: -0.01
Orient Z: 0.20
RSSI: -122
Got: Packet #: 767.00
Seconds: 1552.16
Accel X: 9.49
Accel Y: 0.46
Accel Z: 1.58
Orient X: 0.47
Orient Y: 0.07
Orient Z: 0.00
RSSI: -130
Got: Packet #: 768.00
Seconds: 1554.17
Accel X: 9.42
Accel Y: 1.56
Accel Z: 2.14
Orient X: -0.63
Orient Y: 0.14
Orient Z: -0.30
RSSI: -121
Got: Packet #: 769.00
Seconds: 1556.19
Accel X: 9.71
Accel Y: 0.62
Accel Z: 1.48
Orient X: 0.26
Orient Y: -0.28
Orient Z: 0.06
RSSI: -117
Got: Packet #: 771.00
Seconds: 1560.22
Accel X: 9.47
Accel Y: 0.29
Accel Z: 2.16
Orient X: 0.21
Orient Y: -0.04
Orient Z: -0.18
RSSI: -117
Got: Packet #: 772.00
Seconds: 1562.23
Accel X: 9.41
Accel Y: -0.50
Accel Z: 1.92
Orient X: 0.86
Orient Y: -0.04
Orient Z: 0.28
RSSI: -117
Got: Packet #: 773.00
Seconds: 1564.25
Accel X: 9.56
Accel Y: 0.11
Accel Z: 1.62
Orient X: -0.09
Orient Y: -0.00
Orient Z: -0.32
RSSI: -123
Got: Packet #: 774.00
Seconds: 1566.26
Accel X: 9.52
Accel Y: 0.73
Accel Z: 1.72
Orient X: -0.01
Orient Y: 0.00
Orient Z: 0.08
RSSI: -124
Got: Packet #: 775.00
Seconds: 1568.28
Accel X: 9.52
Accel Y: 0.28
Accel Z: 1.93
Orient X: -0.05
Orient Y: 0.01
Orient Z: 0.13
RSSI: -122
Got: Packet #: 776.00
Seconds: 1570.29
Accel X: 9.53
Accel Y: 1.16
Accel Z: 1.78
Orient X: 1.13
Orient Y: -0.10
Orient Z: 0.22
RSSI: -117
Got: Packet #: 778.00
Seconds: 1574.32
Accel X: 9.53
Accel Y: -0.36
Accel Z: 1.77
Orient X: 0.28
Orient Y: -0.02
Orient Z: 0.05
RSSI: -126
Got: Packet #: 779.00
Seconds: 1576.34
Accel X: 9.48
Accel Y: 0.60
Accel Z: 1.83
Orient X: 0.54
Orient Y: -0.01
Orient Z: 0.32
RSSI: -124
Got: Packet #: 780.00
Seconds: 1578.36
Accel X: 9.55
Accel Y: 0.81
Accel Z: 1.63
Orient X: -0.39
Orient Y: 0.05
Orient Z: -0.22
RSSI: -125
Got: Packet #: 781.00
Seconds: 1580.37
Accel X: 9.46
Accel Y: 0.59
Accel Z: 1.64
Orient X: 0.14
Orient Y: 0.02
Orient Z: -0.20
RSSI: -123
Got: Packet #: 782.00
Seconds: 1582.39
Accel X: 9.48
Accel Y: -0.91
Accel Z: 1.89
Orient X: -0.08
Orient Y: 0.00
Orient Z: 0.18
RSSI: -123
Got: Packet #: 783.00
Seconds: 1584.40
Accel X: 9.49
Accel Y: 0.24
Accel Z: 1.83
Orient X: 0.12
Orient Y: 0.01
Orient Z: 0.15
RSSI: -123
Got: Packet #: 784.00
Seconds: 1586.42
Accel X: 9.38
Accel Y: 1.32
Accel Z: 2.21
Orient X: -1.19
Orient Y: 0.12
Orient Z: -0.27
RSSI: -122
Got: Packet #: 785.00
Seconds: 1588.43
Accel X: 9.40
Accel Y: 0.35
Accel Z: 2.05
Orient X: 0.13
Orient Y: 0.02
Orient Z: -0.11
RSSI: -118
Got: Packet #: 786.00
Seconds: 1590.45
Accel X: 9.44
Accel Y: 1.05
Accel Z: 2.29
Orient X: 0.46
Orient Y: 0.07
Orient Z: 0.39
RSSI: -122
Got: Packet #: 787.00
Seconds: 1592.46
Accel X: 9.36
Accel Y: 1.00
Accel Z: 2.05
Orient X: 0.34
Orient Y: -0.09
Orient Z: 0.07
RSSI: -122
Got: Packet #: 788.00
Seconds: 1594.48
Accel X: 9.46
Accel Y: 0.75
Accel Z: 2.08
Orient X: -0.87
Orient Y: 0.07
Orient Z: 0.16
RSSI: -118
Got: Packet #: 789.00
Seconds: 1596.49
Accel X: 9.49
Accel Y: -0.32
Accel Z: 1.97
Orient X: 0.04
Orient Y: 0.00
Orient Z: -0.11
RSSI: -122
Got: Packet #: 791.00
Seconds: 1600.53
Accel X: 9.33
Accel Y: 1.12
Accel Z: 2.31
Orient X: -0.74
Orient Y: 0.03
Orient Z: -0.37
RSSI: -127
Got: Packet #: 0.00
Seconds: 6.28
Accel X: 9.30
Accel Y: 2.06
Accel Z: 1.67
Orient X: 0.06
Orient Y: 0.14
Orient Z: 0.12
RSSI: -60
Got: Packet #: 1.00
Seconds: 8.29
Accel X: 8.64
Accel Y: 2.01
Accel Z: 3.88
Orient X: -0.11
Orient Y: -0.17
Orient Z: 0.58
RSSI: -58
Got: Packet #: 2.00
Seconds: 10.31
Accel X: 7.81
Accel Y: -5.11
Accel Z: 1.62
Orient X: 0.08
Orient Y: -0.10
Orient Z: -0.02
RSSI: -65
Got: Packet #: 3.00
Seconds: 12.32
Accel X: 10.31
Accel Y: 7.27
Accel Z: -0.52
Orient X: 0.07
Orient Y: -0.58

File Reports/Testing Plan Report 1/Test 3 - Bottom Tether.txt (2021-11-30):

Got: Packet #: 643.00
Seconds: 1302.23
Accel X: 9.54
Accel Y: -0.80
Accel Z: 1.53
Orient X: -0.16
Orient Y: 0.01
Orient Z: -0.01
RSSI: -130
Got: Packet #: 644.00
Seconds: 1304.25
Accel X: 9.63
Accel Y: 0.20
Accel Z: 1.21
Orient X: -0.21
Orient Y: 0.08
Orient Z: -0.05
RSSI: -123
Got: Packet #: 645.00
Seconds: 1306.27
Accel X: 9.42
Accel Y: 2.55
Accel Z: 1.11
Orient X: 0.60
Orient Y: -0.01
Orient Z: -0.29
RSSI: -122
Got: Packet #: 646.00
Seconds: 1308.28
Accel X: 9.43
Accel Y: 1.25
Accel Z: 1.50
Orient X: 1.69
Orient Y: -0.13
Orient Z: -0.19
RSSI: -115
Got: Packet #: 647.00
Seconds: 1310.30
Accel X: 9.51
Accel Y: -0.46
Accel Z: 2.14
Orient X: 0.12
Orient Y: -0.03
Orient Z: 0.08
RSSI: -113
Got: Packet #: 648.00
Seconds: 1312.31
Accel X: 9.50
Accel Y: 0.48
Accel Z: 1.63
Orient X: -0.08
Orient Y: 0.03
Orient Z: 0.00
RSSI: -113
Got: Packet #: 649.00
Seconds: 1314.33
Accel X: 9.54
Accel Y: 1.08
Accel Z: 1.45
Orient X: -0.28
Orient Y: 0.03
Orient Z: -0.30
RSSI: -111
Got: Packet #: 650.00
Seconds: 1316.34
Accel X: 9.52
Accel Y: -0.45
Accel Z: 1.77
Orient X: 0.22
Orient Y: 0.00
Orient Z: -0.09
RSSI: -112
Got: Packet #: 651.00
Seconds: 1318.36
Accel X: 9.43
Accel Y: 0.56
Accel Z: 1.95
Orient X: 0.11
Orient Y: 0.06
Orient Z: 0.17
RSSI: -112
Got: Packet #: 652.00
Seconds: 1320.37
Accel X: 9.04
Accel Y: 2.97
Accel Z: 1.67
Orient X: 1.00
Orient Y: 0.03
Orient Z: 0.28
RSSI: -116
Got: Packet #: 653.00
Seconds: 1322.39
Accel X: 9.52
Accel Y: 1.84
Accel Z: 1.62
Orient X: -0.76
Orient Y: 0.05
Orient Z: -0.41
RSSI: -115
Got: Packet #: 654.00
Seconds: 1324.41
Accel X: 9.37
Accel Y: 0.56
Accel Z: 1.85
Orient X: 0.77
Orient Y: -0.15
Orient Z: -0.12
RSSI: -121
Got: Packet #: 655.00
Seconds: 1326.42
Accel X: 9.40
Accel Y: 1.36
Accel Z: 1.80
Orient X: 0.13
Orient Y: -0.00
Orient Z: -0.06
RSSI: -115
Got: Packet #: 656.00
Seconds: 1328.44
Accel X: 9.41
Accel Y: 1.31
Accel Z: 1.95
Orient X: -0.13
Orient Y: 0.03
Orient Z: -0.13
RSSI: -119
Got: Packet #: 657.00
Seconds: 1330.45
Accel X: 9.42
Accel Y: 0.72
Accel Z: 1.96
Orient X: -0.30
Orient Y: 0.03
Orient Z: -0.08
RSSI: -115
Got: Packet #: 658.00
Seconds: 1332.47
Accel X: 9.31
Accel Y: 1.06
Accel Z: 1.57
Orient X: -0.61
Orient Y: 0.09
Orient Z: -0.22
RSSI: -114
Got: Packet #: 660.00
Seconds: 1336.50
Accel X: 9.51
Accel Y: 2.00
Accel Z: 1.47
Orient X: -1.02
Orient Y: -0.08
Orient Z: -0.19
RSSI: -126
Got: Packet #: 661.00
Seconds: 1338.51
Accel X: 9.09
Accel Y: -0.27
Accel Z: 2.35
Orient X: 0.83
Orient Y: -0.19
Orient Z: 0.14
RSSI: -121
Got: Packet #: 662.00
Seconds: 1340.53
Accel X: 6.62
Accel Y: 0.09
Accel Z: 1.36
Orient X: -0.38
Orient Y: 0.48
Orient Z: 0.29
RSSI: -113
Got: Packet #: 663.00
Seconds: 1342.55
Accel X: 9.52
Accel Y: 2.60
Accel Z: 1.45
Orient X: 0.55
Orient Y: 0.12
Orient Z: -0.06
RSSI: -120
Got: Packet #: 664.00
Seconds: 1344.56
Accel X: 9.48
Accel Y: 0.19
Accel Z: 2.14
Orient X: 0.05
Orient Y: -0.06
Orient Z: 0.04
RSSI: -107
Got: Packet #: 665.00
Seconds: 1346.57
Accel X: 9.41
Accel Y: 1.16
Accel Z: 1.83
Orient X: 0.13
Orient Y: -0.02
Orient Z: 0.11
RSSI: -108
Got: Packet #: 666.00
Seconds: 1348.59
Accel X: 9.23
Accel Y: 1.90
Accel Z: 2.47
Orient X: 0.54
Orient Y: 0.07
Orient Z: -0.64
RSSI: -117
Got: Packet #: 667.00
Seconds: 1350.61
Accel X: 9.45
Accel Y: -0.30
Accel Z: 1.48
Orient X: -0.52
Orient Y: -0.09
Orient Z: 0.51
RSSI: -111
Got: Packet #: 668.00
Seconds: 1352.62
Accel X: 9.49
Accel Y: 0.01
Accel Z: 1.87
Orient X: -0.85
Orient Y: 0.05
Orient Z: -0.06
RSSI: -109

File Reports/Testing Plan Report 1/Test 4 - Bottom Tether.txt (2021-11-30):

Got: Packet #: 189.00      
Seconds: 387.20            
Accel X: 9.62              
Accel Y: 1.47              
Accel Z: -0.99             
Orient X: 1.73             
Orient Y: -0.37            
Orient Z: -0.18            
RSSI: -118                 
Got: Packet #: 190.00      
Seconds: 389.22            
Accel X: 8.97              
Accel Y: -0.12             
Accel Z: -4.51             
Orient X: 3.61             
Orient Y: -0.26            
Orient Z: 0.10             
RSSI: -124                 
Got: Packet #: 192.00      
Seconds: 393.25            
Accel X: 9.25              
Accel Y: 1.12              
Accel Z: -3.23             
Orient X: 0.07             
Orient Y: -0.03            
Orient Z: -0.64            
RSSI: -117                 
Got: Packet #: 195.00      
Seconds: 399.30            
Accel X: 8.76              
Accel Y: 0.29              
Accel Z: -3.66             
Orient X: -1.60            
Orient Y: -0.02            
Orient Z: 0.95             
RSSI: -118                 
Got: Packet #: 196.00      
Seconds: 401.31            
Accel X: 9.35              
Accel Y: 0.71              
Accel Z: -2.34             
Orient X: -0.81            
Orient Y: 0.23             
Orient Z: -0.03            
RSSI: -118                 
Got: Packet #: 197.00      
Seconds: 403.33            
Accel X: 8.99              
Accel Y: -0.57             
Accel Z: -3.35             
Orient X: -0.67            
Orient Y: 0.07             
Orient Z: -0.39            
RSSI: -124                 
Got: Packet #: 198.00      
Seconds: 405.34            
Accel X: 9.08              
Accel Y: -0.62             
Accel Z: -3.00             
Orient X: 0.32             
Orient Y: -0.22            
Orient Z: 0.47             
RSSI: -119                 
Got: Packet #: 200.00      
Seconds: 409.38            
Accel X: 9.26              
Accel Y: 1.37              
Accel Z: -2.51             
Orient X: -0.46            
Orient Y: 0.25             
Orient Z: -0.09            
RSSI: -116

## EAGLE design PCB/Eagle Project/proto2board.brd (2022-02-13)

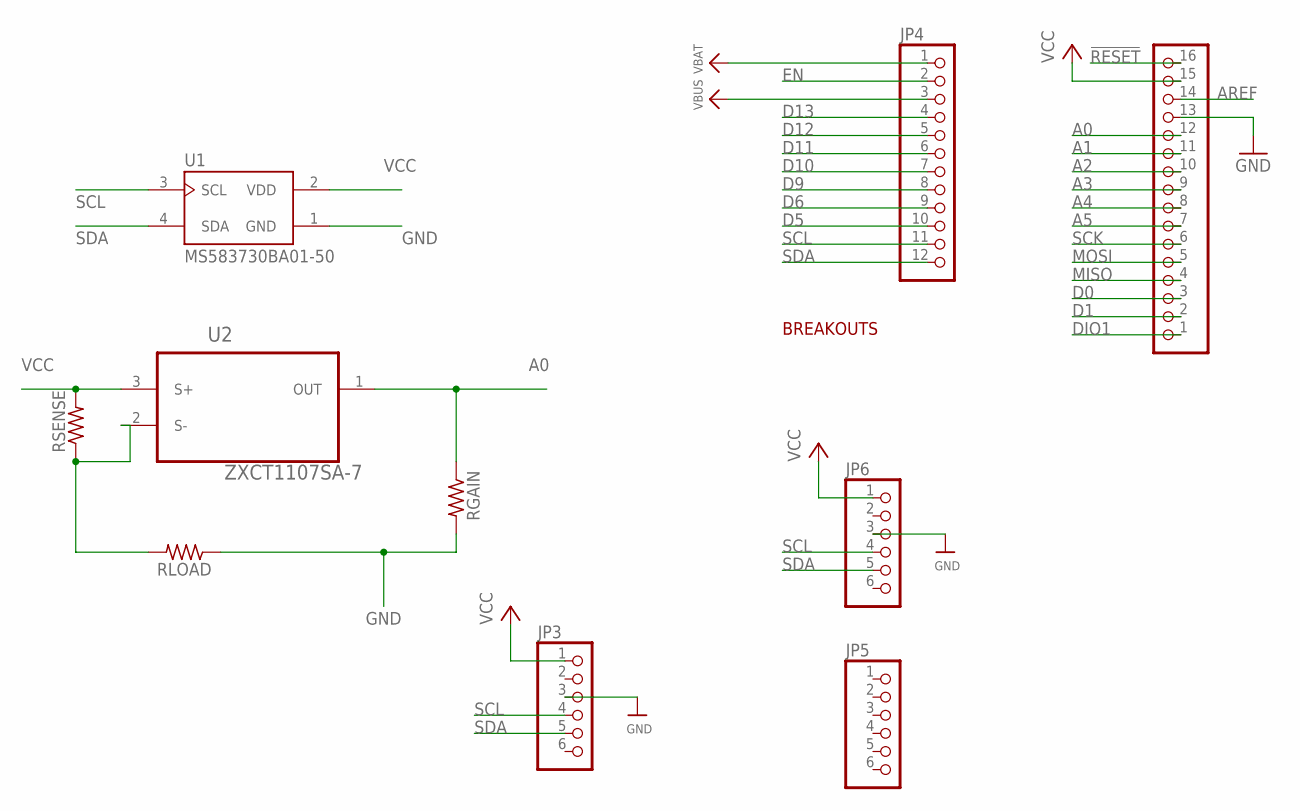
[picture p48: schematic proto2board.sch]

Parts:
JP2: HEADER-1X16ROUND; 1X16_ROUND
JP3, JP6: HEADER-1X670MIL; 1X06_ROUND_70
JP4: HEADER-1X12; 1X12_ROUND
JP5: HEADER-1X6ROUND; 1X06_ROUND
RGAIN: R-US_0204/7; 0204/7
RLOAD: R-US_0204/7; 0204/7
RSENSE: R-US_0204/7; 0204/7
U1: MS583730BA01-50; TE_MS583730BA01-50
U2: ZXCT1107SA-7; SOT91P240X110-3N

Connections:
!RESET: JP2.16
A0: JP2.12, RGAIN.1, U2.1 (OUT)
A1: JP2.11
A2: JP2.10
A3: JP2.9
A4: JP2.8
A5: JP2.7
AREF: JP2.14
D0: JP2.3
D1: JP2.2
D5: JP4.10
D6: JP4.9
D9: JP4.8
D10: JP4.7
D11: JP4.6
D12: JP4.5
D13: JP4.4
DIO1: JP2.1
EN: JP4.2
GND: JP2.13, JP3.3, JP6.3, RGAIN.2, RLOAD.1, U1.1 (GND)
MISO: JP2.4
MOSI: JP2.5
unnamed: RLOAD.2, RSENSE.1, U2.2 (S-)
SCK: JP2.6
SCL: JP3.4, JP4.11, JP6.4, U1.3 (SCL)
SDA: JP3.5, JP4.12, JP6.5, U1.4 (SDA)
VBAT: JP4.1
VBUS: JP4.3
VCC: JP2.15, JP3.1, JP6.1, RSENSE.2, U1.2 (VDD), U2.3 (S+)

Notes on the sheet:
BREAKOUTS

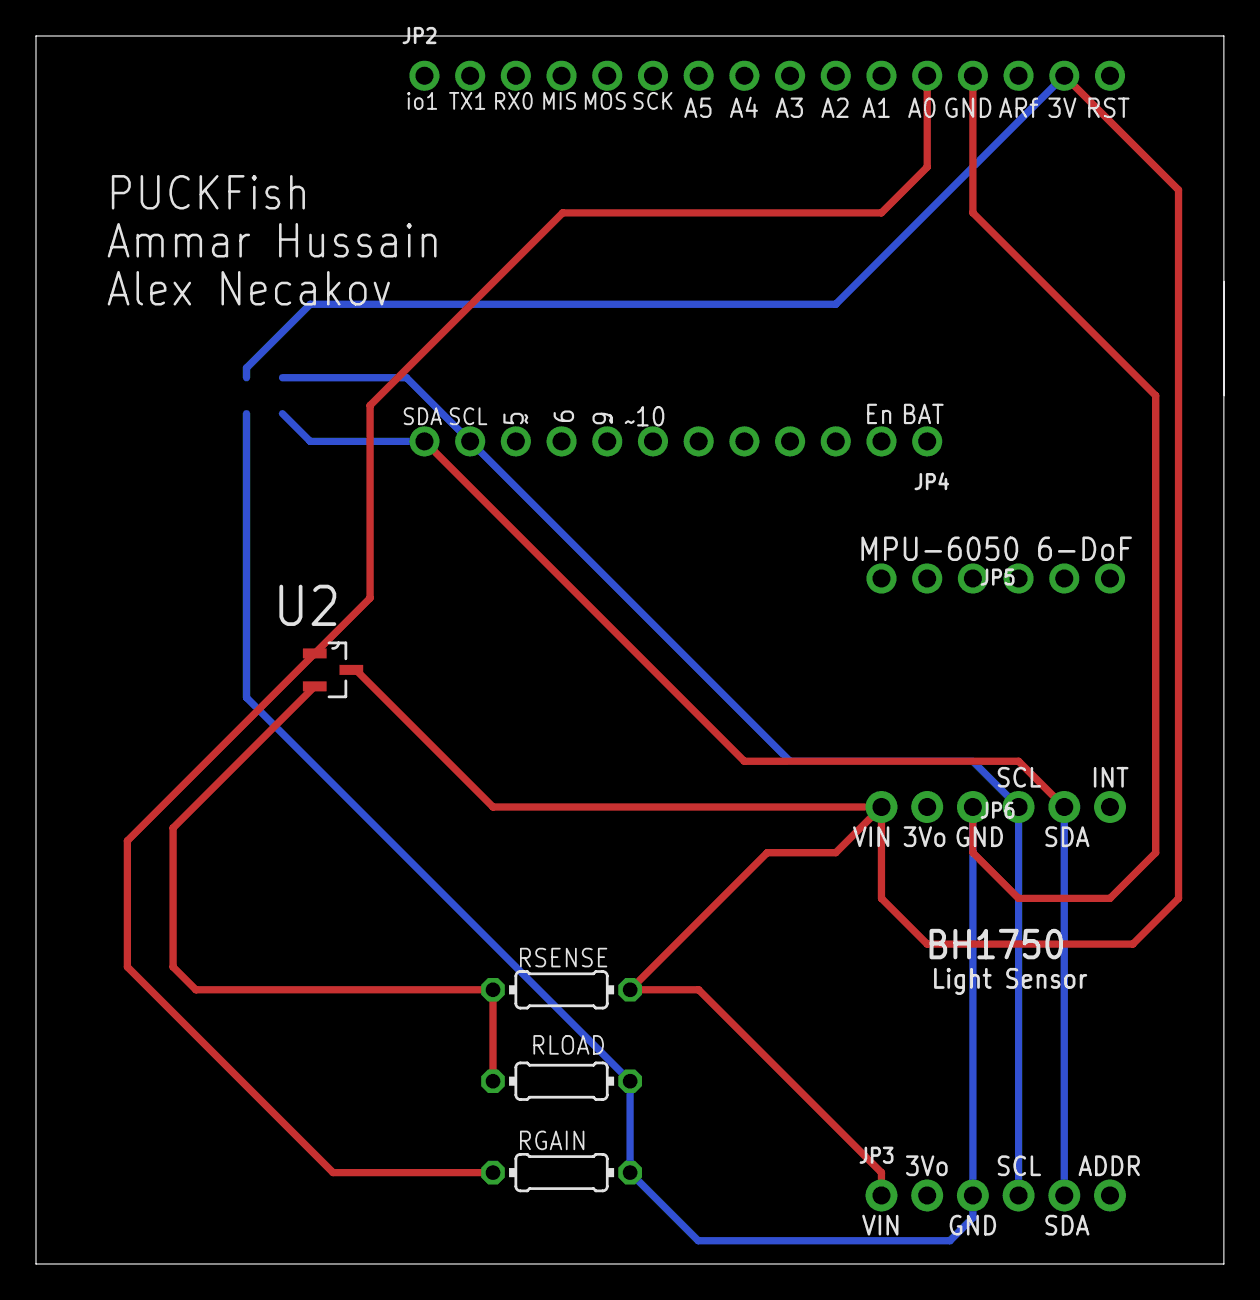
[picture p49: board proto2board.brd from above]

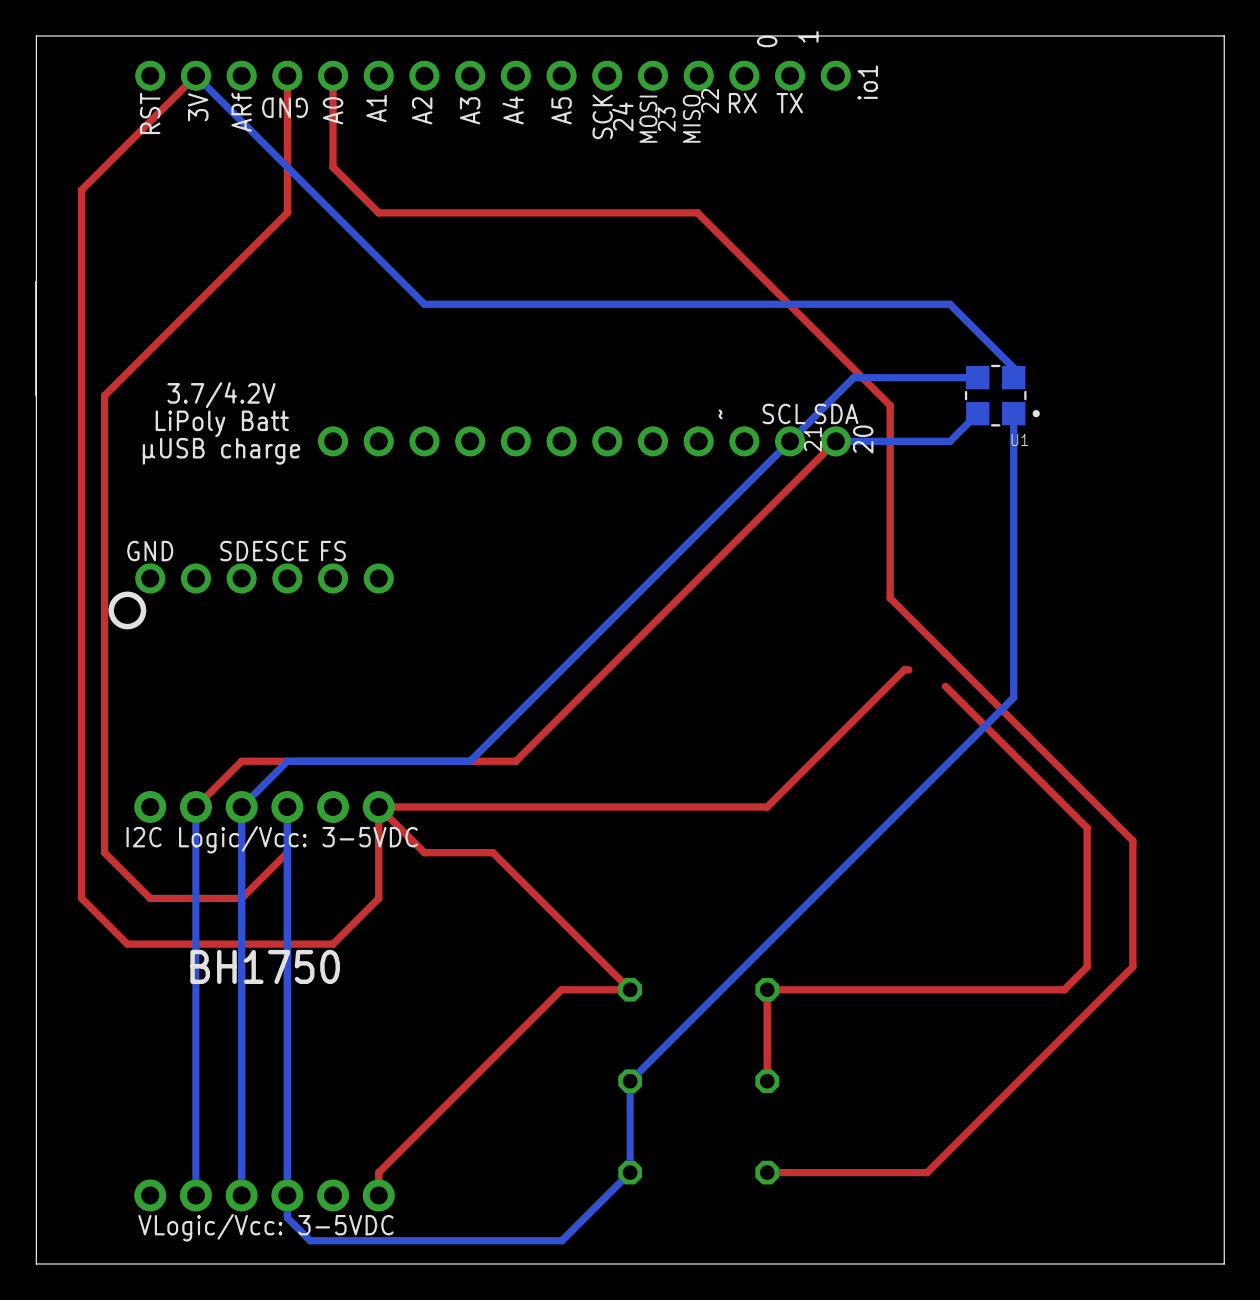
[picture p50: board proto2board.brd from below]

Board: 2 copper layers, 66.0 x 68.2 mm, 11 parts (2 on the bottom side), 6 nets.

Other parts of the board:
U$6: PCBFEAT-REV-040

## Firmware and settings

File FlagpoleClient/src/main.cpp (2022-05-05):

// PUCKFish Client Code
// Alex Necakov 2022

#include <Arduino.h>
#include <ArduinoJson.h>
#include <Wire.h>
#include <SPI.h>
#include <SD.h>
#include <Adafruit_Sensor.h>
#include <RH_RF95.h>
#include <Adafruit_MPU6050.h>
#include <BH1750.h>
#include <zxct.h>
#include <do_grav.h>
#include <MS5837.h>

// State Defines
#define STATE_SURFACE 0
#define STATE_SUBMERGE 1

// Pin Defines
#define RF95_INT 3
#define RF95_RST 4
#define RF95_CS 8
#define SD_CS 10

#define ZXCT1107_PIN A0
#define GRAVITYDO_PIN A1
#define VBAT_PIN A7

// Value Defines
#define MILLIS_HR 3600000
#define MILLIS_MIN 60000
#define MILLIS_30_SEC 30000
#define MILLIS_10_SEC 10000
#define MILLIS_SEC 1000
#define POLLING_FREQ MILLIS_10_SEC

#define ARDUINOJSON_USE_DOUBLE 0
#define ARDUINOJSON_USE_LONG_LONG 0

#define RF95_FREQ 915.0
#define MS5_I2C_ADDRESS 0x76
#define BH1750_I2C_ADDRESS 0x23
#define BH1750_MODE ONE_TIME_HIGH_RES_MODE

#define SEA_LEVEL_MBAR 1013.25

uint8_t state;
unsigned long lastMeasure;

RH_RF95 rf95(RF95_CS, RF95_INT);
Adafruit_MPU6050 mpu6050;
BH1750 bh1750(BH1750_I2C_ADDRESS);
ZXCT1107 zxct1107 = ZXCT1107(ZXCT1107_PIN);
Gravity_DO gravitydo = Gravity_DO(GRAVITYDO_PIN);
MS5837 ms5;

//mpu6050 accel/gyro/temp sensor code
void mpu6050Init()
{
    Serial.println("MPU6050\tInitializing");
    while (!mpu6050.begin())
        Serial.println("MPU6050\tInit failed");
    Serial.println("MPU6050\tInit success");
}

//bh1750 light sensor code
void bh1750Init()
{
    Serial.println("BH1750\tInitializing");
    while (!bh1750.begin(BH1750::BH1750_MODE))
        Serial.println("BH1750\tInit failed");
    Serial.println("BH1750\tInit success");
    bh1750.configure(BH1750::ONE_TIME_HIGH_RES_MODE);
}

float bh1750Loop()
{
    float lux = bh1750.readLightLevel();

    bh1750.configure(BH1750::ONE_TIME_HIGH_RES_MODE);

    return lux;
}

//zxct1107 salinity sensor code
void zxct1107Init()
{
    Serial.println("ZXCT1107\tInitializing");
    while (!zxct1107.begin())
        Serial.println("ZXCT1107\tInit failed");
    Serial.println("ZXCT1107\tInit success");
}

float zxct1107Loop()
{
    float salinity = zxct1107.read_salinity();

    return salinity;
}

//gravity dissolved oxygen sensor code
void gravitydoInit()
{
    Serial.println("GRAVITYDO\tInitializing");
    while (!gravitydo.begin())
        Serial.println("GRAVITYDO\tInit failed");
    Serial.println("GRAVITYDO\tInit success");

    Serial.print("GRAVITYDO\tFull saturation voltage calibrated to: ");
    Serial.print(gravitydo.cal());
    Serial.println("");
}

float gravitydoLoop()
{
    float dissolvedOxygen = gravitydo.read_do_percentage();
    return dissolvedOxygen;
}

//pressure sensor code
void ms5Init()
{
    Serial.println("MS5\tInitializing");
    while (!ms5.begin())
        Serial.println("MS5\tInit failed");

    ms5.setModel(MS5837::MS5837_30BA);

    ms5.setFluidDensity(1029); // kg/m^3 (freshwater, 1029 for seawater)

    Serial.println("MS5\tInit success");
}

float ms5Loop()
{
    ms5.read();
    float depth = ms5.depth();

    return depth;
}

//rfm95 radio code
void rf95Init()
{
    digitalWrite(SD_CS, HIGH);
    Serial.println("RF95\tInitializing");
    while (!rf95.init())
        Serial.println("RF95\tInit failed");
    Serial.println("RF95\tInit success");

    // Defaults after init are 434.0MHz, 13dBm, Bw = 125 kHz, Cr = 4/5, Sf = 128chips/symbol, CRC on
    while (!rf95.setFrequency(RF95_FREQ))
        Serial.println("RF95\tSet frequency failed");
    Serial.print("RF95\tSet frequency to: ");
    Serial.println(RF95_FREQ);

    rf95.setTxPower(23, false);
}

void rf95Loop()
{
    File root = SD.open("/");
    root.rewindDirectory();

    //loop through files
    while (true)
    {
        File dataStorage = root.openNextFile();
        if (!dataStorage)
        {
            // no more files
            //Serial.println("**nomorefiles**");
            break;
        }

        //Serial.print(dataStorage.name());
        //Serial.println("");

        StaticJsonDocument<251> doc;
        deserializeJson(doc, dataStorage);

        // serializeJson(doc, Serial);
        uint8_t output[RH_RF95_MAX_MESSAGE_LEN];
        serializeJson(doc, output);
        // Serial.print(output);
        // Serial.println("");
        dataStorage.close();

        digitalWrite(SD_CS, HIGH);

        if (rf95.send(output, sizeof(output)))
        {
            rf95.waitPacketSent();
            Serial.print("Sent ");
            Serial.print(sizeof(output));
            Serial.println(" bytes");
        }
        else
        {
            // Serial.println("RF95\tTransmission Failed!");
        }
    }
    rf95.sleep();
    root.close();
}

// sd card code
void sdInit()
{
    digitalWrite(RF95_CS, HIGH);
    Serial.println("SD\tInitializing");
    while (!SD.begin(SD_CS))
        Serial.println("SD\tInitialization failed!");
    Serial.println("SD\tInitialization success");

    Serial.println("SD\tClearing storage");
    File root = SD.open("/");
    root.rewindDirectory();

    //loop through files to delete
    while (true)
    {
        File dataStorage = root.openNextFile();
        if (!dataStorage)
        {
            // no more files
            //Serial.println("**nomorefiles**");
            break;
        }

        SD.remove(dataStorage.name());
        dataStorage.close();
    }
    root.close();
    //Serial.println("SD\tStorage cleared");
}

void setup()
{
    Serial.begin(9600);
    Serial.println("Initializing");
    Wire.begin();
    SPI.begin();
    pinMode(SD_CS, OUTPUT);
    pinMode(RF95_CS, OUTPUT);
    delay(5000);

    rf95Init();
    mpu6050Init();
    ms5Init();
    bh1750Init();
    zxct1107Init();
    gravitydoInit();
    sdInit();
    Serial.println("Initialization Complete");
    lastMeasure = millis();
}

void loop()
{
    // //need to poll pressure for state 
    // //Serial.println("Reading begin");
    // ms5.read();
    // //Serial.println("Reading end");
    // float pressure = ms5.pressure();
    // //Serial.print(pressure);
    // //Serial.println("");
    // if (pressure <= SEA_LEVEL_MBAR * 1.01)
    // {
    //     state = STATE_SURFACE;
    // }
    // else if (pressure > SEA_LEVEL_MBAR * 1.01)
    // {
    //     // disable radio
    //     digitalWrite(RF95_CS, HIGH);
    //     state = STATE_SUBMERGE;
    // }

    state = STATE_SUBMERGE;
    //Serial.print(state);
    //Serial.println("");

    switch (state)
    {
    case STATE_SURFACE: //when surfaced transmit every 10 seconds
        rf95Loop();
        delay(MILLIS_10_SEC);
        break;
    case STATE_SUBMERGE:
        //poll oncer per hour while submerged
        if (millis() >= lastMeasure + POLLING_FREQ)
        {
            StaticJsonDocument<251> packet;
            lastMeasure = millis();

            packet["#"] = lastMeasure;
            sensors_event_t aEvent, gEvent, tEvent;
            mpu6050.getEvent(&aEvent, &gEvent, &tEvent);
            packet["a"][0] = aEvent.acceleration.x;
            packet["a"][1] = aEvent.acceleration.y;
            packet["a"][2] = aEvent.acceleration.z;
            packet["o"][0] = gEvent.orientation.x;
            packet["o"][1] = gEvent.orientation.y;
            packet["o"][2] = gEvent.orientation.z;
            packet["t"] = tEvent.temperature;
            packet["l"] = bh1750Loop();
            packet["s"] = zxct1107Loop();
            packet["d"] = gravitydoLoop();
            packet["p"] = ms5Loop();
            //serializeJsonPretty(packet, Serial);

            //write to sd
            String fileName = String(lastMeasure) + ".txt";
            char fileNameBuf[fileName.length()];
            fileName.toCharArray(fileNameBuf, fileName.length());
            File dataStorage = SD.open(fileNameBuf, FILE_WRITE);
            serializeJson(packet, dataStorage);
            dataStorage.close();

            rf95Loop();
        }
        delay(MILLIS_10_SEC);
        break;
    default:
        rf95Loop();
        delay(MILLIS_10_SEC);
        break;
    }
}

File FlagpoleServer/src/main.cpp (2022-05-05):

// PUCKFish Base Station Code
// Alex Necakov 2022

#include <Arduino.h>
#include <ArduinoJson.h>
#include <SPI.h>
#include <Wire.h>
#include <RH_RF95.h>

// Pin Defines
#define RF95_CS 8
#define RF95_RST 4
#define RF95_INT 3

// Value Defines
#define RF95_FREQ 915.0

RH_RF95 rf95(RF95_CS, RF95_INT);

int rf95Init()
{
    // Serial.println("RF95\tInitializing");
    while (!rf95.init())
        Serial.println("RF95\tInit failed");
    // Serial.println("RF95\tInit success");

    // Defaults after init are 434.0MHz, 13dBm, Bw = 125 kHz, Cr = 4/5, Sf = 128chips/symbol, CRC on
    while (!rf95.setFrequency(RF95_FREQ))
        Serial.println("RF95\tSet frequency failed");
    // Serial.print("RF95\tSet frequency to: ");
    // Serial.println(RF95_FREQ);

    return 0;
}

void rf95Loop()
{
    if (rf95.available())
    {
        // Serial.println("RF95\tAvailable");
        // Should be a message for us now
        uint8_t buf[RH_RF95_MAX_MESSAGE_LEN];
        uint8_t len = sizeof(buf);

        if (rf95.recv(buf, &len))
        {
            StaticJsonDocument<251> packet;
            // Serial.println("RF95\tReceive success");
            deserializeJson(packet, buf);
            serializeJson(packet, Serial);
            Serial.println("");
        }
        else
        {
            // Serial.println("RF95\tReceive failed");
        }
    }
}

void setup()
{
    Serial.begin(9600);
    delay(5000);
    Serial.println("");
    rf95Init();
}

void loop()
{
    rf95Loop();
}

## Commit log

2021-10-04 Will's Commit
    Introducing a folder for my notes as well as our competitive analysis
    [compAnalysisWorkbook.xlsx]
2021-10-04 Switched this file over to plaintext
2021-10-22 Making PlatformIO project for Flagpole IMU test
2021-10-26 drivers for testbed IMU
2021-11-07 client imu driver working
2021-11-16 battery life monitor
2022-01-23 CAD of Skeleton
    This is the CAD of the skeleton that will be 3D printed and will fit into the epoxied sphere.
    [Skeleton_1.SLDPRT]
2022-01-23 Add files via upload
    Eagle PCB design files for each component
    [Adafruit BH1750.brd, Adafruit BH1750.sch, Adafruit Feather M0 RFMxx.brd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]
2022-01-24 Added all parts to new Eagle Project/created DBLs for Adafruit stuff
    [proto2board.brd, proto2board.sch]
2022-01-24 Schematic done except salinity sensor
    [proto2board.brd, proto2board.sch]
2022-01-24 Reduced board size
    [proto2board.brd]
2022-01-25 Salinity incorporated into sch better now
    Resistors added, needs proofreading
    [proto2board.brd, proto2board.sch]
2022-01-25 Updates to the Skeleton Design
    [Skeleton_1.SLDPRT, Skeleton_2.SLDPRT, Skeleton_3.SLDPRT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]
2022-01-25 Skeleton Updates
    [Skeleton_4.SLDPRT]
2022-01-25 Mold CAD first draft
    [mold_master.SLDPRT]
2022-01-25 cleaned up model
    [mold_master.SLDPRT]
2022-01-25 lil baby mold
    [mold_master.SLDPRT]
2022-01-27 Add files via upload
    Preliminary layout
    [proto2board_lay.brd]
2022-01-28 Skeleton Update
    [Skeleton_6.SLDPRT, Skeleton_7.SLDPRT]
2022-01-28 updated assembly, mold to skeleton 7
    [mold assembly.SLDASM, mold_master.SLDPRT]
2022-01-31 Final Skeleton Update
    [Skeleton_8.SLDPRT]
2022-02-01 Skeleton 8 with small details
    [Skeleton_8.SLDPRT]
2022-02-03 added versions for printing
    [mold assembly.SLDASM, mold_downer.SLDPRT, mold_downer.STL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]
2022-02-07 mpu and bh sensors from example code
2022-02-08 Fixed DRC errors
    [proto2board_lay.brd]
2022-02-10 Fixed angles
    [proto2board_lay.brd]
2022-02-10 Latest updates
    [proto2board_lay.brd]
2022-02-13 PCB Layout editing
    Vialess layout, exported in the zip file and being sent to JLC now
    [proto2board.brd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]
2022-02-27 uploaded stls
    [metamold_downer.STL, metamold_upper.STL]
2022-02-27 Redoing client code for prototype 2
2022-02-28 prototype salinity sensor driver
2022-02-28 zxct prototype put into main
2022-02-28 json formatting prototype code
2022-03-01 Change in Skeleton8
    Change in skeleton 8 design
    [Skeleton_8.STL]
2022-03-01 very bad changeset for prototype 2 working demo
2022-03-15 Finalized cad(?)
    [Skeleton_8.SLDPRT, final assembly.SLDASM, metamold_downer.SLDPRT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]
2022-03-22 ms5 driver initial commit
2022-03-22 pressure sensor i2c driver
2022-03-22 pressure code in main
2022-03-24 compiles now. zxct driver needs to be totally rewritten
2022-03-25 ms5 reset not working
    [main.cpp]
2022-03-25 ms5 not showing up in i2c scanner.... that is bad
2022-03-25 ms5 driver fixed
2022-03-25 talking to all sensors. sd not working
    [main.cpp]
2022-03-25 ms5 is reading out garbage calib and adc nums
2022-03-26 sd works now, needed to disable radio spi
2022-03-27 fixed no returns in do driver functions
    [main.cpp]
2022-03-27 no longer hard coding file name
    [main.cpp]
2022-03-28 zxct driver equations
2022-03-28 ms5 driver still doesnt work
2022-03-31 sd driver clears storage on start
2022-04-08 skellyton nin3
    [Skeleton_9.SLDPRT, metamold_upper.SLDPRT, metamold_upper.STL]
2022-04-08 updated moldz
    [Skeleton_9.SLDPRT, Skeleton_9.STL, final assembly.SLDASM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]
2022-04-20 fixed some mini bugs
    [main.cpp]
2022-04-21 trying alt driver
2022-04-21 using alt ms5 driver
2022-04-22 adding back state switch
2022-04-25 state machine code uncommented and pressure tolerance changed
    [main.cpp]
2022-04-29 Repo cleaning for submission
    Added missing reports, cleaned up structure, etc.
    [Bouancy Budget.xlsx, Expenses_BoM.xlsx, Final Testing Sheet Operations and Overview_.xlsx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]
2022-04-29 pretty heatmap
2022-04-29 removed pcb build files from git
    [Adafruit BH1750.brd, Adafruit BH1750.sch, Adafruit Feather M0 RFMxx.brd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]
2022-04-30 Charging Dock for PUCKFish, Potential 3D print
    [ChargingDock.step]
2022-05-06 sending to web client. currently freezing

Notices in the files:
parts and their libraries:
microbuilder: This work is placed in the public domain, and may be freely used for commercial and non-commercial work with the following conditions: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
